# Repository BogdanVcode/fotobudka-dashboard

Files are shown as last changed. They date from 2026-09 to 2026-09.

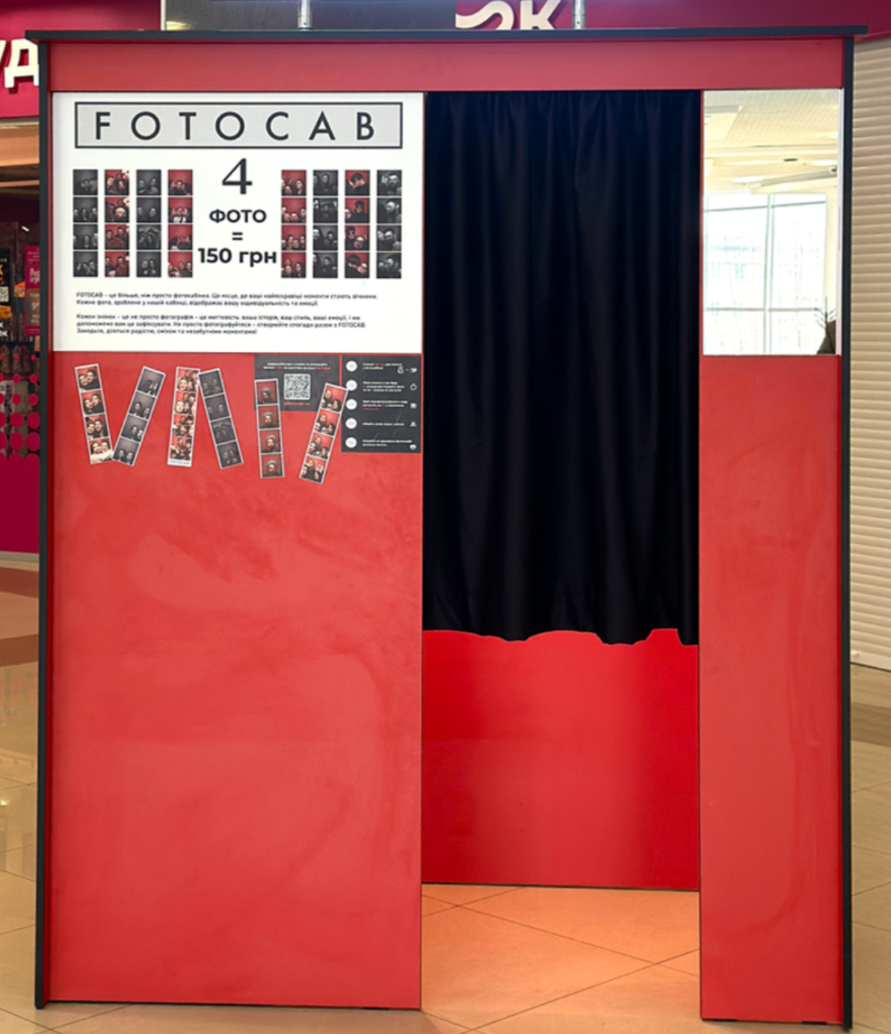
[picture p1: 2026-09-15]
assets/references/03-exterior.png

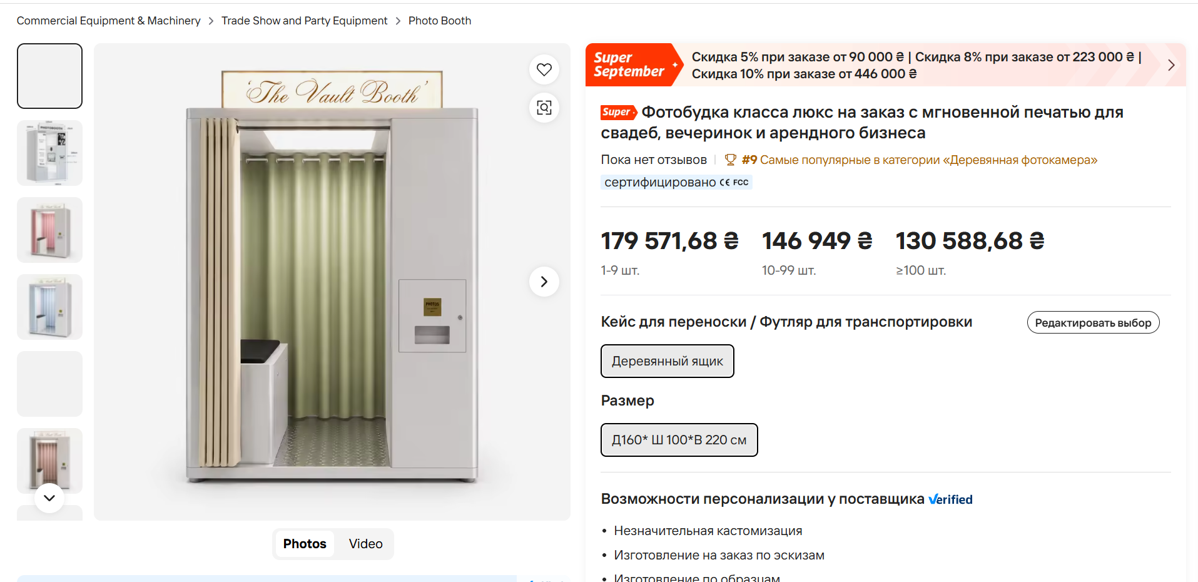
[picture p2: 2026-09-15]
assets/references/02-size.png

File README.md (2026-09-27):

# прототип 1 від чатгпт

Фотокіоск самообслуговування · Славутич.

[Відкрити дашборд](https://bogdanvcode.github.io/fotobudka-dashboard/) · [Інструкція для Claude](CLAUDE.md)

## Запуск

Потрібен Node.js 20+. Зовнішні пакети встановлювати не потрібно.

```sh
npm run build
npm test
npm start
```

Відкрити http://localhost:4173. GitHub Pages публікує корінь main.

Єдиний кошторис: `docs/budget/current.json`. Реєстр покупок: `docs/purchases/2026-09-25.json`. Персональні зміни браузера експортуються у вкладці «Кошторис».

`engineering-source/` та попередні ревізії — історія. Не використовувати старі окремі списки покупок. Поточні файли й обмеження описані в CLAUDE.md. Оригінал Blender і креслення збережені.

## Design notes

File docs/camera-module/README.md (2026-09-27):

# Вертикальний модуль камери · P2

ПК USB → Arduino Nano (USB 5 В), D2 STEP / D3 DIR → ULN2003 → DM556. D4 нижній HOME і D5 верхня межа: два HURON NPN NO через дві PC817/EL817. XL7015: 36 → 12 В для датчиків. Прошивки та фізичних випробувань немає.

CNCPROM: товари, доставка й комісії оплачені; комплект отримано 25.09.2026. Повна витрата 10 116,68 грн.

[Схема](PIN-WIRING.md) · [Актуальні покупки](PIN-PURCHASES.md) · [Інструменти](ASSEMBLY-SHOPPING.md) · [Архів P1](archive/P1-PIN-PURCHASES.md).

3D — умовне компонування двох індуктивних датчиків і мішені; координати їх кріплення не є виробничим кресленням. Прошивки й фізичного тестування немає.

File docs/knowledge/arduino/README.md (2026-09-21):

# Бібліотека знань Arduino: AlexGyver

Додано 20.09.2026. Автор першоджерел — AlexGyver. [Каталог уроків](https://alexgyver.ru/lessons/). Це локальний тематичний покажчик і власні короткі нотатки для фотобудки, а не копія сайту, його платного контенту чи програмна бібліотека, встановлена в Arduino IDE.

Переглянуто структуру каталогу та відкриті матеріали, потрібні для підключення Nano, живлення, GPIO, механічного HOME, Serial і неблокувальних таймерів. Увесь сайт і відеокурс не пройдено. Прямі посилання нижче дозволяють продовжити дослідження без повторного пошуку.

## Навігація

| Тема / першоджерело | Що зберігаємо як знання | Застосування в нашому модулі [C] |
|---|---|---|
| [Початок роботи](https://alexgyver.ru/lessons/ardu-start/) | Підготовка середовища та завантаження скетчу; вступний матеріал | Плата ATmega328P, правильний COM-порт; варіант bootloader перевіряємо на отриманій Nano |
| [Arduino Nano](https://alexgyver.ru/lessons/arduino-nano/) | Позначення D-пінів, живлення, інтерфейси класичної Nano | Не плутати D2 з фізичною ніжкою №2 ATmega; основний pinout звіряємо з Arduino |
| [Підключення модулів](https://alexgyver.ru/lessons/hardware/) | Макетування, контактні гребінки, сигнальні інтерфейси | Піни 2,54 мм — для сигналів усередині нерухомого відсіку |
| [Живлення](https://alexgyver.ru/lessons/arduino-power/) | Полярність, допустима напруга, живлення від USB, окреме живлення навантажень | USB живить Nano і сигнальну частину; S-250-36 живить лише силову частину DM556 |
| [Цифровий вихід](https://alexgyver.ru/lessons/gpio-out/) | GPIO перемикає логічний рівень; потужне навантаження потребує драйвера | D2/D3 → буфер ULN2003 → PUL/DIR; до GPIO не підключати обмотки |
| [Цифровий вхід](https://alexgyver.ru/lessons/gpio-in/) | Вхід не повинен залишатися без визначеного рівня; INPUT_PULLUP | D4 читає NC-контакт HOME; підтягування внутрішнє для першого стенда |
| [Кнопка](https://alexgyver.ru/lessons/button/) | Контакти, підтягування, обробка зміни стану й брязкоту | Наш кінцевик використовує NC, тому логіка натискання відрізняється від прикладу з NO-кнопкою |
| [UART / Serial](https://alexgyver.ru/lessons/uart/) | Апаратний і програмний UART, однакова швидкість на обох кінцях | ПК → USB-UART Nano; D0/D1 залишаємо для Serial, STEP генерується на MCU |
| [Програмний таймер](https://alexgyver.ru/lessons/soft-timer/) | Перевірка різниці часу дозволяє обходитися без блокувальних затримок | Окремі таймери HOME, зв’язку та стабілізації камери; це не готовий генератор STEP |
| [Використання бібліотек](https://alexgyver.ru/lessons/library-using/) | Довідкова сторінка про підключення бібліотек | Версію обраної бібліотеки руху та її розводку пінів зафіксувати під час розробки прошивки |

## Як користуватися знаннями

1. Для загальних понять починати з відповідного уроку.
2. Для чисел, контактів і сумісності переходити до документації **конкретної моделі та ревізії**. Навчальний приклад не підтверджує сумісність нашого комплекту.
3. Проєктні рішення зберігати в MASTER-SPEC і документах модуля, не приписувати їх AlexGyver.
4. Після заміни плати повторно звіряти маркування, роз’єм і рівні сигналів. Відкрита стаття може змінитися.

## Уточнення для нашої схеми

- [C] Спільна земля потрібна між Nano та ULN2003. У запропонованому оптоізольованому інтерфейсі **окрему перемичку Nano GND → DM556 силовий GND не додаємо**. Загальне навчальне правило про GND не означає необхідність обходити оптоізоляцію.
- [C] HIGH на D2 відкриває колектор ULN2003 і створює струм у вході PUL; це не звичайний push-pull вихід 5 В. Треба перевірити напругу/струм оптовходу з реальним USB-живленням і падінням на ULN.
- [C] Розрив NC-кола дає такий самий рівень, як натиснутий HOME. Лише читання HIGH не є доказом знайденого нуля. Потрібна контрольована послідовність відпускання й повторного натискання з тайм-аутами.
- [C] Внутрішнє INPUT_PULLUP — стартовий варіант для короткого кабелю стенда. Якщо на довгому кабелі виникають завади, потрібна окрема ревізія входу з підтягуванням/фільтрацією; не маскувати їх лише великою програмною затримкою.

## Першоджерела для перевірки контактів

- [Arduino Nano, офіційна розпіновка](https://docs.arduino.cc/resources/pinouts/A000005-full-pinout.pdf) [A].
- [TI ULN2003A, datasheet](https://www.ti.com/lit/ds/symlink/uln2003a.pdf), таблиця Pin Functions [A].
- [Схема плати ULN2003 LC Studio від продавця](https://arduino.ua/docs/SCH_StepperDriverULT2003.pdf) [B]; фактична плата може мати іншу ревізію.
- [DM556, інструкція саме з картки CNCPROM](https://storage.ua.prom.st/2369996_drajver_dm556._posibnik_koristuvacha.pdf), с. 4–6, 9 [B]. Це не доказ, що недорогий DM556 є оригінальним Leadshine.

[Нова схема та монтаж](../../camera-module/PIN-WIRING.md) · [Закупівля](../../camera-module/PIN-PURCHASES.md)

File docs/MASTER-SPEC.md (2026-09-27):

<!-- PROTOTYPE-1 -->
# прототип 1 від чатгпт

27.09.2026: актуальний кошторис — docs/budget/current.json; збірка — scripts/build-budget.mjs. Реєстр оплат — docs/purchases/2026-09-25.json. Усі інструменти є; історія витрат збережена. Старі окремі списки архівні. P2 — невипробуваний кандидат з відкритим питанням STEP/DIR. Передача проєкту — CLAUDE.md. Нижче — історичні розділи, що не перевизначають цей блок.
<!-- /PROTOTYPE-1 -->

<!-- P2-CANONICAL-20260921 -->
## Єдина актуальна схема ліфта P2 · комплект CNCPROM отримано

Джерело комплектації та статусів — `camera-module/order.json`, wiringRevision=P2. [Покупки](camera-module/PIN-PURCHASES.md), [схема](camera-module/PIN-WIRING.md). Один NC HOME, його джгут і список P1 перенесено в `camera-module/archive/`; вони не беруть участі в поточному кошторисі. Два HURON NPN NO: D4 HOME, D5 верхня межа через дві PC817/EL817; XL7015 36→12 В. D2/D3 через ULN2003 до DM556; Nano від USB.

CNCPROM №428971860 оплачено й отримано: товари 9 587 грн, доставка 270 грн, комісії 259,68 грн, повна витрата 10 116,68 грн. Загальний factual spent станом на 25.09.2026 — 106 932,34 грн; логістика й комісії — 1 248,67 грн. Master-реєстр покупок — `purchases/2026-09-25.json`; доставка зберігається на рівні замовлення і не дублюється між товарами. Апаратні випробування і прошивка не виконані.

<!-- ASSEMBLY-SHOPPING-20260921 -->
## Інструменти та монтаж · 21.09.2026 · уточнення

[Список і вибір покупки](camera-module/ASSEMBLY-SHOPPING.md), джерело `camera-module/assembly-shopping.json`. Вісім інструментів виключено за рішенням Богдана; решта 3 976 грн до позначок «Позичу». Дашборд зберігає вибір локально та формує замовлення за магазинами. Це план, не куплені товари. DFR0912 відхилено за ціною: залишено дві PC817/EL817 з P2 (144 грн, не дублювати). Bulgin замінено на ETI ESC-SFR.4: пара 192,80 грн плюс кришка, рейка й упори; складові монтажу разом 234 грн без запобіжників. ABS-бокс 300×400×170 з монтажною панеллю за 1 200 грн відкладено до перевірки компонування. Мережева частина, F0, кожух, вентиляція й монтаж залишаються незавершеними. Не оголошувати комплект готовим до ввімкнення.

<!-- PIN-WIRING-P2 -->
## Підключення пінами · P2 · 21.09.2026

[Схема і монтаж](camera-module/PIN-WIRING.md) · [Закупівля у двох основних магазинах](camera-module/PIN-PURCHASES.md) · [Бібліотека Arduino / AlexGyver](knowledge/arduino/README.md). Чинна схема P2: D2 STEP, D3 DIR через ULN2003, D4 нижній HOME, D5 верхня межа. Два NPN NO через дві опторозв’язки; XL7015 знижує 36 до 12 В. Статус CANDIDATE; розводка оптоплат, X2, запобіжники й стенд не перевірені. Закупівля P1 архівна; актуальний order.json та список закупівлі відповідають P2.

<!-- CAMERA-MODULE-700 -->
## Нове ТЗ модуля камери · 20.09.2026

[Інженерний огляд і 3D](camera-module/README.md): TBD45-700 замість попереднього 500 мм для нового вузла. Окреме компонування, не виробничий випуск. Авторську геометрію кабінки не змінено; інтеграція 700 мм і механічне утримання ще не погоджені.

<!-- CURRENT-REVISION-10 -->
# Актуальна ревізія 10 · 17.09.2026

[Модель, кошторис і прибутковість](design/REVISION-10.md). Попередні записи нижче — історія.
<!-- END-CURRENT-10 -->

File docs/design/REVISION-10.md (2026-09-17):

# Ревізія 10 · модель Богдана від 17.09.2026

Джерело: БУДКА.blend. SHA256: 2b8f48152970a00ad30e395a091eca47b85e14f904886c514a4f78d67ea8b577. Усі 73 авторські конструктивні об’єкти збережені: вершини, повороти, Dimensions, нові назви та колекції. Колекція «Каркас» містить 44 профілі 20×20, сумарно 37,561 м. Об’єкт «людина» — масштабний референс, у дашборді не показаний.

## Розміщення

Два принтери DNP DS-RX1HS і Brother HL-L5210DN стоять на авторській деталі «ДСП для принтерів всередині». Їхні нижні площини точно збігаються з верхом полиці. Godox MS200V розміщений ліворуч від камери, якщо дивитися з пуфіка на монітор, спрямований угору. EcoFlow та комп’ютер — в самому низу. Сканер Brother DS-740D — за верхнім вирізом передньої ДСП: авторський об’єкт «Сканер Brother DS-740D White», Dimensions 301×63×45,3 мм, без переміщення. Нижче — авторська кишеня. Напрям подачі та виходу документа і його потрапляння в кишеню потребують перевірки на реальному сканері. Авторський платіжний термінал, камера спостереження, кишені та рифлений лист збережені.

Додано муфту, монтажні опори й маршрути проводів: принтери, сканер, монітор, камера, термінал, камера спостереження, концентратор USB і розподіл живлення. Маршрути схематичні: реальні порти, інтерфейс термінала, кабельний ланцюг і електрична схема залишаються роботою автора електроніки.

## Креслення

Альбом drawings/revision-10/index.html; PDF output/pdf/Фотобудка-10-креслення.pdf. Шість аркушів А1: усі 15 об’єктів ДСП на одному аркуші; усі профілі на окремому; компонування; вирізи; світлові панелі; порядок складання. Сітка меша не використовується як креслення. Для плоских деталей показано контур поверхні, габарити й розміри вирізів.

Передній об’єкт з кишенями має глибину 200,58 мм і є збірним вузлом. Це не плита такої товщини. Дверцята мають 16 мм, консоль — габарит 15,86 мм, верхня похила опалова панель — 5,33 мм. Ці величини не змінені без рішення автора. На реальних плоских матеріалах потрібна деталізація майстром.

## Завдання майстру

Зібрати міцний каркас 20×20 і обшивку ДСП; вмонтувати пуфік, екран, сканер і опалові полікарбонатні панелі; зробити вирізи та приховані кріплення. Зовнішні стінки з’єднати між собою і з каркасом без видимих наскрізних гвинтів. Усередині модуля допускаються технологічні вирізи. Богдан окремо закуповує й робить обладнання, електроніку та ПЗ.

## Кошторис

72 оцінених позицій, сума 392260.24 грн, резерв 10% — 39226.02 грн, загалом 431486.26 грн. Ціни пропозицій, середні орієнтири та резерви на роботи позначені окремо у budget.json. Невідомих цін без оцінки немає; це не договірна ціна.

Каркас: V-Slot 20×20 без покриття Profile Center, 187 грн/м; резерв 7 хлистів по 6 м. 100 комплектів кутника 2028 по 68 грн (кутник + 2 болти + 2 T-гайки). Це запас за кількістю торців, не остаточна схема з’єднань; косі стики і міцність перевіряє майстер. Екран: Elo 2470L 24 дюйми з авторського Blender; 28850 грн — середнє двох пропозицій, не підтвердження наявності.

## Прибутковість

Калькулятор #profit враховує кількість і ціну послуг, витратні матеріали, повторний друк, податки 2026 року, комісію еквайрингу, оренду, електрику та інші витрати. Усі припущення редагуються. Оренда за замовчуванням — максимум 2,5 м² × 250 грн та 3000 грн/місяць. Це сценарій, не отримана пропозиція ТЦ. Податки 2 групи за максимальною ставкою; 3 група без ПДВ — 5% + 1% від повної виручки, плюс ЄСВ. Депозит і грошовий запас збільшують початкові вкладення. Немає додатного залишку — немає строку окупності. Джерела ДПС та оренди наведені на вкладці.

## Перевірка й межі

Перевірено незмінність усіх авторських мешів і Dimensions, опирання принтерів на полицю, розташування спалаху/сканера й нижнього обладнання. Повний розрахунок жорсткості, присадка, вентиляційні зазори й тракти видачі від принтерів до кишень ще не випущені. Габарити камери, ліфта, термінала у файлі автора умовні: не приймати їх як заводські CAD-розміри. productionReleased=false.

## Уточнення моделі о 13:44

Нова авторська модель містить 73 конструктивні меші. Нові назви збережені. Доданий автором прилад названо «Сканер Brother DS-740D White»; додатковий дубль сканера видалено. Два принтери DNP і Brother A4 залишаються доданими на авторській полиці. Прохід у «ДСП перед» — 600 мм між X=−436 та X=164 мм. Рифлений лист: 600×1000×16 мм у Blender; 16 мм — модельний габарит, кошторисний метал 1,5 мм потребує опорної основи. Кишеньковий вузол тепер має глибину 200,58 мм.

## Вхід і розміри вирізів

Прив’язки вирізів X/Y і їхня ширина/висота нанесені на види аркуша 04; окремий аркуш 07 вилучено з альбому. Штора: готова біла 140×200 см, підшити до 181 см, у складках перекриває 70 см. Карниз 100 см з 12 бігунками/гачками, двома стопорами, трьома кронштейнами та кріпленням до підсиленої перемички. Монтаж показано як пропозицію; перевірити кріплення на місці. Резерв: штора 2200 грн + комплект карниза 700 грн; ці позиції вже були у сумі, дубль не додано.

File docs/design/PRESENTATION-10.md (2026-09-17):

# Потрібен майстер зі складання фотокіоска · Славутич

Фотокіоск самообслуговування: людина сідає, обирає послугу на екрані, фотографується й отримує фотографії. Сканер дозволяє сканувати документи та друкувати копії.

Зараз потрібне виготовлення каркаса з алюмінієвого профілю 20×20 та обшивки ДСП: порізка, вирізи, прихований монтаж стінок, вбудований пуфік, кріплення екрана, сканера, кишень і опалових панелей. Усередині модуля допустимі технологічні вирізи.

Богдан — автор проєкту — окремо займається закупівлею обладнання, електронікою і ПЗ. Майстру потрібно перевірити конструкцію, запропонувати кріплення та оцінити складання й монтаж.

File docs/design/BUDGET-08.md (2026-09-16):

# Кошторис авторської моделі

Ціни обладнання з попередньої ревізії збережені в dashboard/budget.js із датами й посиланнями. Ціни не перевірялися повторно в межах імпорту Blender. Матеріали та роботи корпусу необхідно перерахувати після погодження товщини дверцят, плоских панелей, крайки та присадки. Повної нової суми немає; старий підсумок не застосовується до ревізії 08.

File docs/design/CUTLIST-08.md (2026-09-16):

# Авторські панелі · 08

Розміри взяті з Dimensions. Товщини й присадку погодити до замовлення.

| ID | Об’єкт | Dimensions, мм |
|---|---|---|
| B044 | ЗАД | 1072.00 × 2200.00 × 16.00 |
| B045 | верх | 1800.00 × 1200.00 × 16.00 |
| B046 | перед | 1072.00 × 2200.00 × 16.00 |
| B047 | ліво | 1640.00 × 2200.00 × 16.00 |
| B048 | підлога | 1672.00 × 1072.00 × 16.00 |
| B049 | ЗАД.001 | 594.01 × 1219.06 × 8.87 |
| B050 | ДСП перед | 1640.00 × 2200.00 × 16.00 |
| B057 | дсп1 | 1040.00 × 500.00 × 16.00 |
| B058 | дсп1.001 | 1000.00 × 400.00 × 16.00 |
| B059 | дсп1.002 | 1000.00 × 400.00 × 16.00 |
| B060 | дсп1.003 | 400.00 × 400.00 × 16.00 |
| B061 | дсп1.004 | 400.00 × 400.00 × 16.00 |
| B062 | дсп2 для монітора | 1040.00 × 498.21 × 15.86 |

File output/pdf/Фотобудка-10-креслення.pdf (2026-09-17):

# 01 · Усі деталі ДСП на одному аркуші

Суцільні контури актуальних деталей. Показані габарити, товщина та основні розміри вирізів; сітка меша прихована.

ФОТОБУДКА СЛАВУТИЧ · 10 · 17.09.2026 · мм · А1 · не масштабувати з екрана | Автор: Богдан · комплект для узгодження з майстром

B051 · ДСП ЗАД

Dimensions: 1072 × 2200 × 16 мм

1072

2200

181 | 710 | 181
| | 187

1210

803

Товщина / габарит торця: 16 мм

B052 · ДСП верх

Dimensions: 1800 × 1200 × 16 мм

1800

1200

Товщина / габарит торця: 16 мм

B053 · ДСП перед.001

Dimensions: 1072 × 2200 × 16 мм

1072

2200

Товщина / габарит торця: 16 мм

B054 · ДСП ліво

Dimensions: 1640 × 2200 × 16 мм

1640

2200

Товщина / габарит торця: 16 мм

B055 · підлога Dimensions: 1672 × 1072 × 16 мм | B056 · ДСП перед Dimensions: 1640 × 2200 × 16 мм | B059 · ЗАД сервісний люк Dimensions: 700 × 1200 × 16 мм 700 | B065 · дсп перед з віконцями для друкованих матеріалів Dimensions: 1040 × 500 × 200.58 мм
| | 280.01 15.8

1672

1072

418 | 418 | 418 | 209 | 209

Товщина / габарит торця: 16 мм

1640

2200

600

1904.19

Товщина / габарит торця: 16 мм

1200

Товщина / габарит торця: 16 мм

1040

500

Вузол з кишенями; 200.58 мм — глибина.

B066 · ДСП пуфік лицьова

Dimensions: 1000 × 400 × 16 мм

1000

400

Товщина / габарит торця: 16 мм

B067 · ДСП пуфік задня стінка

Dimensions: 1000 × 400 × 16 мм

1000

400

Товщина / габарит торця: 16 мм

B068 · ДСП пуфік ліво

Dimensions: 400 × 400 × 16 мм

400

400

Товщина / габарит торця: 16 мм

B069 · ДСП пуфік право

Dimensions: 400 × 400 × 16 мм

400

400

Товщина / габарит торця: 16 мм

B070 · дсп2 для монітора Dimensions: 1040 × 498.21 × 15.86 мм | B072 · ДСП для принтерів всередині Dimensions: 1000 × 400 × 16 мм | B073 · ДСП для ліфта камери Dimensions: 150 × 300 × 16 мм
| | 92.28 74.52

1040

498.21

242.68 | 553.7 | 243.62

165.7

8.88

156.83

Товщина / габарит торця: 15.86 мм

1000

400

Товщина / габарит торця: 16 мм

150

300

Товщина / габарит торця: 16 мм

# 02 · Усі деталі каркаса: алюмінієвий профіль 20×20

Колекція «Каркас» у Blender. Кожен Cube — окремий профіль. Довжина за Dimensions, не за світовим габаритом.

B007 · Cube.005 | L = 1000 мм

20 × 20 мм

B008 · Cube.006 | L = 1000 мм

20 × 20 мм

B009 · Cube.007 | L = 1000 мм

20 × 20 мм

B010 · Cube.008 | L = 2200 мм

20 × 20 мм

B011 · Cube.009 | L = 2200 мм

20 × 20 мм

B012 · Cube.011 | L = 280 мм

20 × 20 мм

B013 · Cube.012 | L = 280 мм

20 × 20 мм

B014 · Cube.013 | L = 1600 мм

20 × 20 мм

B015 · Cube.021 | L = 500 мм

20 × 20 мм

B016 · Cube.023 | L = 1000 мм

20 × 20 мм

B017 · Cube.024 | L = 1000 мм

20 × 20 мм

B018 · Cube.025 | L = 1600 мм

20 × 20 мм

B019 · Cube.015 | L = 1900 мм

20 × 20 мм

B020 · Cube.018 | L = 339.58 мм

20 × 20 мм

B021 · Cube.022 | L = 220.42 мм

20 × 20 мм

B022 · Cube.026 | L = 339.58 мм

20 × 20 мм

B023 · Cube.028 | L = 339.58 мм

20 × 20 мм

B024 · Cube.029 | L = 484.87 мм

20 × 20 мм

B025 · Cube.030 | L = 1000 мм

20 × 20 мм

B026 · Cube.031 | L = 1000 мм

20 × 20 мм

B027 · Cube.020 | L = 580 мм

20 × 20 мм

B028 · Cube.032 | L = 1600 мм

20 × 20 мм

B029 · Cube.034 | L = 500 мм

20 × 20 мм

B030 · Cube.035 | L = 1900 мм

20 × 20 мм

B031 · Cube.036 | L = 339.58 мм

20 × 20 мм

B032 · Cube.037 | L = 220.42 мм

20 × 20 мм

B033 · Cube.038 | L = 339.58 мм

20 × 20 мм

B034 · Cube.039 | L = 339.58 мм

20 × 20 мм

B035 · Cube.040 | L = 484.87 мм

20 × 20 мм

B036 · Cube.041 | L = 580 мм

20 × 20 мм

B037 · Cube.042 | L = 1600 мм

20 × 20 мм

B038 · Cube.014 | L = 1000 мм

20 × 20 мм

B039 · Cube.045 | L = 1000 мм

20 × 20 мм

B040 · Cube.046 | L = 1000 мм

20 × 20 мм

B041 · Cube.001 | L = 1000 мм

20 × 20 мм

B042 · Cube.002 | L = 1000 мм

20 × 20 мм

B043 · Cube.016 | L = 1000 мм

20 × 20 мм

B044 · Cube.017 | L = 1000 мм

20 × 20 мм

B045 · Cube.044 | L = 572.26 мм

20 × 20 мм

B046 · Cube.049 | L = 572.26 мм

20 × 20 мм

B047 · Cube.003 | L = 484.87 мм

20 × 20 мм

B048 · Cube.004 | L = 484.87 мм

20 × 20 мм

B049 · Cube.019 | L = 339.58 мм

20 × 20 мм

B050 · Cube.027 | L = 339.58 мм

20 × 20 мм

44 деталей · загальна довжина: 37.56 м. Торці похилих елементів різати за кутом їхніх стиків; кріплення узгоджує майстер.

# 03 · Загальне компонування та висоти

Напрямок «ліворуч / праворуч» визначено з місця людини, яка дивиться на монітор.

## Вид збоку: лавка → модуль

1672

## Вид на модуль: сканер у верхньому вирізі

1074.58

Полиця принтерів: верх 524 мм від авторської площини Z=0. Принтери стоять на ній; EcoFlow і ПК — на нижній основі Z=8.

Кишеня A4 ліворуч, фото по центру — авторська геометрія. Тракти видачі від принтерів до кишень ще потрібно виготовити й перевірити.

Прохід фасаду: 600 мм між X = −436 та +164 мм. Рифлений лист: 600 × 1000 мм (Dimensions автора).

# 04 · Вирізи, кишеньки й сервісний люк

Збільшені головні види. Передній вузол має кишені; їхня глибина не є товщиною ДСП. Вентиляційні прорізи збережені з моделі.

B059 · ЗАД сервісний люк

Dimensions: 700 × 1200 × 16 мм

700

1200

ВИРІЗИ: X / Y від нижнього лівого кута; ширина × висота

1

190.91

28.57

1: X 487.88

1: Y 1142.86

1. Ліворуч 487.88; знизу 1142.86; виріз 190.91 × 28.57 мм

2

190.91

28.57

2: X 487.88

2: Y 1085.71

2. Ліворуч 487.88; знизу 1085.71; виріз 190.91 × 28.57 мм

3

190.91

28.57

3: X 487.88

3: Y 1028.57

3. Ліворуч 487.88; знизу 1028.57; виріз 190.91 × 28.57 мм

4

21.21

28.57

4: X 657.58

4: Y 628.57

4. Ліворуч 657.58; знизу 628.57; виріз 21.21 × 28.57 мм

5

190.91

28.57

5: X 487.88

5: Y 142.86

5. Ліворуч 487.88; знизу 142.86; виріз 190.91 × 28.57 мм

6

190.91

28.57

6: X 487.88

6: Y 85.71

6. Ліворуч 487.88; знизу 85.71; виріз 190.91 × 28.57 мм

7

190.91

28.57

7: X 487.88

7: Y 28.57

7. Ліворуч 487.88; знизу 28.57; виріз 190.91 × 28.57 мм

B065 · дсп перед з віконцями для друкованих матеріалів

Dimensions: 1040 × 500 × 200.58 мм

1040

500

ВИРІЗИ: X / Y від нижнього лівого кута; ширина × висота

1

244.71

35.71

1: X 61.18

1: Y 428.57

1. Ліворуч 61.18; знизу 428.57; виріз 244.71 × 35.71 мм

2

244.71

107.14

2: X 61.18

2: Y 107.14

2. Ліворуч 61.18; знизу 107.14; виріз 244.71 × 107.14 мм

3

183.53

71.43

3: X 428.24

3: Y 107.14

3. Ліворуч 428.24; знизу 107.14; виріз 183.53 × 71.43 мм

4

244.71

35.71

4: X 734.12

4: Y 107.14

4. Ліворуч 734.12; знизу 107.14; виріз 244.71 × 35.71 мм

B070 · дсп2 для монітора

Dimensions: 1040 × 498.21 × 15.86 мм

1040

498.21

ВИРІЗИ: X / Y від нижнього лівого кута; ширина × висота

1

553.7

331.4

1: X 242.68

1: Y 74.52

1. Ліворуч 242.68; знизу 74.52; виріз 553.7 × 331.4 мм

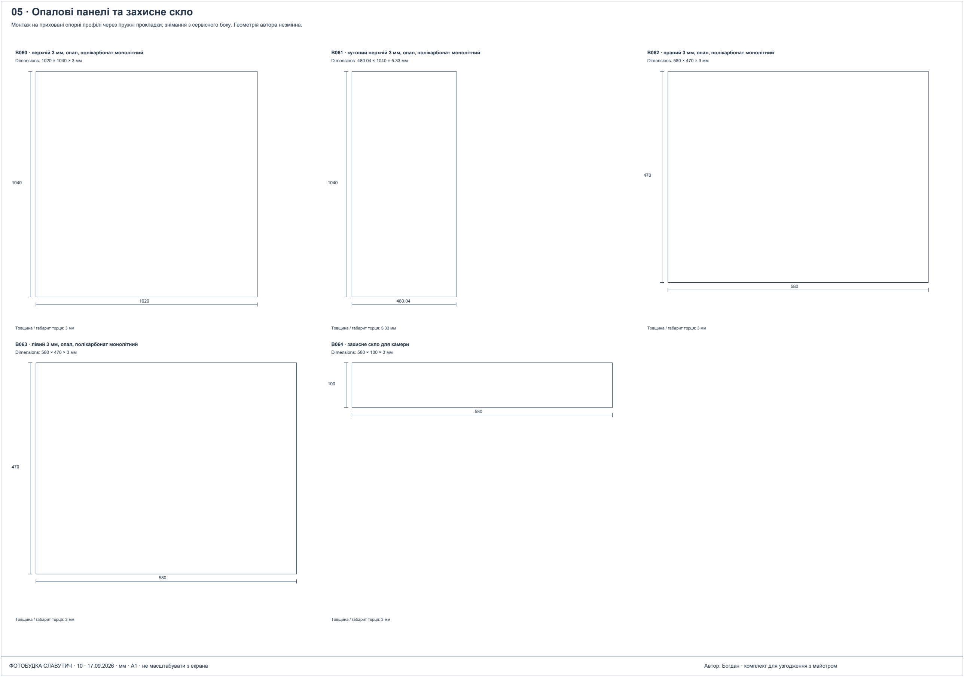
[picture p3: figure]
05 · Опалові панелі та захисне скло; Dimensions: 1020 × 1040 × 3 мм; Товщина / габарит торця: 3 мм; Dimensions: 480.04 × 1040 × 5.33 мм; Товщина / габарит торця: 5.33 мм; Dimensions: 580 × 470 × 3 мм; B064 · захисне скло для камери; Dimensions: 580 × 100 × 3 мм

Монтаж на приховані опорні профілі через пружні прокладки; знімання з сервісного боку. Геометрія автора незмінна.

B060 · верхній 3 мм, опал, полікарбонат монолітний

B061 · кутовий верхній 3 мм, опал, полікарбонат монолітний

B062 · правий 3 мм, опал, полікарбонат монолітний

B063 · лівий 3 мм, опал, полікарбонат монолітний

# 06 · Завдання майстру: складання та прихований монтаж

Видимі зовнішні площини без наскрізних головок гвинтів. Спосіб прихованого кріплення узгодити перед свердлінням.

# 1. Перевірка заготовок

Звірити відомості ДСП і профілю з Blender. Передню деталь з кишенями деталізувати як збірний вузол.

# 2. Каркас 20×20

Виставити основу, стійки та перемички. Перевірити діагоналі й жорсткість. З’єднання розміщувати зсередини.

# 3. Пуфік і полиці

Закріпити пуфік у каркасі, опору сидіння й авторську полицю принтерів; перевірити навантаження.

# 4. Обшивка ДСП

З’єднати стінки прихованими стяжками та закріпити до каркаса внутрішніми кронштейнами. Погодити крайку й зазори.

# 5. Екран, сканер і опалові панелі

Виконати вирізи, знімні кріплення екрана, панелей та сканера. Усередині модуля допустимі технологічні вирізи.

# 6. Сервіс і кишеньки

Забезпечити доступ до принтерів, ПК і EcoFlow. Узгодити відкривання люка й вихід паперу в обидві кишені.

# 7. Кабелі й приймання

Передбачити муфти та місця для фіксації кабелів. Перевірити гострі краї, міцність і можливість обслуговування.

# Відповідальність автора

Богдан окремо закуповує обладнання, виконує електроніку та програмне забезпечення. Потрібна допомога зі складанням корпусу.

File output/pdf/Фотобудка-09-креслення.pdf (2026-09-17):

# 01 · Усі деталі ДСП на одному аркуші

Суцільні контури актуальних деталей. Показані габарити, товщина та основні розміри вирізів; сітка меша прихована.

ФОТОБУДКА СЛАВУТИЧ · 09 · 17.09.2026 · мм · А1 · не масштабувати з екрана | Автор: Богдан · комплект для узгодження з майстром
B050 · ЗАД Dimensions: 1072 × 2200 × 16 мм | B051 · верх Dimensions: 1800 × 1200 × 16 мм | B052 · перед Dimensions: 1072 × 2200 × 16 мм | B053 · ліво Dimensions: 1640 × 2200 × 16 мм
| | 862.59 111.88

1072

2200

237.42 | 597.16 | 237.42

1225.53

Товщина / габарит торця: 16 мм

1800

1200

Товщина / габарит торця: 16 мм

1072

2200

Товщина / габарит торця: 16 мм

1640

2200

Товщина / габарит торця: 16 мм

B054 · підлога Dimensions: 1672 × 1072 × 16 мм | B055 · ЗАД. сервісний люк Dimensions: 594.01 × 1219.06 × 8.87 мм | B056 · ДСП перед Dimensions: 1640 × 2200 × 16 мм | B064 · дсп перед з віконцями для друкованих матеріалів Dimensions: 1040 × 500 × 162.28 мм
| | 280.01 15.8

1672

1072

418 | 418 | 418 | 209 | 209

Товщина / габарит торця: 16 мм

594.01

1219.06

297.01 137.31137.31 22.38

Товщина / габарит торця: 8.87 мм

1640

2200

419.83 584.17 11.99 623.89

1904.19

Товщина / габарит торця: 16 мм

1040

500

Об’ємний вузол з кишенями; 162 мм — глибина.

B065 · ДСП пуфік лицьова

Dimensions: 1000 × 400 × 16 мм

1000

400

Товщина / габарит торця: 16 мм

B066 · ДСП пуфік задня стінка

Dimensions: 1000 × 400 × 16 мм

1000

400

Товщина / габарит торця: 16 мм

B067 · ДСП пуфік ліво

Dimensions: 400 × 400 × 16 мм

400

400

Товщина / габарит торця: 16 мм

B068 · ДСП пуфік право

Dimensions: 400 × 400 × 16 мм

400

400

Товщина / габарит торця: 16 мм

B069 · дсп2 для монітора Dimensions: 1040 × 498.21 × 15.86 мм | B071 · ДСП для принтерів всередині Dimensions: 1000 × 400 × 16 мм | B072 · ДСП для ліфта камери Dimensions: 150 × 300 × 16 мм
| | 92.28 74.52

1040

498.21

242.68 | 553.7 | 243.62

165.7

8.88

156.83

Товщина / габарит торця: 15.86 мм

1000

400

Товщина / габарит торця: 16 мм

150

300

Товщина / габарит торця: 16 мм

# 02 · Усі деталі каркаса: алюмінієвий профіль 20×20

Колекція «Каркас» у Blender. Кожен Cube — окремий профіль. Довжина за Dimensions, не за світовим габаритом.

B006 · Cube.005 | L = 1000 мм

20 × 20 мм

B007 · Cube.006 | L = 1000 мм

20 × 20 мм

B008 · Cube.007 | L = 1000 мм

20 × 20 мм

B009 · Cube.008 | L = 2200 мм

20 × 20 мм

B010 · Cube.009 | L = 2200 мм

20 × 20 мм

B011 · Cube.011 | L = 280 мм

20 × 20 мм

B012 · Cube.012 | L = 280 мм

20 × 20 мм

B013 · Cube.013 | L = 1600 мм

20 × 20 мм

B014 · Cube.021 | L = 500 мм

20 × 20 мм

B015 · Cube.023 | L = 1000 мм

20 × 20 мм

B016 · Cube.024 | L = 1000 мм

20 × 20 мм

B017 · Cube.025 | L = 1600 мм

20 × 20 мм

B018 · Cube.015 | L = 1900 мм

20 × 20 мм

B019 · Cube.018 | L = 339.58 мм

20 × 20 мм

B020 · Cube.022 | L = 220.42 мм

20 × 20 мм

B021 · Cube.026 | L = 339.58 мм

20 × 20 мм

B022 · Cube.028 | L = 339.58 мм

20 × 20 мм

B023 · Cube.029 | L = 484.87 мм

20 × 20 мм

B024 · Cube.030 | L = 1000 мм

20 × 20 мм

B025 · Cube.031 | L = 1000 мм

20 × 20 мм

B026 · Cube.020 | L = 580 мм

20 × 20 мм

B027 · Cube.032 | L = 1600 мм

20 × 20 мм

B028 · Cube.034 | L = 500 мм

20 × 20 мм

B029 · Cube.035 | L = 1900 мм

20 × 20 мм

B030 · Cube.036 | L = 339.58 мм

20 × 20 мм

B031 · Cube.037 | L = 220.42 мм

20 × 20 мм

B032 · Cube.038 | L = 339.58 мм

20 × 20 мм

B033 · Cube.039 | L = 339.58 мм

20 × 20 мм

B034 · Cube.040 | L = 484.87 мм

20 × 20 мм

B035 · Cube.041 | L = 580 мм

20 × 20 мм

B036 · Cube.042 | L = 1600 мм

20 × 20 мм

B037 · Cube.014 | L = 1000 мм

20 × 20 мм

B038 · Cube.045 | L = 1000 мм

20 × 20 мм

B039 · Cube.046 | L = 1000 мм

20 × 20 мм

B040 · Cube.001 | L = 1000 мм

20 × 20 мм

B041 · Cube.002 | L = 1000 мм

20 × 20 мм

B042 · Cube.016 | L = 1000 мм

20 × 20 мм

B043 · Cube.017 | L = 1000 мм

20 × 20 мм

B044 · Cube.044 | L = 572.26 мм

20 × 20 мм

B045 · Cube.049 | L = 572.26 мм

20 × 20 мм

B046 · Cube.003 | L = 484.87 мм

20 × 20 мм

B047 · Cube.004 | L = 484.87 мм

20 × 20 мм

B048 · Cube.019 | L = 339.58 мм

20 × 20 мм

B049 · Cube.027 | L = 339.58 мм

20 × 20 мм

44 деталей · загальна довжина: 37.56 м. Торці похилих елементів різати за кутом їхніх стиків; кріплення узгоджує майстер.

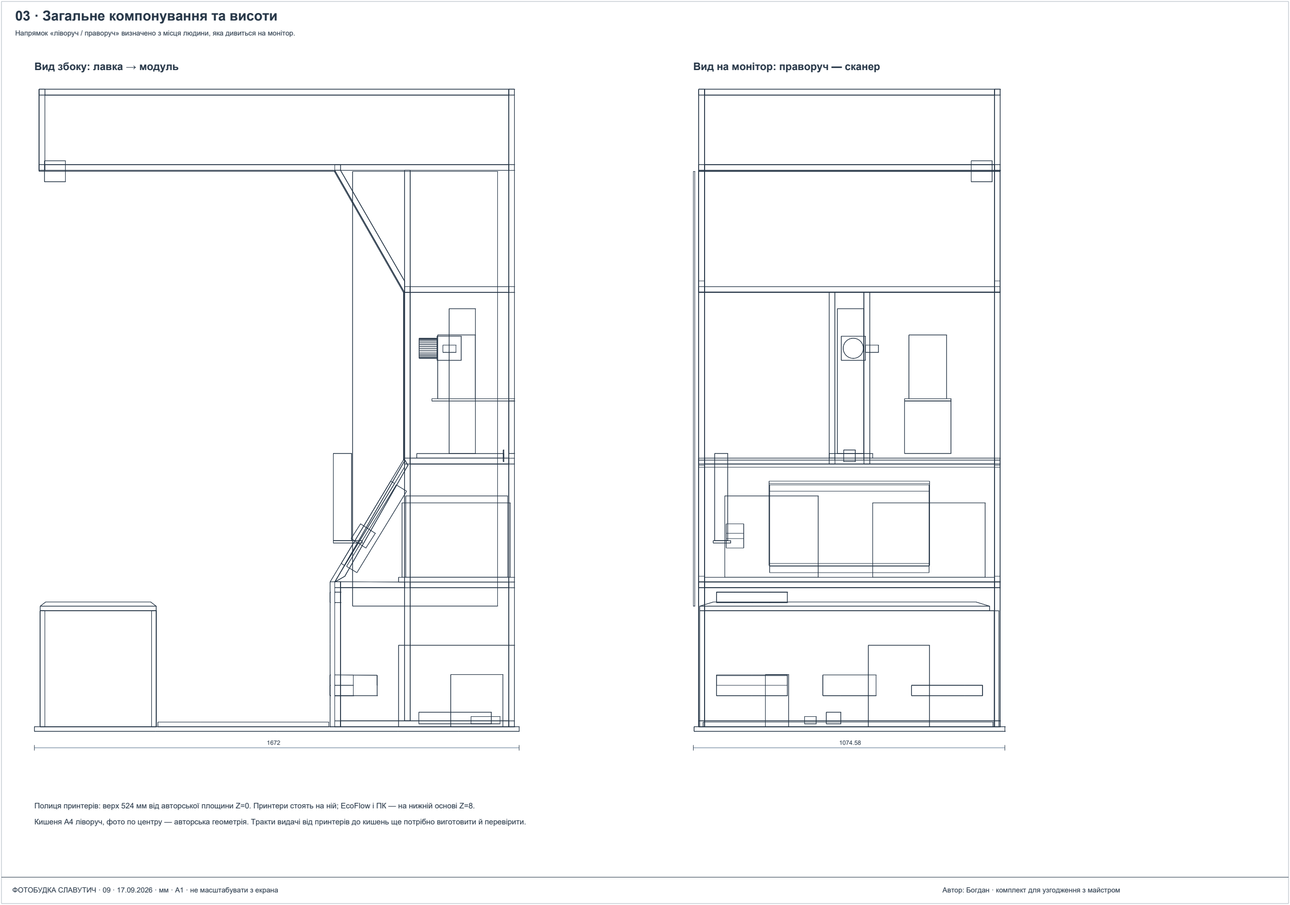
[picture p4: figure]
03 · Загальне компонування та висоти; Вид збоку: лавка → модуль; Вид на монітор: праворуч — сканер

Напрямок «ліворуч / праворуч» визначено з місця людини, яка дивиться на монітор.

Полиця принтерів: верх 524 мм від авторської площини Z=0. Принтери стоять на ній; EcoFlow і ПК — на нижній основі Z=8.

Кишеня A4 ліворуч, фото по центру — авторська геометрія. Тракти видачі від принтерів до кишень ще потрібно виготовити й перевірити.

# 04 · Вирізи, кишеньки й сервісний люк

Збільшені головні види. Передній вузол має кишені; їхня глибина не є товщиною ДСП. Вентиляційні прорізи збережені з моделі.

B055 · ЗАД. сервісний люк

Dimensions: 594.01 × 1219.06 × 8.87 мм

594.01

1219.06

297.01 | 137.31 | 137.31 | 22.38

Товщина / габарит торця: 8.87 мм

ВИРІЗИ: X / Y від нижнього лівого кута; ширина × висота

1. X 434.32 / Y 108.84; 137.31 × 21.77 мм
2. X 434.32 / Y 1175.52; 137.31 × 21.77 мм
3. X 434.32 / Y 1044.91; 137.31 × 21.77 мм
4. X 434.32 / Y 1088.44; 137.31 × 21.77 мм
5. X 434.32 / Y 1131.98; 137.31 × 21.77 мм
6. X 434.32 / Y 65.31; 137.31 × 21.77 мм
7. X 434.32 / Y 21.77; 137.31 × 21.77 мм

B064 · дсп перед з віконцями для друкованих матеріалів

Dimensions: 1040 × 500 × 162.28 мм

1040

500

Об’ємний вузол з кишенями; 162 мм — глибина.

ВИРІЗИ: X / Y від нижнього лівого кута; ширина × висота

1. X 61.18 / Y 107.14; 244.71 × 71.43 мм
2. X 428.24 / Y 107.14; 183.53 × 71.43 мм
3. X 61.18 / Y 428.57; 244.71 × 35.71 мм
4. X 734.12 / Y 107.14; 244.71 × 35.71 мм

B069 · дсп2 для монітора

Dimensions: 1040 × 498.21 × 15.86 мм

1040

498.21

242.68 | 553.7 | 243.62

74.52

165.7

8.88

156.83

92.28

Товщина / габарит торця: 15.86 мм

ВИРІЗИ: X / Y від нижнього лівого кута; ширина × висота

1. X 242.68 / Y 74.52; 553.7 × 331.4 мм

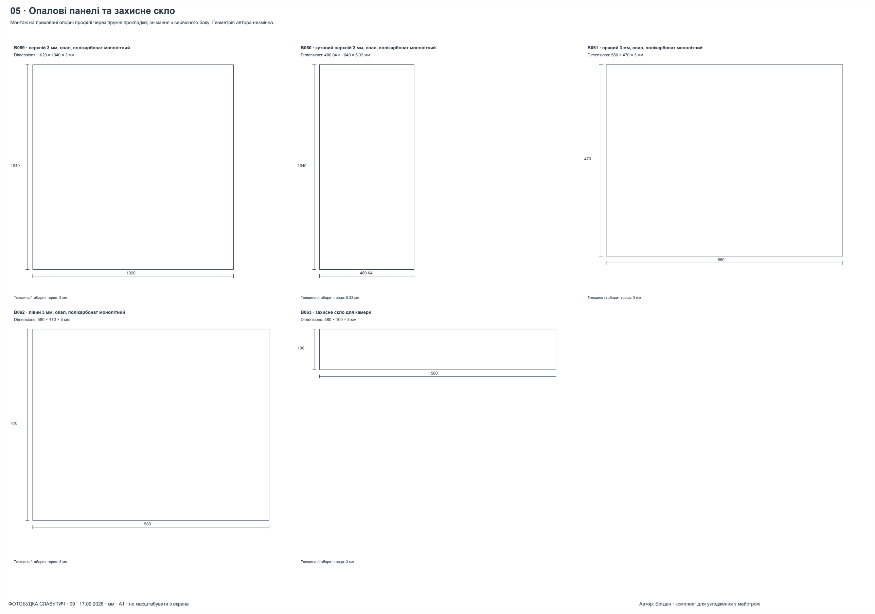
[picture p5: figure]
05 · Опалові панелі та захисне скло; Dimensions: 1020 × 1040 × 3 мм; Товщина / габарит торця: 3 мм; Dimensions: 480.04 × 1040 × 5.33 мм; Товщина / габарит торця: 5.33 мм; Dimensions: 580 × 470 × 3 мм; B063 · захисне скло для камери; Dimensions: 580 × 100 × 3 мм

Монтаж на приховані опорні профілі через пружні прокладки; знімання з сервісного боку. Геометрія автора незмінна.

B059 · верхній 3 мм, опал, полікарбонат монолітний

B060 · кутовий верхній 3 мм, опал, полікарбонат монолітний

B061 · правий 3 мм, опал, полікарбонат монолітний

B062 · лівий 3 мм, опал, полікарбонат монолітний

# 06 · Завдання майстру: складання та прихований монтаж

Видимі зовнішні площини без наскрізних головок гвинтів. Спосіб прихованого кріплення узгодити перед свердлінням.

# 1. Перевірка заготовок

Звірити відомості ДСП і профілю з Blender. Передню деталь з кишенями деталізувати як збірний вузол.

# 2. Каркас 20×20

Виставити основу, стійки та перемички. Перевірити діагоналі й жорсткість. З’єднання розміщувати зсередини.

# 3. Пуфік і полиці

Закріпити пуфік у каркасі, опору сидіння й авторську полицю принтерів; перевірити навантаження.

# 4. Обшивка ДСП

З’єднати стінки прихованими стяжками та закріпити до каркаса внутрішніми кронштейнами. Погодити крайку й зазори.

# 5. Екран, сканер і опалові панелі

Виконати вирізи, знімні кріплення екрана, панелей та сканера. Усередині модуля допустимі технологічні вирізи.

# 6. Сервіс і кишеньки

Забезпечити доступ до принтерів, ПК і EcoFlow. Узгодити відкривання люка й вихід паперу в обидві кишені.

# 7. Кабелі й приймання

Передбачити муфти та місця для фіксації кабелів. Перевірити гострі краї, міцність і можливість обслуговування.

# Відповідальність автора

Богдан окремо закуповує обладнання, виконує електроніку та програмне забезпечення. Потрібна допомога зі складанням корпусу.

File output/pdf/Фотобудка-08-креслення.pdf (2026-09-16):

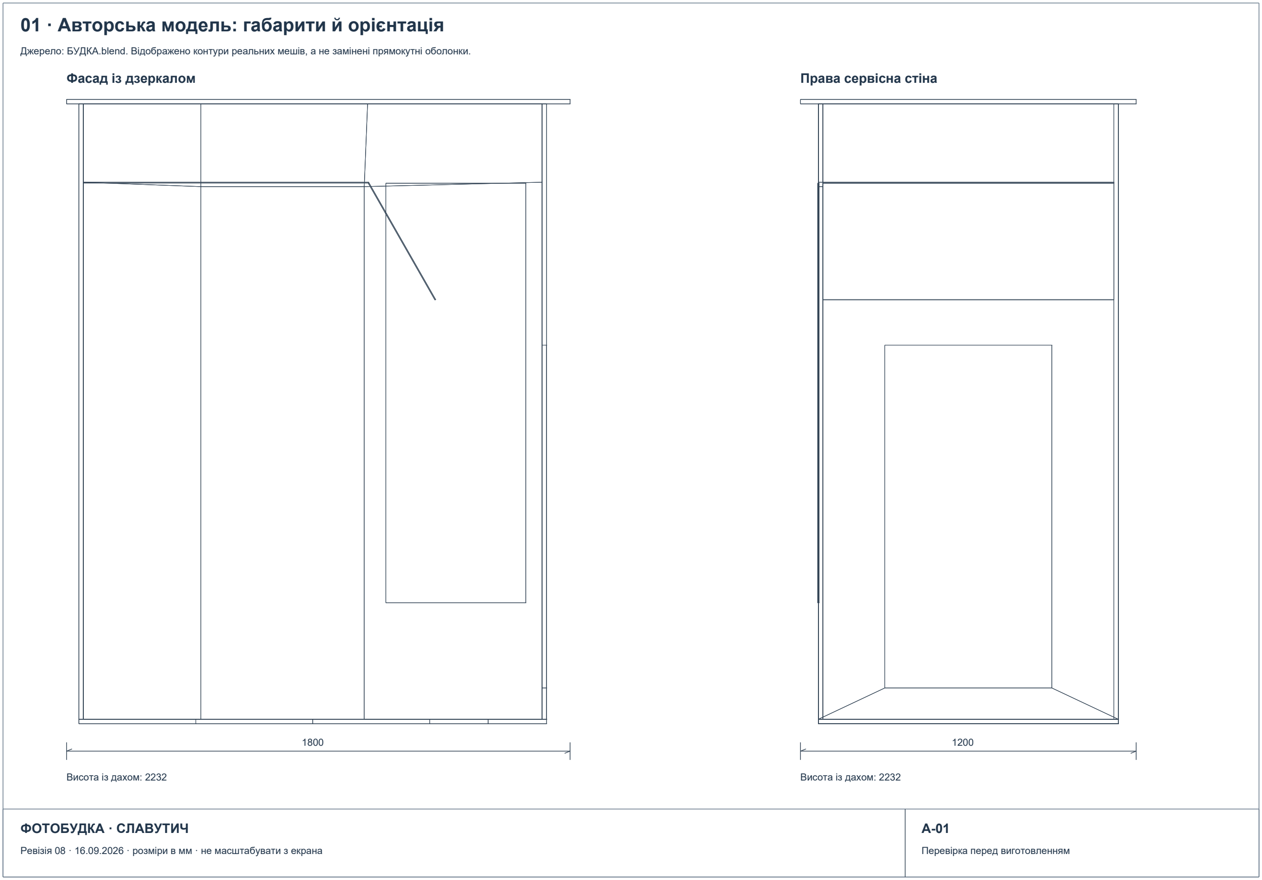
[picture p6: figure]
ФОТОБУДКА · СЛАВУТИЧ; Перевірка перед виготовленням; Фасад із дзеркалом; Висота із дахом: 2232; Права сервісна стіна

# 01 · Авторська модель: габарити й орієнтація

Джерело: БУДКА.blend. Відображено контури реальних мешів, а не замінені прямокутні оболонки.

Ревізія 08 · 16.09.2026 · розміри в мм · не масштабувати з екрана

# 02 · Послідовність складання й контроль

Спочатку перевірка деталей, потім каркас і внутрішні вузли, після цього обшивка.

A-02

## 1. Звірити авторські панелі

Звірити Dimensions із відомістю. Дверцята 8,87 мм та похилі плити перевірити до замовлення матеріалу.

## 2. Зібрати нижню раму й стійки

Виставити прямокутність, однакові діагоналі та вертикальність. Присадка силових вузлів потребує узгодження.

## 3. Приміряти полиці з реальним обладнанням

Перевірити завантаження паперу, відкриття кришок, виймання принтерів і простір для кабельних роз’ємів.

## 4. Встановити ліфт і вертикальну камеру

Перевірити весь хід без контакту з панелями. Переднє скло та адаптери не повинні торкатися каркаса.

## 5. Обшивка й сервісні дверцята

Не дублювати боковини модуля. Петлі й замок розмітити за паспортом фактично придбаної фурнітури.

## 6. Опалові панелі й захисне вікно

Притиск через пружні прокладки. Не свердлити оптичне скло. Передбачити знімання для обслуговування.

## 7. Лавка, м’яке сидіння, шторка

Перевірити опирання сидіння, доступ до речей і ширину проходу. Випробувати посадку та дотягування до екрана.

## 8. Приймання до запуску

Перевірити силові з’єднання, електрозахист, вентиляцію, повний хід ліфта, світло та всі тракти друку.

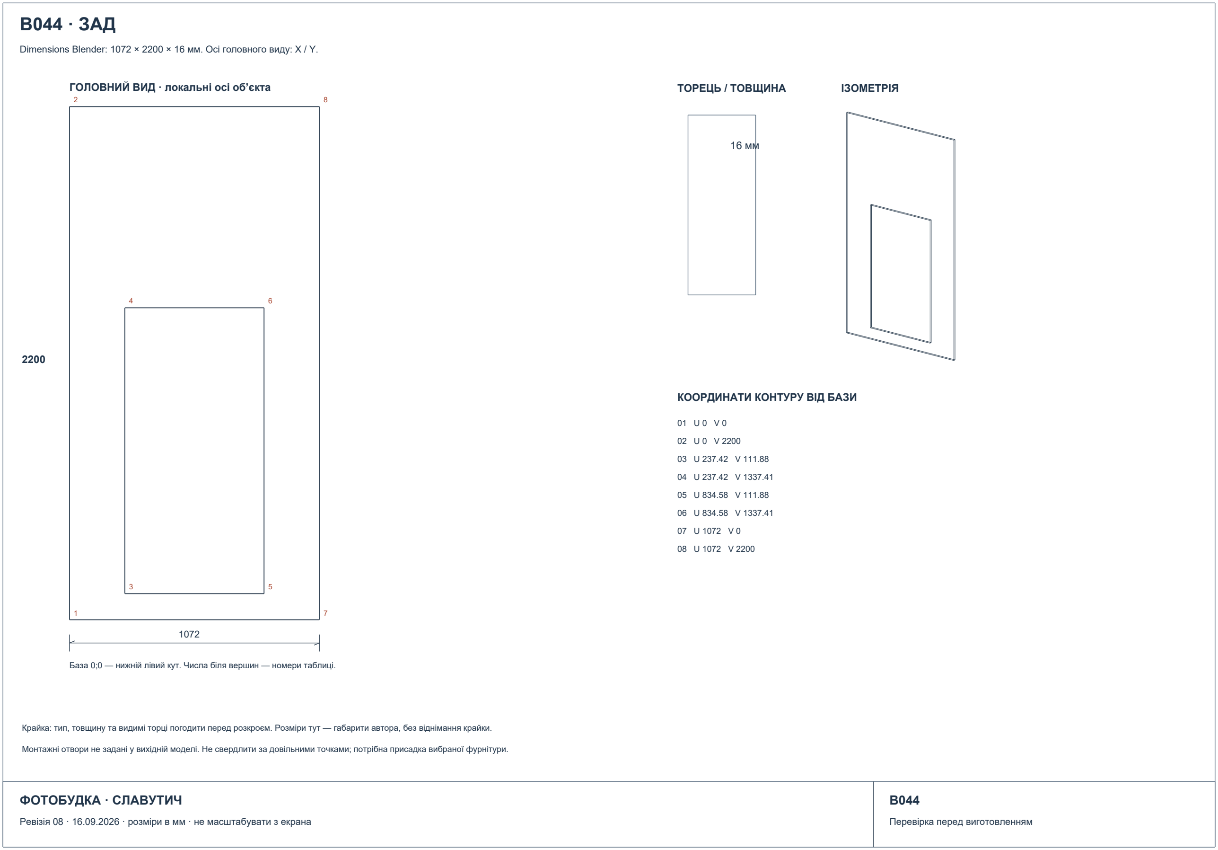
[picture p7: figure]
B044 · ЗАД; ГОЛОВНИЙ ВИД · локальні осі об’єкта; ТОРЕЦЬ / ТОВЩИНА; ІЗОМЕТРІЯ; КООРДИНАТИ КОНТУРУ ВІД БАЗИ

Dimensions Blender: 1072 × 2200 × 16 мм. Осі головного виду: X / Y.

База 0;0 — нижній лівий кут. Числа біля вершин — номери таблиці.

Крайка: тип, товщину та видимі торці погодити перед розкроєм. Розміри тут — габарити автора, без віднімання крайки.

Монтажні отвори не задані у вихідній моделі. Не свердлити за довільними точками; потрібна присадка вибраної фурнітури.

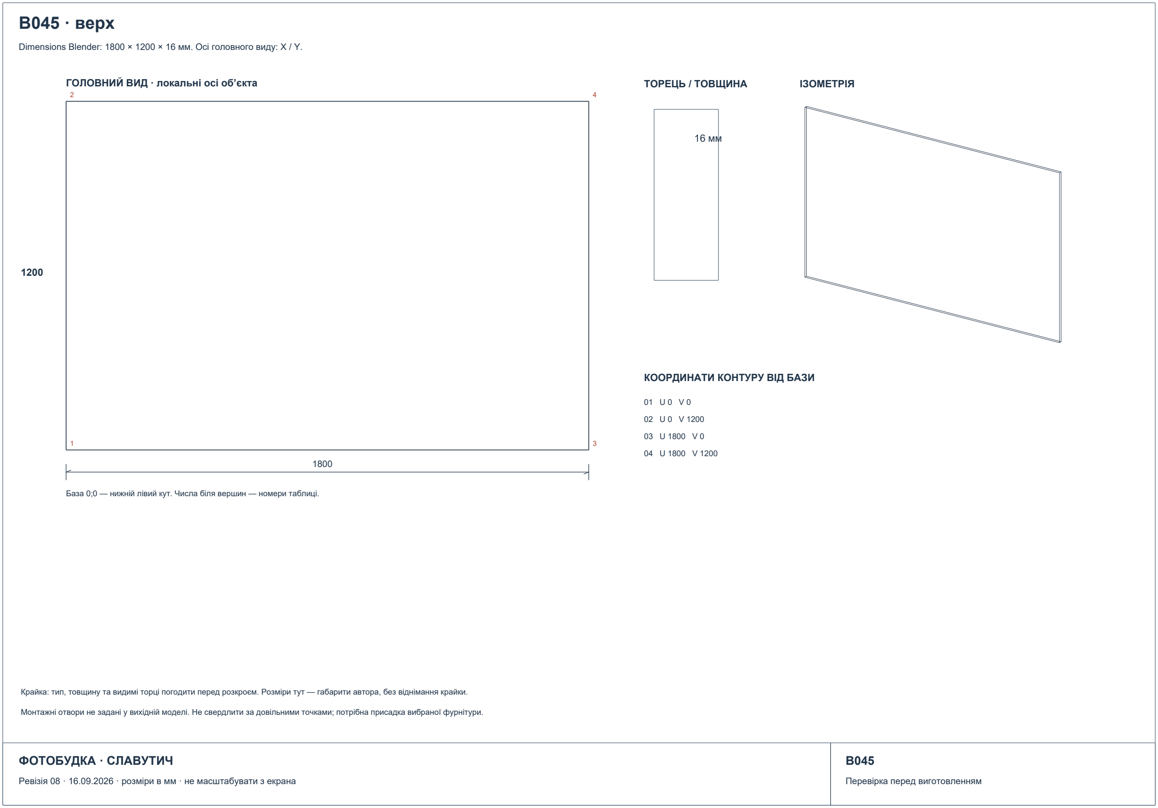
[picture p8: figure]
B045 · верх; ГОЛОВНИЙ ВИД · локальні осі об’єкта; ТОРЕЦЬ / ТОВЩИНА; ІЗОМЕТРІЯ; КООРДИНАТИ КОНТУРУ ВІД БАЗИ

Dimensions Blender: 1800 × 1200 × 16 мм. Осі головного виду: X / Y.

База 0;0 — нижній лівий кут. Числа біля вершин — номери таблиці.

Крайка: тип, товщину та видимі торці погодити перед розкроєм. Розміри тут — габарити автора, без віднімання крайки.

Монтажні отвори не задані у вихідній моделі. Не свердлити за довільними точками; потрібна присадка вибраної фурнітури.

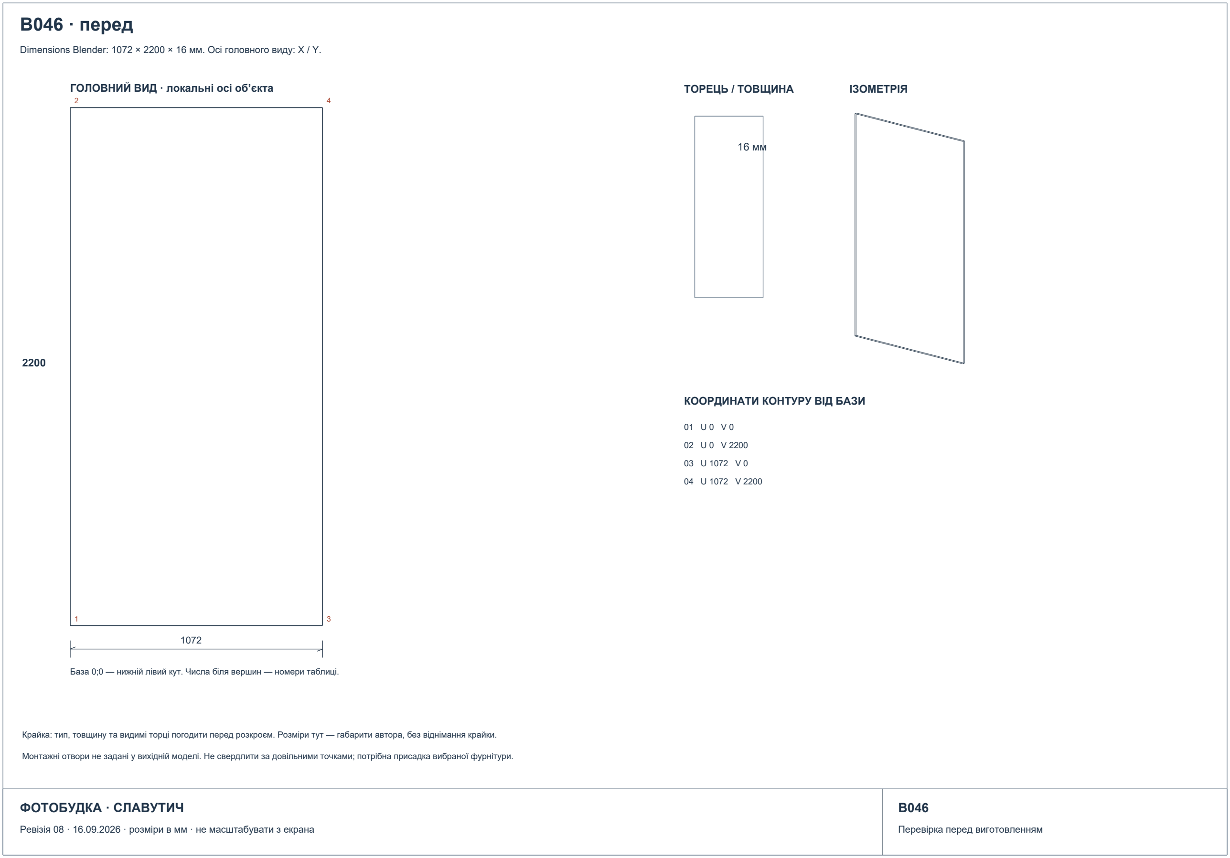
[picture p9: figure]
B046 · перед; ГОЛОВНИЙ ВИД · локальні осі об’єкта; ТОРЕЦЬ / ТОВЩИНА; ІЗОМЕТРІЯ; КООРДИНАТИ КОНТУРУ ВІД БАЗИ

Dimensions Blender: 1072 × 2200 × 16 мм. Осі головного виду: X / Y.

База 0;0 — нижній лівий кут. Числа біля вершин — номери таблиці.

Крайка: тип, товщину та видимі торці погодити перед розкроєм. Розміри тут — габарити автора, без віднімання крайки.

Монтажні отвори не задані у вихідній моделі. Не свердлити за довільними точками; потрібна присадка вибраної фурнітури.

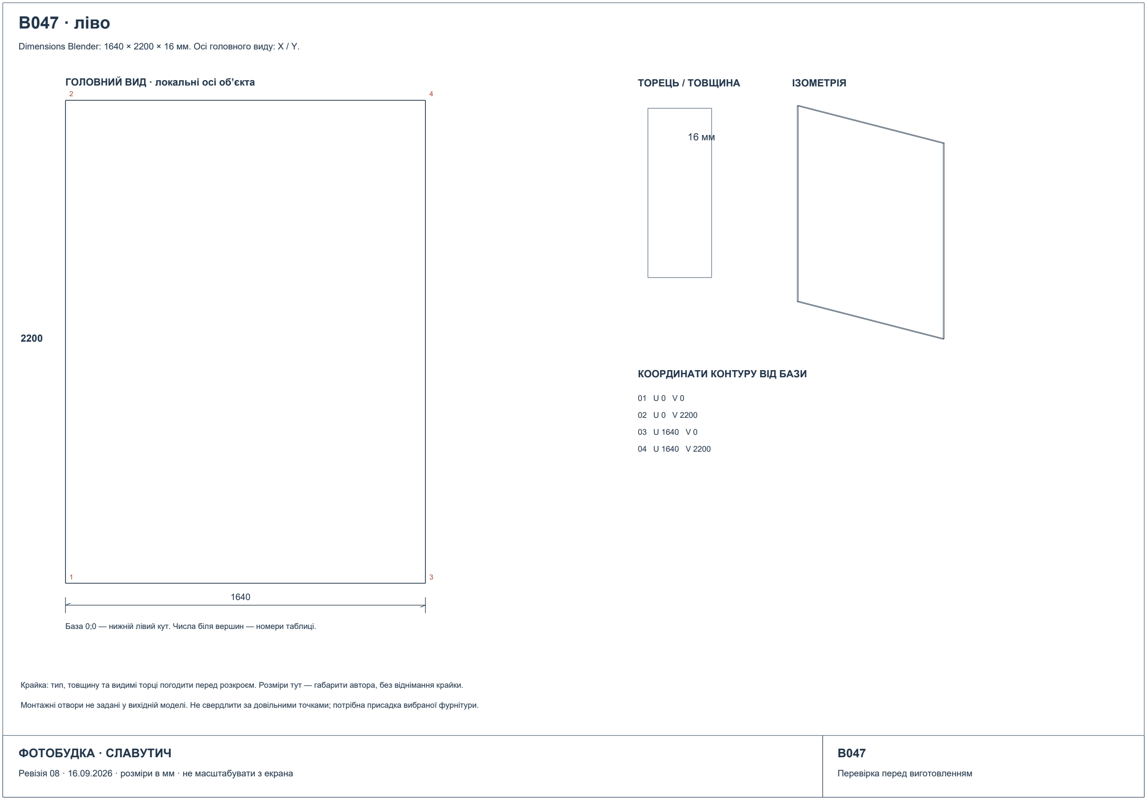
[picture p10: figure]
B047 · ліво; ГОЛОВНИЙ ВИД · локальні осі об’єкта; ТОРЕЦЬ / ТОВЩИНА; ІЗОМЕТРІЯ; КООРДИНАТИ КОНТУРУ ВІД БАЗИ

Dimensions Blender: 1640 × 2200 × 16 мм. Осі головного виду: X / Y.

База 0;0 — нижній лівий кут. Числа біля вершин — номери таблиці.

Крайка: тип, товщину та видимі торці погодити перед розкроєм. Розміри тут — габарити автора, без віднімання крайки.

Монтажні отвори не задані у вихідній моделі. Не свердлити за довільними точками; потрібна присадка вибраної фурнітури.

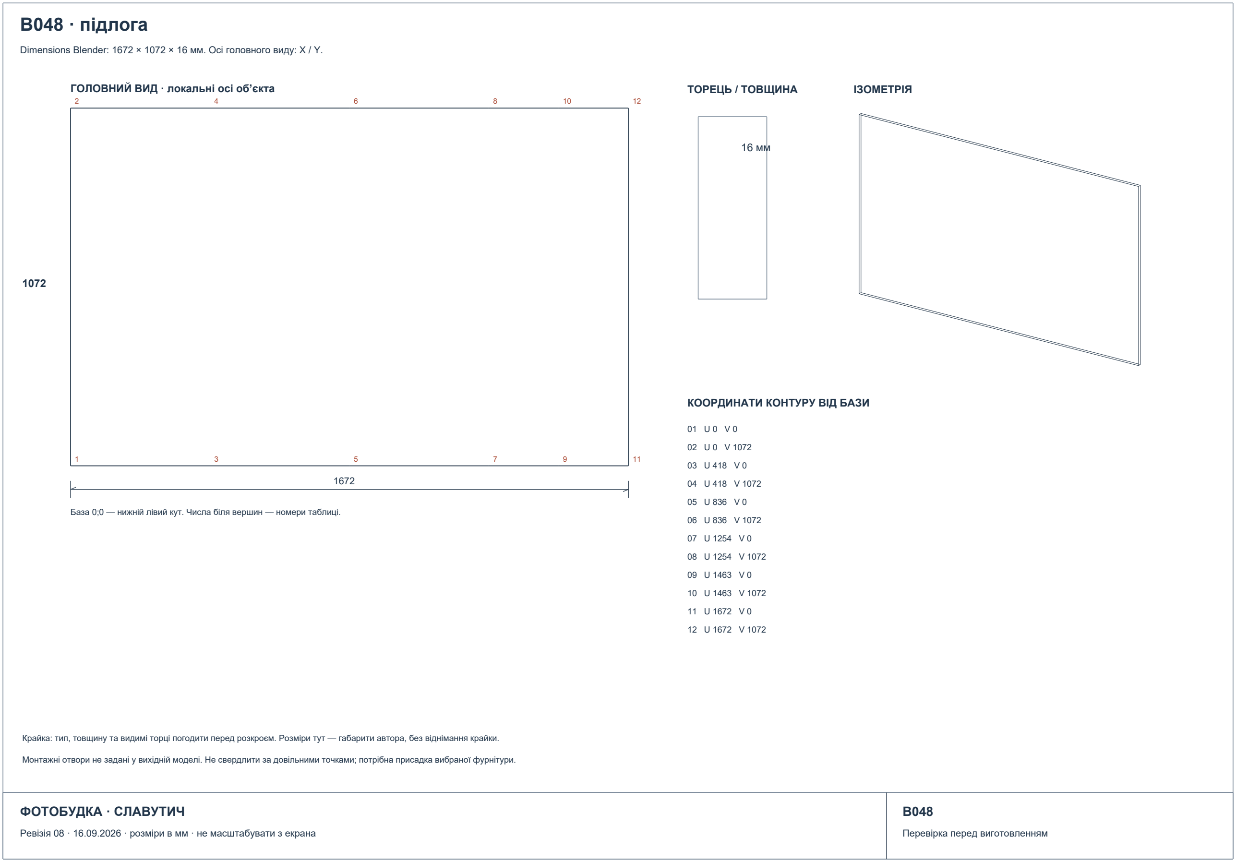
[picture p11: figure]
B048 · підлога; ГОЛОВНИЙ ВИД · локальні осі об’єкта; ТОРЕЦЬ / ТОВЩИНА; ІЗОМЕТРІЯ; КООРДИНАТИ КОНТУРУ ВІД БАЗИ

Dimensions Blender: 1672 × 1072 × 16 мм. Осі головного виду: X / Y.

База 0;0 — нижній лівий кут. Числа біля вершин — номери таблиці.

Крайка: тип, товщину та видимі торці погодити перед розкроєм. Розміри тут — габарити автора, без віднімання крайки.

Монтажні отвори не задані у вихідній моделі. Не свердлити за довільними точками; потрібна присадка вибраної фурнітури.

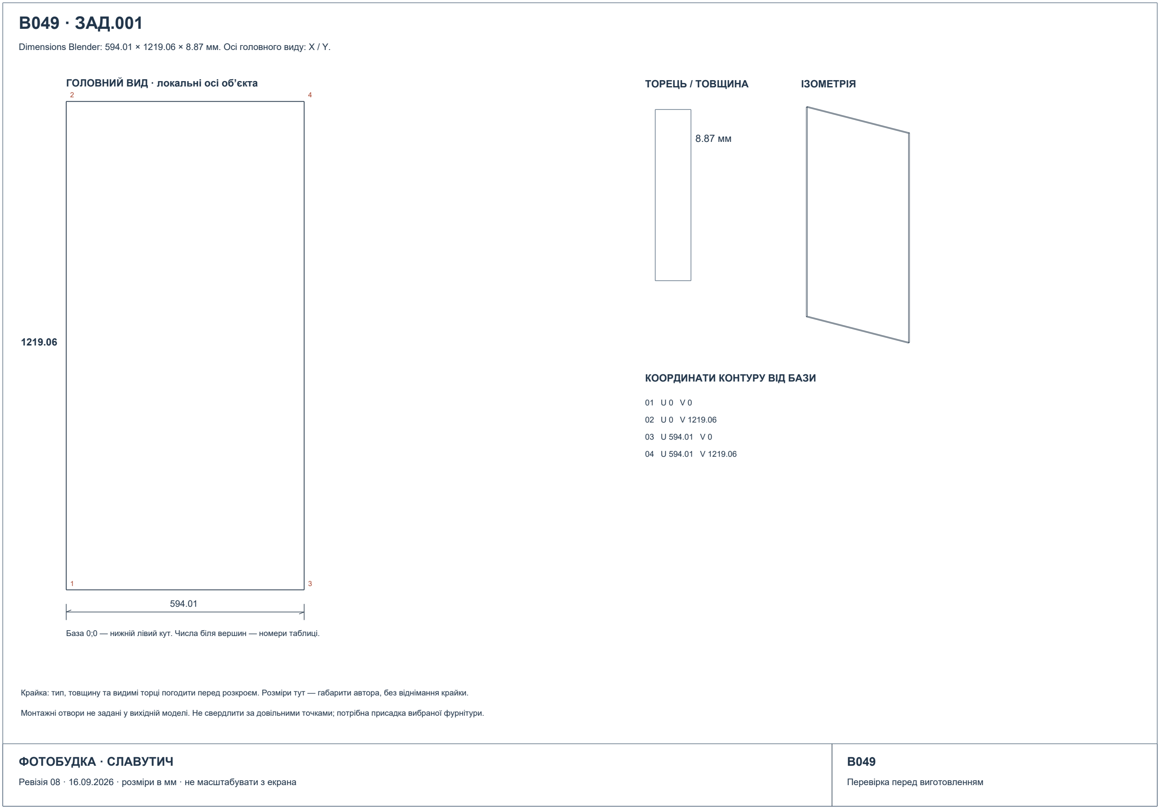
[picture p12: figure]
B049 · ЗАД.001; ГОЛОВНИЙ ВИД · локальні осі об’єкта; ТОРЕЦЬ / ТОВЩИНА; ІЗОМЕТРІЯ; КООРДИНАТИ КОНТУРУ ВІД БАЗИ

Dimensions Blender: 594.01 × 1219.06 × 8.87 мм. Осі головного виду: X / Y.

База 0;0 — нижній лівий кут. Числа біля вершин — номери таблиці.

Крайка: тип, товщину та видимі торці погодити перед розкроєм. Розміри тут — габарити автора, без віднімання крайки.

Монтажні отвори не задані у вихідній моделі. Не свердлити за довільними точками; потрібна присадка вибраної фурнітури.

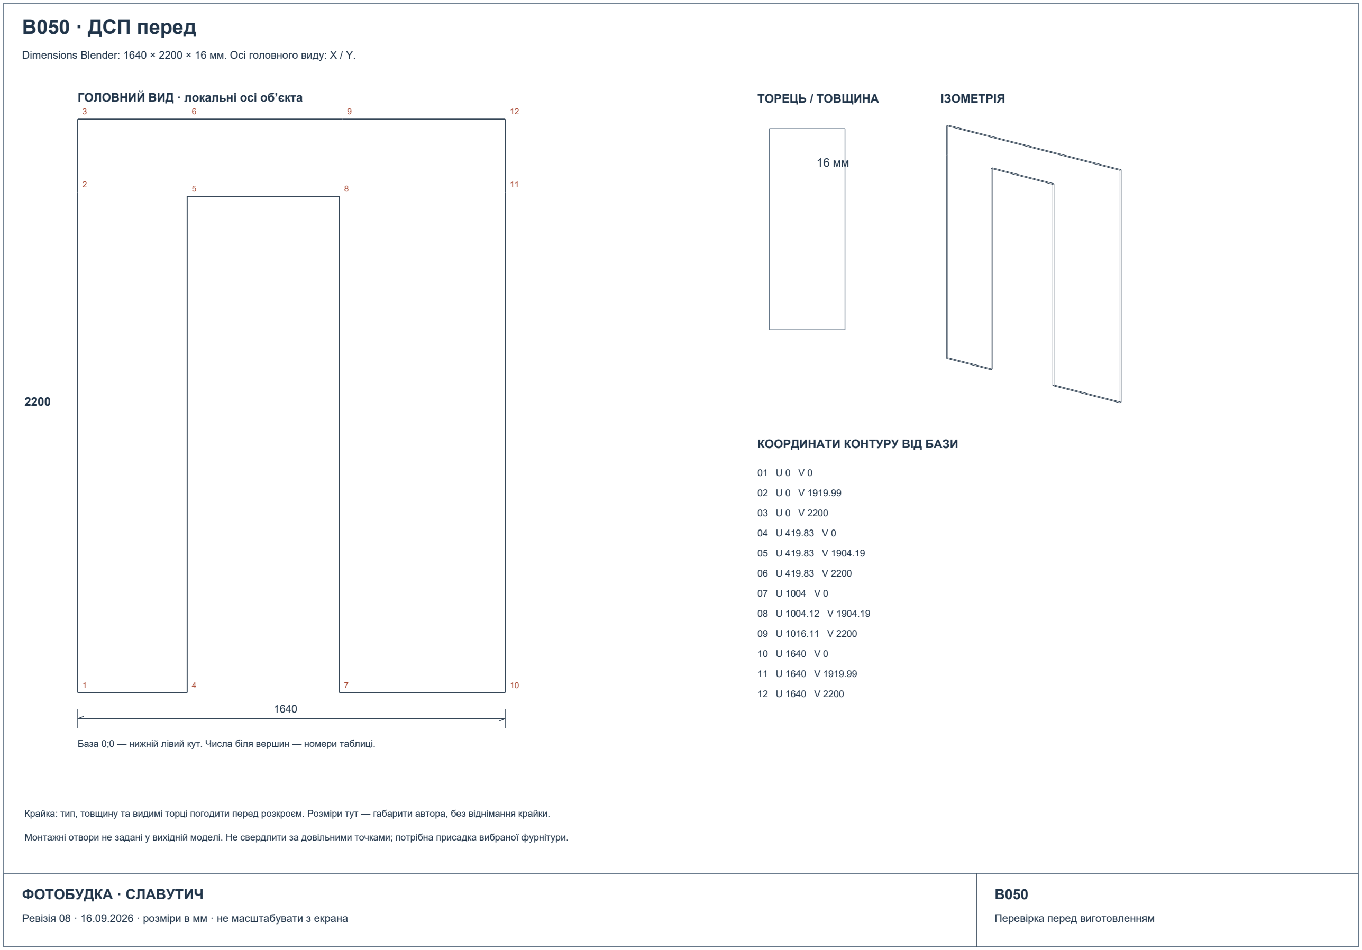
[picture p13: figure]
B050 · ДСП перед; ГОЛОВНИЙ ВИД · локальні осі об’єкта; ТОРЕЦЬ / ТОВЩИНА; ІЗОМЕТРІЯ; КООРДИНАТИ КОНТУРУ ВІД БАЗИ

Dimensions Blender: 1640 × 2200 × 16 мм. Осі головного виду: X / Y.

База 0;0 — нижній лівий кут. Числа біля вершин — номери таблиці.

Крайка: тип, товщину та видимі торці погодити перед розкроєм. Розміри тут — габарити автора, без віднімання крайки.

Монтажні отвори не задані у вихідній моделі. Не свердлити за довільними точками; потрібна присадка вибраної фурнітури.

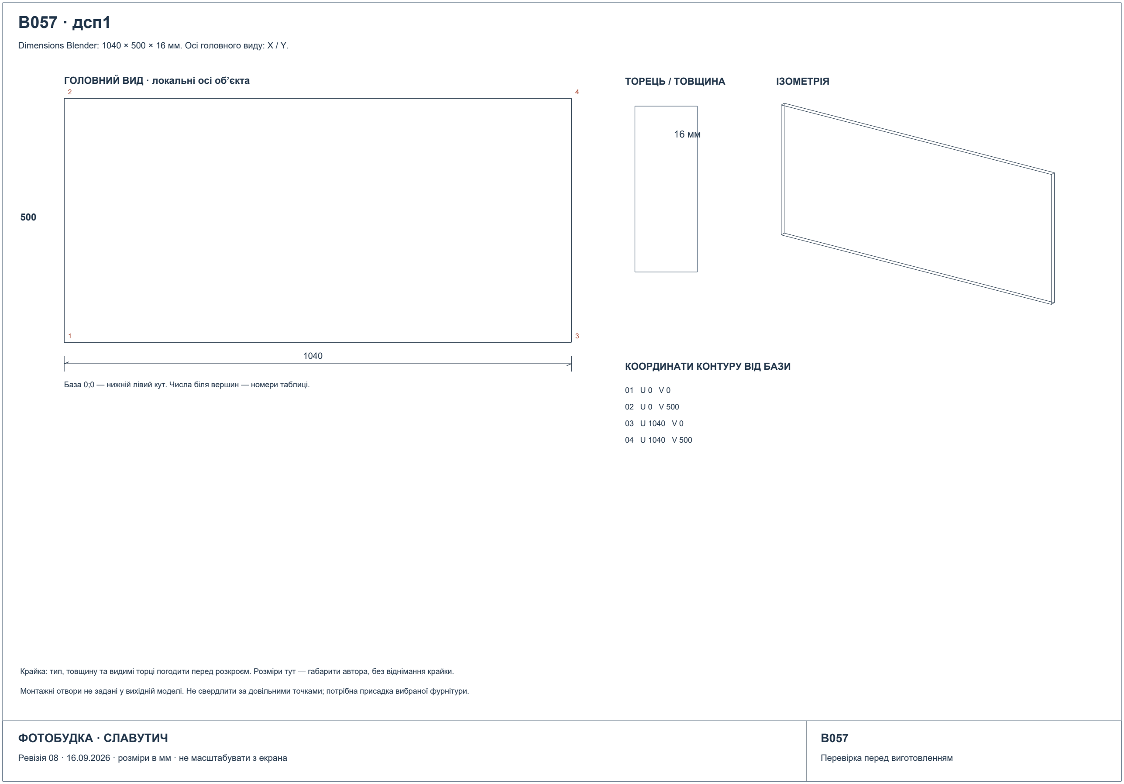
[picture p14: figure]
B057 · дсп1; ГОЛОВНИЙ ВИД · локальні осі об’єкта; ТОРЕЦЬ / ТОВЩИНА; ІЗОМЕТРІЯ; КООРДИНАТИ КОНТУРУ ВІД БАЗИ

Dimensions Blender: 1040 × 500 × 16 мм. Осі головного виду: X / Y.

База 0;0 — нижній лівий кут. Числа біля вершин — номери таблиці.

Крайка: тип, товщину та видимі торці погодити перед розкроєм. Розміри тут — габарити автора, без віднімання крайки.

Монтажні отвори не задані у вихідній моделі. Не свердлити за довільними точками; потрібна присадка вибраної фурнітури.

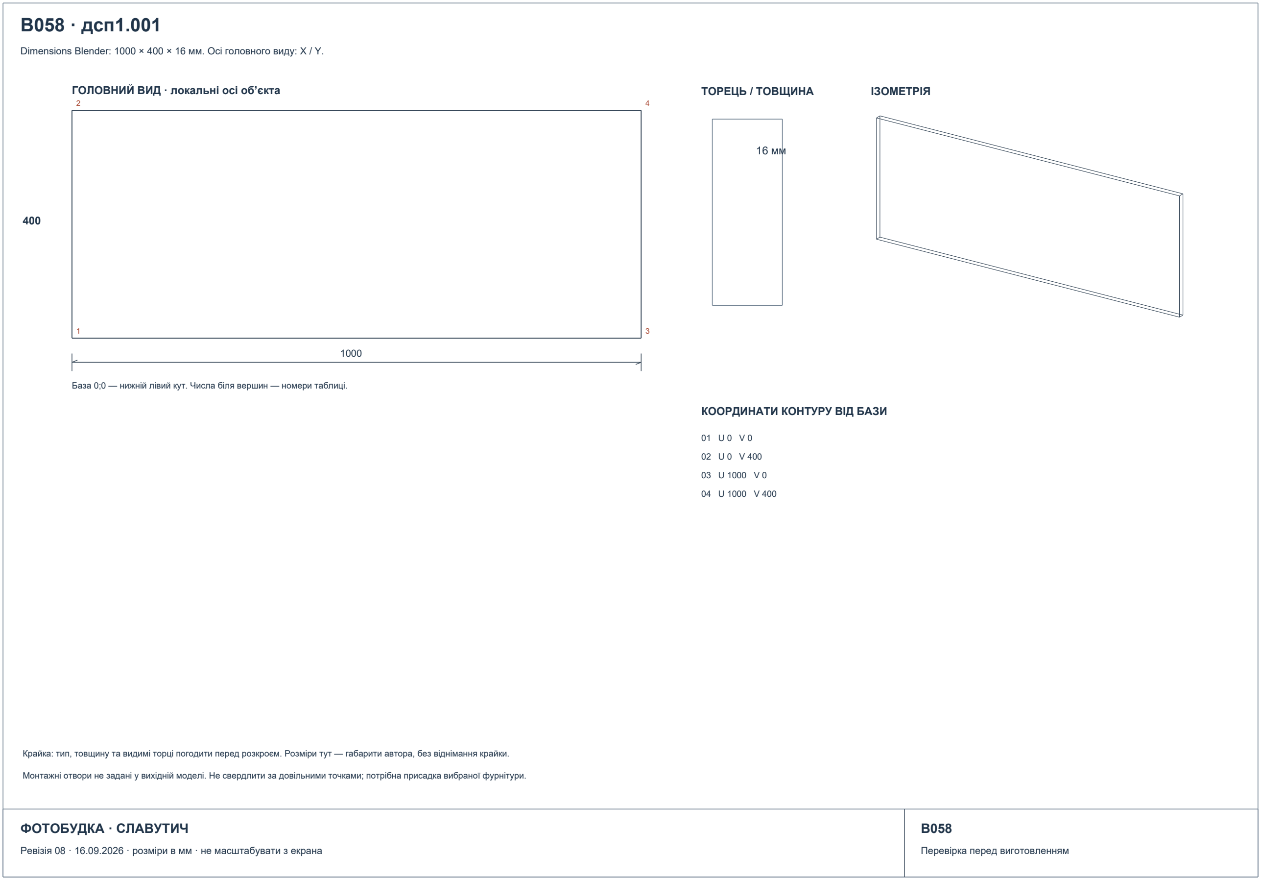
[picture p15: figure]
B058 · дсп1.001; ГОЛОВНИЙ ВИД · локальні осі об’єкта; ТОРЕЦЬ / ТОВЩИНА; ІЗОМЕТРІЯ; КООРДИНАТИ КОНТУРУ ВІД БАЗИ

Dimensions Blender: 1000 × 400 × 16 мм. Осі головного виду: X / Y.

База 0;0 — нижній лівий кут. Числа біля вершин — номери таблиці.

Крайка: тип, товщину та видимі торці погодити перед розкроєм. Розміри тут — габарити автора, без віднімання крайки.

Монтажні отвори не задані у вихідній моделі. Не свердлити за довільними точками; потрібна присадка вибраної фурнітури.

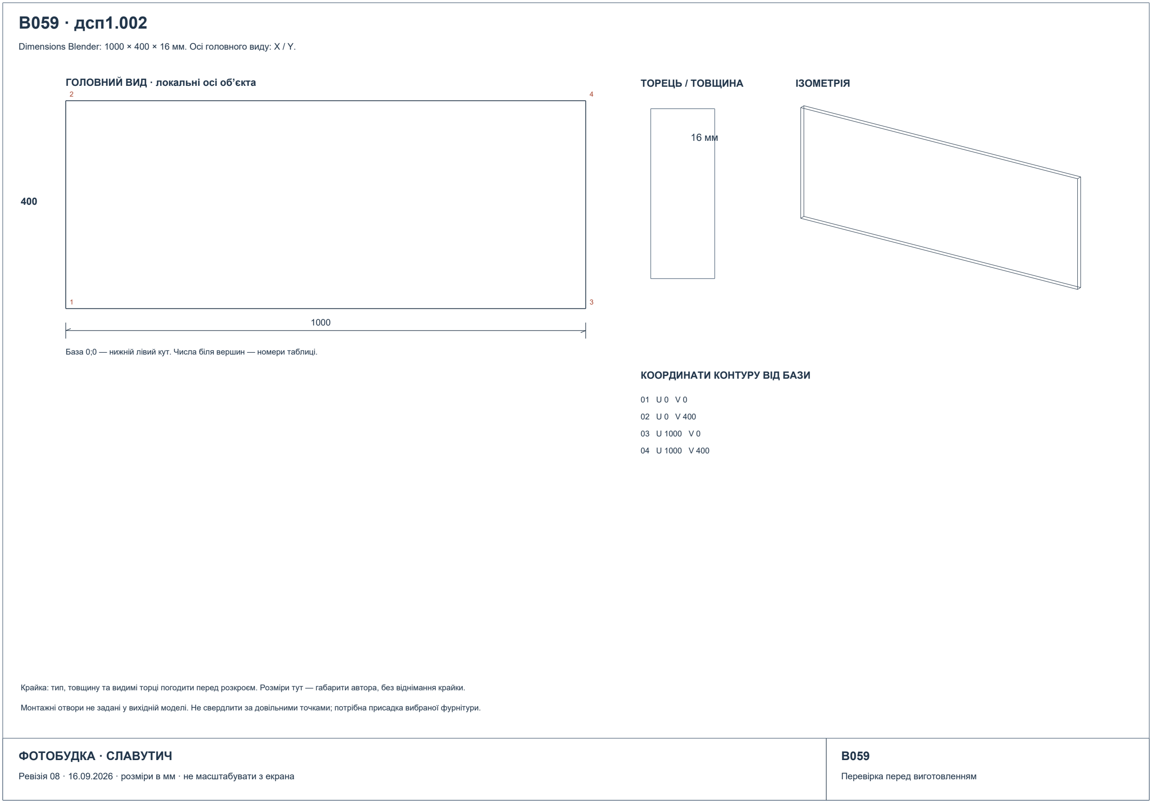
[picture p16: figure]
B059 · дсп1.002; ГОЛОВНИЙ ВИД · локальні осі об’єкта; ТОРЕЦЬ / ТОВЩИНА; ІЗОМЕТРІЯ; КООРДИНАТИ КОНТУРУ ВІД БАЗИ

Dimensions Blender: 1000 × 400 × 16 мм. Осі головного виду: X / Y.

База 0;0 — нижній лівий кут. Числа біля вершин — номери таблиці.

Крайка: тип, товщину та видимі торці погодити перед розкроєм. Розміри тут — габарити автора, без віднімання крайки.

Монтажні отвори не задані у вихідній моделі. Не свердлити за довільними точками; потрібна присадка вибраної фурнітури.

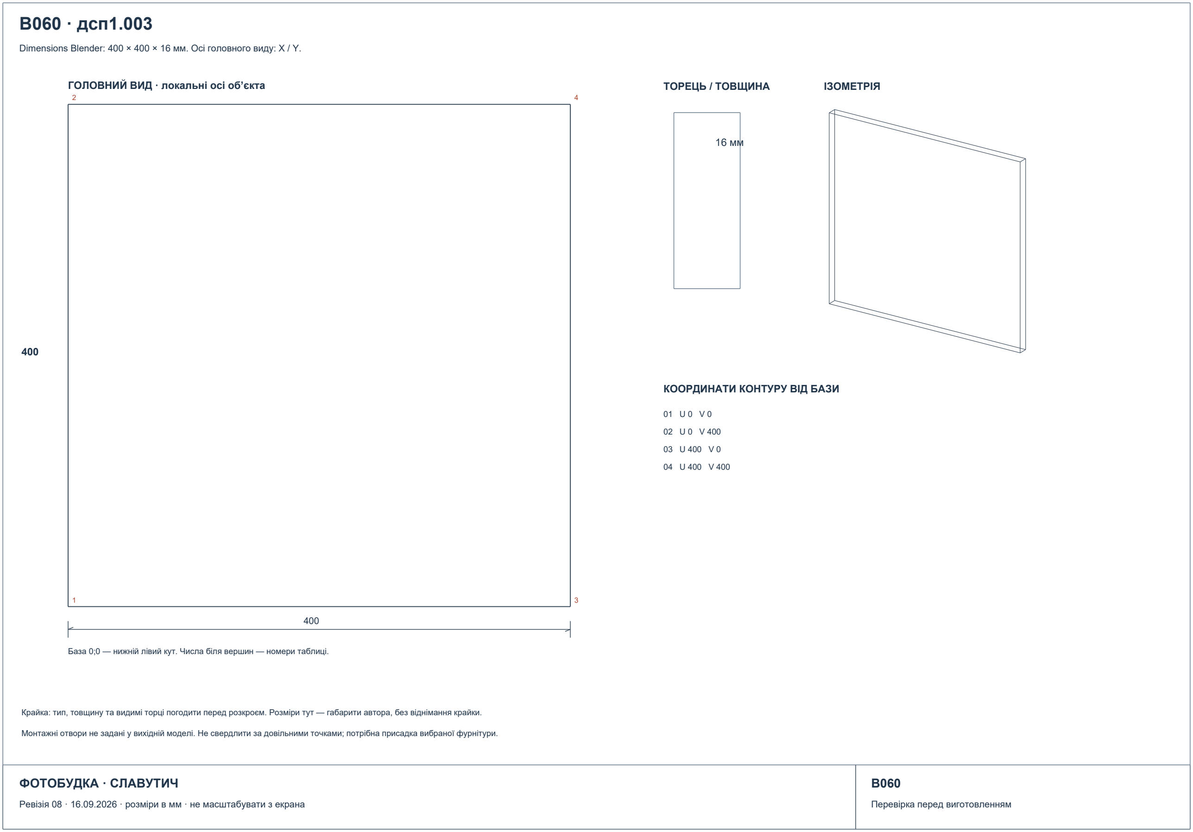
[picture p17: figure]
B060 · дсп1.003; ГОЛОВНИЙ ВИД · локальні осі об’єкта; ТОРЕЦЬ / ТОВЩИНА; ІЗОМЕТРІЯ; КООРДИНАТИ КОНТУРУ ВІД БАЗИ

Dimensions Blender: 400 × 400 × 16 мм. Осі головного виду: X / Y.

База 0;0 — нижній лівий кут. Числа біля вершин — номери таблиці.

Крайка: тип, товщину та видимі торці погодити перед розкроєм. Розміри тут — габарити автора, без віднімання крайки.

Монтажні отвори не задані у вихідній моделі. Не свердлити за довільними точками; потрібна присадка вибраної фурнітури.

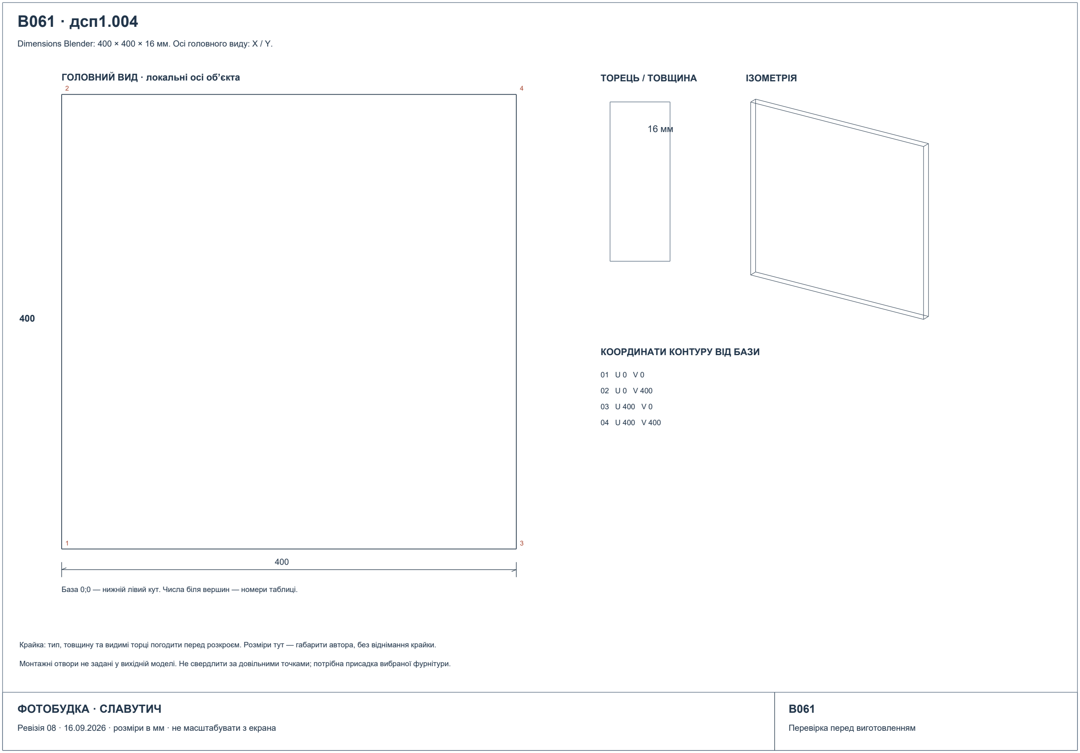
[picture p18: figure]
B061 · дсп1.004; ГОЛОВНИЙ ВИД · локальні осі об’єкта; ТОРЕЦЬ / ТОВЩИНА; ІЗОМЕТРІЯ; КООРДИНАТИ КОНТУРУ ВІД БАЗИ

Dimensions Blender: 400 × 400 × 16 мм. Осі головного виду: X / Y.

База 0;0 — нижній лівий кут. Числа біля вершин — номери таблиці.

Крайка: тип, товщину та видимі торці погодити перед розкроєм. Розміри тут — габарити автора, без віднімання крайки.

Монтажні отвори не задані у вихідній моделі. Не свердлити за довільними точками; потрібна присадка вибраної фурнітури.

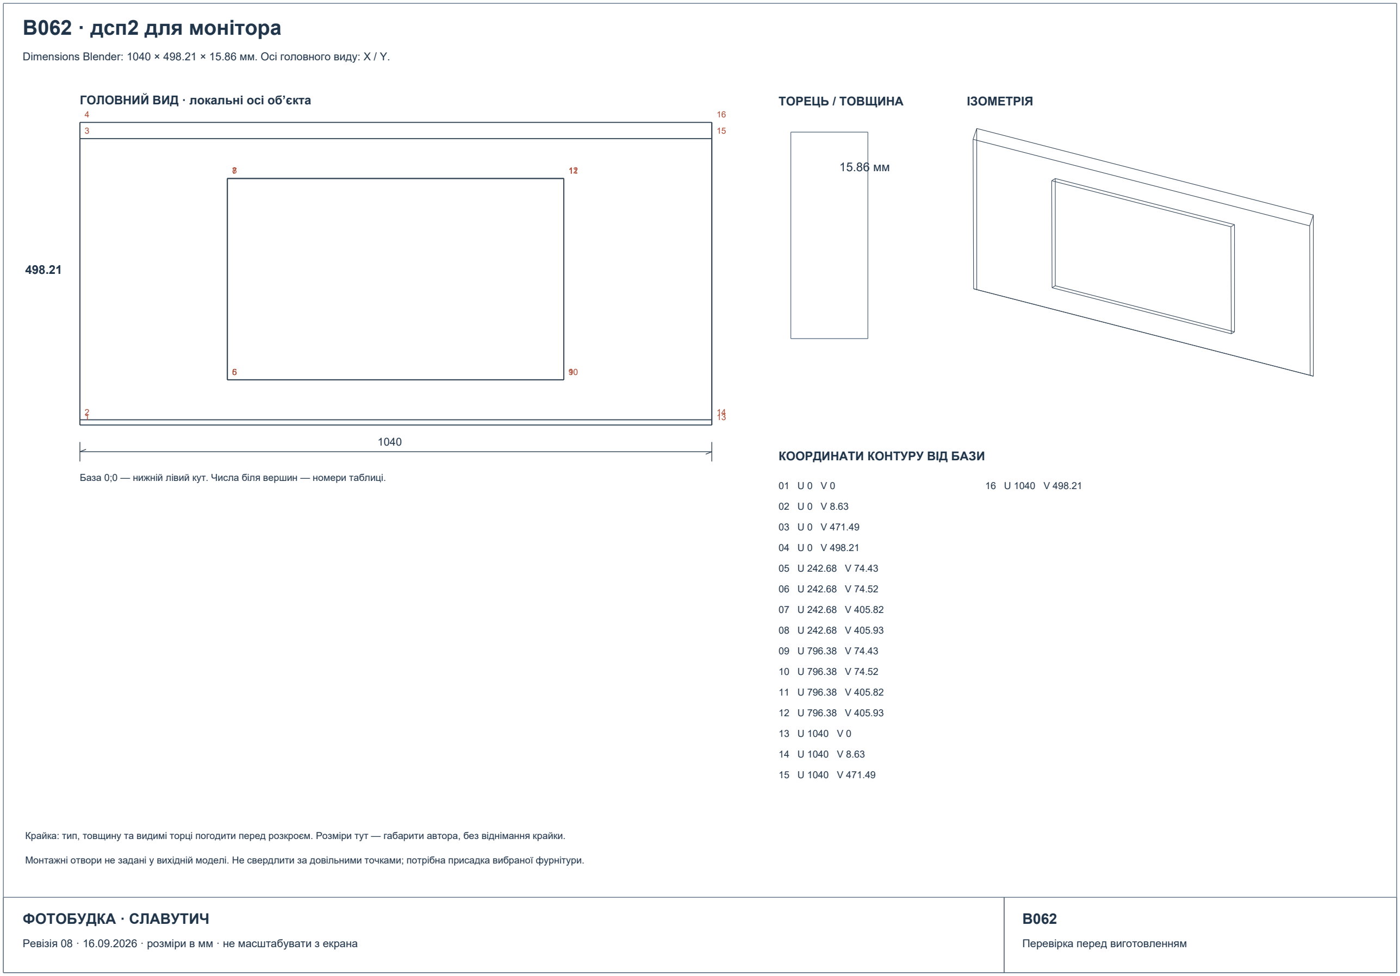
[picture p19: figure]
B062 · дсп2 для монітора; ГОЛОВНИЙ ВИД · локальні осі об’єкта; ТОРЕЦЬ / ТОВЩИНА; ІЗОМЕТРІЯ; КООРДИНАТИ КОНТУРУ ВІД БАЗИ

Dimensions Blender: 1040 × 498.21 × 15.86 мм. Осі головного виду: X / Y.

База 0;0 — нижній лівий кут. Числа біля вершин — номери таблиці.

Крайка: тип, товщину та видимі торці погодити перед розкроєм. Розміри тут — габарити автора, без віднімання крайки.

Монтажні отвори не задані у вихідній моделі. Не свердлити за довільними точками; потрібна присадка вибраної фурнітури.

# 03 · Відомість профілів авторського каркаса

Наведені саме Dimensions, незалежно від повороту профілю. Тип перерізу і спосіб з’єднання потребують підтвердження.

A-03

B002 · Cube.005 | 1000 × 20 × 20 мм
B003 · Cube.006 | 1000 × 20 × 20 мм
B004 · Cube.007 | 1000 × 20 × 20 мм
B005 · Cube.008 | 2200 × 20 × 20 мм
B006 · Cube.009 | 2200 × 20 × 20 мм
B007 · Cube.011 | 280 × 20 × 20 мм
B008 · Cube.012 | 280 × 20 × 20 мм
B009 · Cube.013 | 1600 × 20 × 20 мм
B010 · Cube.021 | 500 × 20 × 20 мм
B011 · Cube.023 | 1000 × 20 × 20 мм
B012 · Cube.024 | 1000 × 20 × 20 мм
B013 · Cube.025 | 1600 × 20 × 20 мм
B014 · Cube.015 | 1900 × 20 × 20 мм
B015 · Cube.018 | 339.58 × 20 × 20 мм
B016 · Cube.022 | 220.42 × 20 × 20.47 мм
B017 · Cube.026 | 339.58 × 20 × 20 мм
B018 · Cube.028 | 339.58 × 20 × 20 мм
B019 · Cube.029 | 484.87 × 20 × 19.87 мм
B020 · Cube.030 | 1000 × 20 × 20 мм
B021 · Cube.031 | 1000 × 20 × 20 мм
B022 · Cube.020 | 580 × 20 × 20 мм
B023 · Cube.032 | 1600 × 20 × 20 мм
B024 · Cube.034 | 500 × 20 × 20 мм
B025 · Cube.035 | 1900 × 20 × 20 мм
B026 · Cube.036 | 339.58 × 20 × 20 мм
B027 · Cube.037 | 220.42 × 20 × 20.47 мм
B028 · Cube.038 | 339.58 × 20 × 20 мм
B029 · Cube.039 | 339.58 × 20 × 20 мм
B030 · Cube.040 | 484.87 × 20 × 19.87 мм
B031 · Cube.041 | 580 × 20 × 20 мм
B032 · Cube.042 | 1600 × 20 × 20 мм
B033 · Cube.014 | 1000 × 20 × 20 мм
B034 · Cube.045 | 1000 × 20 × 20 мм
B035 · Cube.046 | 1000 × 20 × 20 мм
B036 · Cube.001 | 1000 × 20 × 20 мм
B037 · Cube.002 | 1000 × 20 × 20 мм
B038 · Cube.016 | 1000 × 20 × 20 мм
B039 · Cube.017 | 1000 × 20 × 20 мм
B040 · Cube.044 | 572.26 × 20 × 20 мм
B041 · Cube.049 | 572.26 × 20 × 20 мм
B042 · Cube.003 | 484.87 × 20 × 20 мм
B043 · Cube.004 | 484.87 × 20 × 20 мм

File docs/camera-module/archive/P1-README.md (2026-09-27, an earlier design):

> АРХІВ P1 — ЗАСТАРІЛО. Не використовувати для закупівлі або монтажу. Актуальні дані: ../PIN-PURCHASES.md та ../PIN-WIRING.md.

<!-- PIN-WIRING-P1 -->
## Актуальна розводка модуля · 20.09.2026

[Схема і кожен провід](PIN-WIRING.md) · [Закупівля](PIN-PURCHASES.md). D2/D3 → ULN2003 → DM556, D4 → NC HOME. Ця ревізія замінює попередні невизначені підключення модуля. CANDIDATE, не випробувано.

# Поточна конструкція та запит на закупівлю · 20.09.2026

Богдан надіслав запит CNCPROM. Очікуємо відповідь, оплати й підтвердженого замовлення ще немає.

ПК USB → Arduino Nano (живлення USB) → буфер сигналів → DM556 → двигун. Один механічний HOME; протилежна межа програмна. Прошивки немає.

## Конструкція

- TBD45-700 вертикально; Canon R50 у портретній орієнтації на каретці. Кріплення Canon ще потребує підбору.
- Двигун 57BYG250C-8 через LJZ8-DS45-57 та муфту 8×12 D25L30. Посадки, довжини гвинтів і комплектність підтверджує продавець.
- Один механічний кінцевик нерухомо біля нижньої межі. Каретка натискає його до механічного упору. Отвори й натискач після вибору вимикача; 3D показує принцип, не присадку.
- Після запуску координата невідома: обмежений пошук HOME, від’їзд, повільний повторний підхід. Інша межа програмна; пропуск кроків без енкодера автоматично не виявляється. Прошивка не реалізована.
- Кабелеукладач 25×38 мм, 1 м, кінцеві кріплення. Три кабелі: USB камери, низьковольтне живлення камери, sync 3,5 мм. Блок живлення камери нерухомий; 230 В у ланцюг не заводимо. Радіуси й ресурс саме цих кабелів ще перевірити.
- S-250-36 живить DM556. Nano живиться від USB ПК. Підготовку мережевого підключення запитано в продавця.
- Аварійну кнопку та окреме утримання не замовляємо за рішенням користувача. Поведінка каретки без струму невідома — запитано продавця. Програмна зупинка не утримує знеструмлену вісь.
- Кріплення осі до каркаса відкладене. Авторську геометрію кабінки не перебудовано.

## Кошторис

Сім основних позицій CNCPROM за раніше знайденими цінами: **9183 грн**. Це не рахунок продавця.
Кінцевик, комплект кріплення та підготовка БЖ — **ціна очікується**, не 0 грн.
Arduino й електроніка закуповуються окремо. Резерви на монтаж і кріплення Canon не означають підібраного готового набору.

[Поточні позиції та статуси](order.json). [3D і кошторис](../../dashboard/camera-module/index.html).

## Очікуємо від CNCPROM

- Сумісність семи основних деталей
- Комплект і розміри кріплення
- Модель і монтаж механічного кінцевика
- Підготовка блока живлення та доплата
- Чи опускається каретка без живлення
- Остаточний рахунок і наявність

Історичний огляд: [попередній варіант](README-before-order.md). Поточне рішення вище має пріоритет.

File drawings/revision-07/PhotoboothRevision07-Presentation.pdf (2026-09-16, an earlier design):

# Фотобудка · ревізія 07

### Повний складальний комплект кабінки, перебудований з точної геометрії БУДКА.blend

Дата | 16 вересня 2026
Габарит кабінки | 1800 × 1200 × 2232 мм (Ш×Г×В)
Деталей у моделі | 100
Каркас | 42 члени V-Slot 20×20, один тип кутового вузла K1 (Profile Center, комплект 2028)
Кошик каркаса й фурнітури | 14 247 грн
Відомий підсумок кошторису | 328 855 грн (1 позицій без ціни)
Обране обладнання | Canon EOS R50 · TBD45-500 + NEMA23 · DNP DS-RX1HS · Brother HL-L5210DN · Brother DS-740D · Godox MS200V + AD-E1 · EcoFlow DELTA 2 · Nayax VPOS Touch

Цей документ призначений для команди збирання. Онлайн-версія з 3D-моделлю: посилання в кінці документа.

# Кабінка цілком · складальний комплект ревізії 07

Джерело геометрії: БУДКА.blend → drawings/revision-07/blend-scene.json → scripts/design-07.mjs.

Орієнтація: перед — вхід гостя X=0; зад — сервісний бік X=1672; справа — Y=0 (дзеркало/консоль); зліва — Y=1072.

Статус: ролі 42 з 42 деталей каркаса виведені з геометрії блендер-файлу (roleInferred), а не задані явно — перевірте позначені рядки таблиці перед серійною порізкою. Точні кути монтажу камери/спалаху/сканера позначені як попередні (provisional).

01 · усі 6 сторін 02 · поздовжній розріз і висоти 03 · план зверху 04 · вузли K1/K6 05 · порізка прямих 06 · порізка похилих

## 01 · Усі 6 сторін кабінки

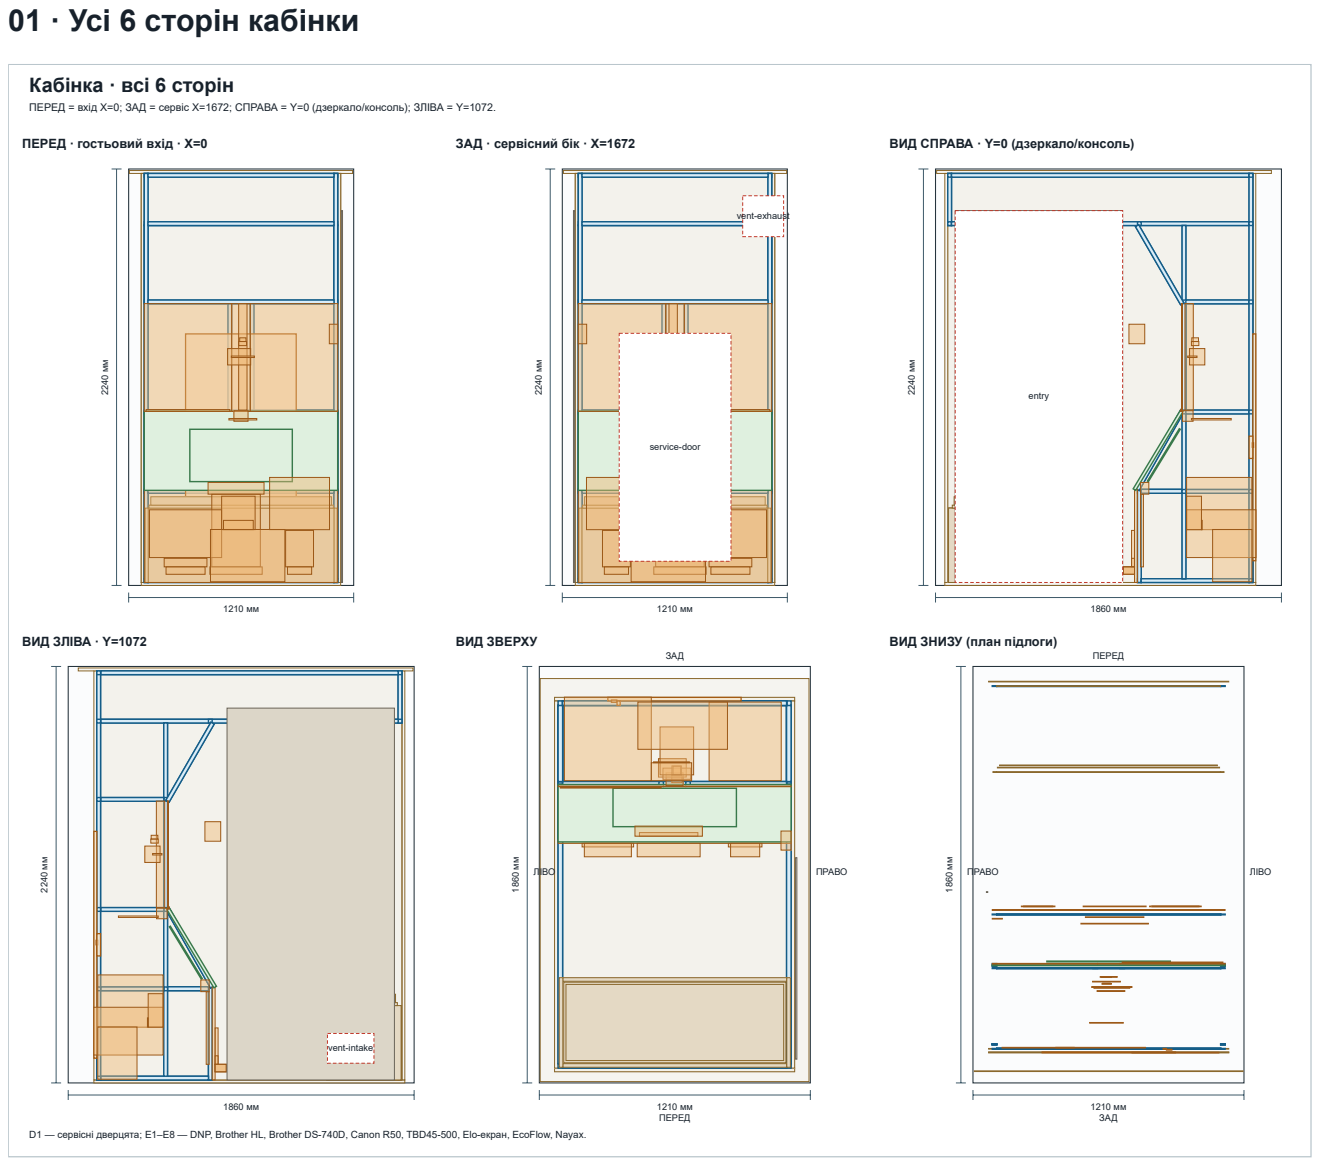
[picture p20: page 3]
service-door; vent-exhaust; entry; ВИД ЗЛІВА · Y=1072; vent-intake; ВИД ЗВЕРХУ; ЗАД; ПЕРЕД; ЛІВО; ПРАВО

Кабінка · всі 6 сторін

ПЕРЕД = вхід X=0; ЗАД = сервіс X=1672; СПРАВА = Y=0 (дзеркало/консоль); ЗЛІВА = Y=1072.

ПЕРЕД · гостьовий вхід · X=0

ЗАД · сервісний бік · X=1672

ВИД СПРАВА · Y=0 (дзеркало/консоль)

ВИД ЗНИЗУ (план підлоги)

D1 — сервісні дверцята; E1–E8 — DNP, Brother HL, Brother DS-740D, Canon R50, TBD45-500, Elo-екран, EcoFlow, Nayax.

## 02 · Поздовжній розріз і висотні рівні

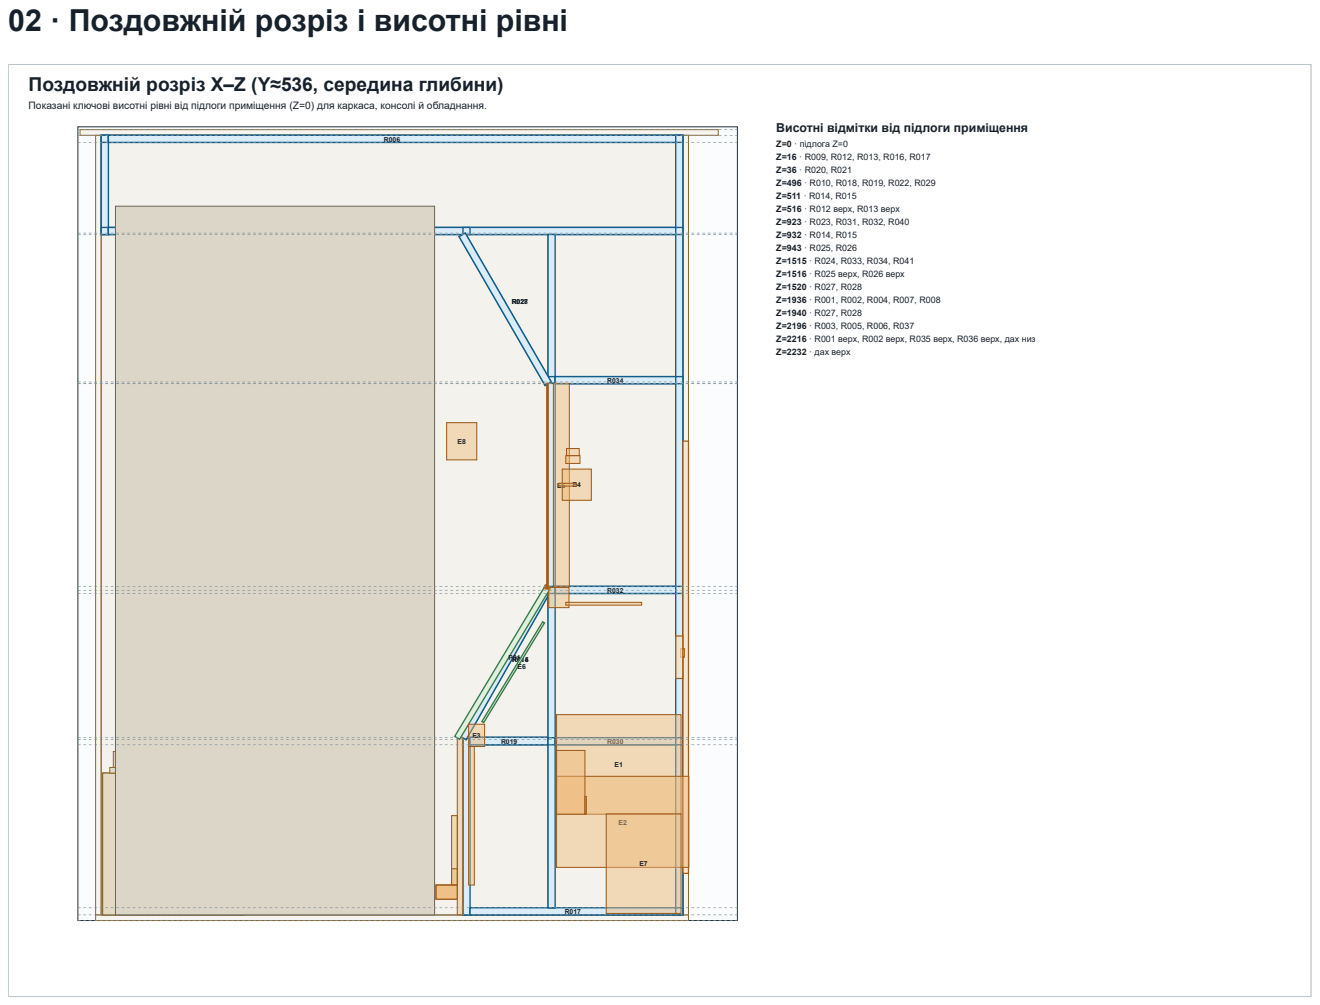
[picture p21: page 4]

Поздовжній розріз X–Z (Y≈536, середина глибини)

Показані ключові висотні рівні від підлоги приміщення (Z=0) для каркаса, консолі й обладнання.

## 03 · План зверху з монтажними координатами

Вид зверху · монтажний план

ПЕРЕД унизу (X=0), ЗАД угорі (X=1672), ПРАВО праворуч (Y=0), ЛІВО ліворуч (Y=1072).

W-ПІДЛОГА W-ДАХ

P01

E6

E5

E4

E3

E1 E2

E7

E8

Монтажні координати стін

X, перед→зад: -44, 0, 16, 1656, 1672, 1756 мм

Y, право→ліво: -64, 0, 16, 1056, 1072, 1136 мм

ЗАД · сервіс

ПЕРЕД · вхід

ЛІВО | ПРАВО

## 04 · Вузли з'єднання

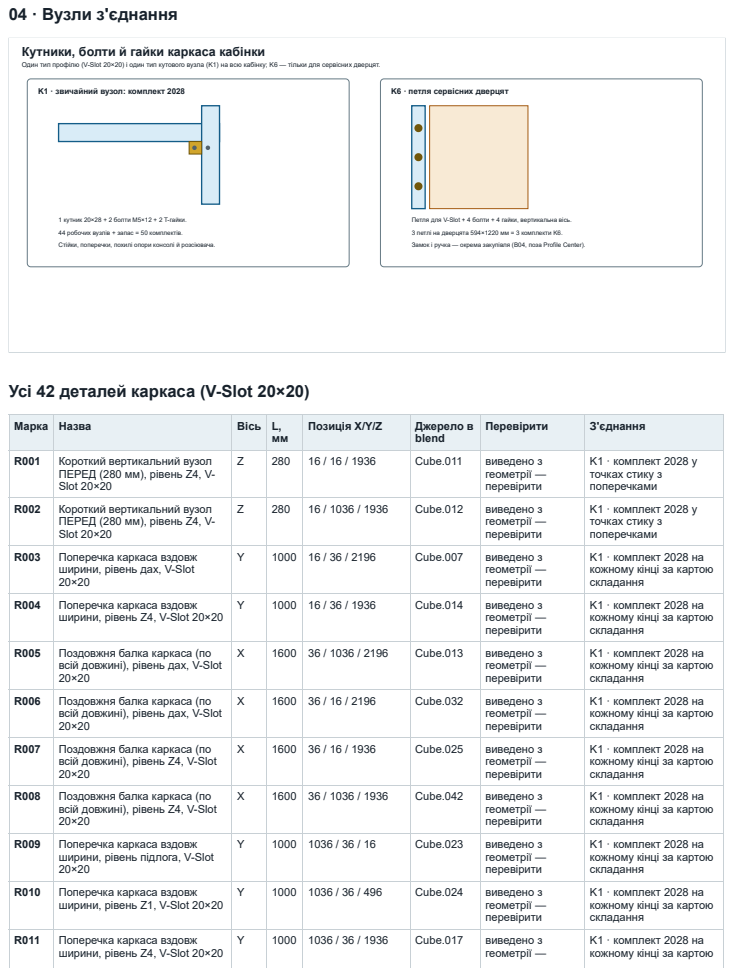
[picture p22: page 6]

Кутники, болти й гайки каркаса кабінки

Один тип профілю (V-Slot 20×20) і один тип кутового вузла (K1) на всю кабінку; K6 — тільки для сервісних дверцят.

1 кутник 20×28 + 2 болти M5×12 + 2 T-гайки.
44 робочих вузлів + запас = 50 комплектів.
Стійки, поперечки, похилі опори консолі й розсіювача.

Петля для V-Slot + 4 болти + 4 гайки, вертикальна вісь.
3 петлі на дверцята 594×1220 мм = 3 комплекти K6.
Замок і ручка — окрема закупівля (B04, поза Profile Center).

Усі 42 деталей каркаса (V-Slot 20×20)

Марка | Назва | Вісь | L, мм | Позиція X/Y/Z | Джерело в blend | Перевірити | З'єднання

R001 | Короткий вертикальний вузол ПЕРЕД (280 мм), рівень Z4, V-Slot 20×20 | Z | 280 | 16 / 16 / 1936 | Cube.011 | виведено з геометрії — перевірити | K1 · комплект 2028 у точках стику з поперечками

R002 | Короткий вертикальний вузол ПЕРЕД (280 мм), рівень Z4, V-Slot 20×20 | Z | 280 | 16 / 1036 / 1936 | Cube.012 | виведено з геометрії — перевірити | K1 · комплект 2028 у точках стику з поперечками

R003 | Поперечка каркаса вздовж ширини, рівень дах, V-Slot 20×20 | Y | 1000 | 16 / 36 / 2196 | Cube.007 | виведено з геометрії — перевірити | K1 · комплект 2028 на кожному кінці за картою складання

R004 | Поперечка каркаса вздовж ширини, рівень Z4, V-Slot 20×20 | Y | 1000 | 16 / 36 / 1936 | Cube.014 | виведено з геометрії — перевірити | K1 · комплект 2028 на кожному кінці за картою складання

R005 | Поздовжня балка каркаса (по всій довжині), рівень дах, V-Slot 20×20 | X | 1600 | 36 / 1036 / 2196 | Cube.013 | виведено з геометрії — перевірити | K1 · комплект 2028 на кожному кінці за картою складання

R006 | Поздовжня балка каркаса (по всій довжині), рівень дах, V-Slot 20×20 | X | 1600 | 36 / 16 / 2196 | Cube.032 | виведено з геометрії — перевірити | K1 · комплект 2028 на кожному кінці за картою складання

R007 | Поздовжня балка каркаса (по всій довжині), рівень Z4, V-Slot 20×20 | X | 1600 | 36 / 16 / 1936 | Cube.025 | виведено з геометрії — перевірити | K1 · комплект 2028 на кожному кінці за картою складання

R008 | Поздовжня балка каркаса (по всій довжині), рівень Z4, V-Slot 20×20 | X | 1600 | 36 / 1036 / 1936 | Cube.042 | виведено з геометрії — перевірити | K1 · комплект 2028 на кожному кінці за картою складання

R009 | Поперечка каркаса вздовж ширини, рівень підлога, V-Slot 20×20 | Y | 1000 | 1036 / 36 / 16 | Cube.023 | виведено з геометрії — перевірити | K1 · комплект 2028 на кожному кінці за картою складання

R010 | Поперечка каркаса вздовж ширини, рівень Z1, V-Slot 20×20 | Y | 1000 | 1036 / 36 / 496 | Cube.024 | виведено з геометрії — перевірити | K1 · комплект 2028 на кожному кінці за картою складання

K1 · комплект 2028 на
кожному кінці за картою

перевірити | складання
R012 | Стійка під технічною перегородкою ЦОКОЛЬ КОНСОЛІ, рівень підлога, V-Slot 20×20 | Z | 500 | 1036 / 16 / 16 | Cube.021 | виведено з геометрії — перевірити | K1 · комплект 2028 у точках стику з поперечками
R013 | Стійка під технічною перегородкою ЦОКОЛЬ КОНСОЛІ, рівень підлога, V-Slot 20×20 | Z | 500 | 1036 / 1036 / 16 | Cube.034 | виведено з геометрії — перевірити | K1 · комплект 2028 у точках стику з поперечками
R014 | Похила опора консолі, V-Slot 20×20 (Y=1036) | S | 485 | Y=1036; XZ 1045/510.5 → 1285/932 | Cube.004 | виведено з геометрії — перевірити | K1 · комплект 2028 на кожному кінці (мітра)
R015 | Похила опора консолі, V-Slot 20×20 (Y=16) | S | 485 | Y=16; XZ 1045/510.5 → 1285/932 | Cube.003 | виведено з геометрії — перевірити | K1 · комплект 2028 на кожному кінці (мітра)
R016 | Коротка перемичка каркаса фотозони, рівень підлога, V-Slot 20×20 | X | 580 | 1056 / 16 / 16 | Cube.020 | виведено з геометрії — перевірити | K1 · комплект 2028 на кожному кінці за картою складання
R017 | Коротка перемичка каркаса фотозони, рівень підлога, V-Slot 20×20 | X | 580 | 1056 / 1036 / 16 | Cube.041 | виведено з геометрії — перевірити | K1 · комплект 2028 на кожному кінці за картою складання
R018 | Коротка перемичка каркаса фотозони, рівень Z1, V-Slot 20×20 | X | 221 | 1056 / 16 / 496 | Cube.022 | виведено з геометрії — перевірити | K1 · комплект 2028 на кожному кінці за картою складання
R019 | Коротка перемичка каркаса фотозони, рівень Z1, V-Slot 20×20 | X | 221 | 1056 / 1036 / 496 | Cube.037 | виведено з геометрії — перевірити | K1 · комплект 2028 на кожному кінці за картою складання
R020 | Кутова/колонна стійка ЛІФТ/ ФОТОЗОНА, повна висота, рівень підлога, V-Slot 20×20 | Z | 1900 | 1276 / 16 / 36 | Cube.015 | виведено з геометрії — перевірити | K1 · комплект 2028 у точках стику з поперечками
R021 | Кутова/колонна стійка ЛІФТ/ ФОТОЗОНА, повна висота, рівень підлога, V-Slot 20×20 | Z | 1900 | 1276 / 1036 / 36 | Cube.035 | виведено з геометрії — перевірити | K1 · комплект 2028 у точках стику з поперечками
R022 | Поперечка каркаса вздовж ширини, рівень Z1, V-Slot 20×20 | Y | 1000 | 1276 / 36 / 496 | Cube.001 | виведено з геометрії — перевірити | K1 · комплект 2028 на кожному кінці за картою складання
R023 | Поперечка каркаса вздовж ширини, рівень Z2, V-Slot 20×20 | Y | 1000 | 1276 / 36 / 923 | Cube.030 | виведено з геометрії — перевірити | K1 · комплект 2028 на кожному кінці за картою складання
R024 | Поперечка каркаса вздовж ширини, рівень Z3, V-Slot 20×20 | Y | 1000 | 1276 / 36 / 1515 | Cube.031 | виведено з геометрії — перевірити | K1 · комплект 2028 на кожному кінці за картою складання
R025 | Стійка під технічною перегородкою ЛІФТ/ ФОТОЗОНА, рівень Z2, V-Slot 20×20 | Z | 573 | 1276 / 466 / 943 | Cube.044 | виведено з геометрії — перевірити | K1 · комплект 2028 у точках стику з поперечками
R026 | Стійка під технічною перегородкою ЛІФТ/ ФОТОЗОНА, рівень Z2, V-Slot 20×20 | Z | 573 | 1276 / 586 / 943 | Cube.049 | виведено з геометрії — перевірити | K1 · комплект 2028 у точках стику з поперечками
R027 | Похила опора верхнього розсіювача, V-Slot 20×20 (Y=1036) | S | 485 | Y=1036; XZ 1285/1520 → 1042.5/1940 | Cube.040 | виведено з геометрії — перевірити | K1 · комплект 2028 на кожному кінці (мітра)
R028 | Похила опора верхнього розсіювача, V-Slot 20×20 (Y=16) | S | 485 | Y=16; XZ 1285/1520 → 1042.5/1940 | Cube.029 | виведено з геометрії — перевірити | K1 · комплект 2028 на кожному кінці (мітра)
R029 | Коротка перемичка каркаса фотозони, рівень Z1, V-Slot 20×20 | X | 340 | 1296 / 16 / 496 | Cube.026 | виведено з геометрії — перевірити | K1 · комплект 2028 на кожному кінці за картою складання
R030 | Коротка перемичка каркаса фотозони, рівень Z1, V-Slot 20×20 | X | 340 | 1296 / 1036 / 496 | Cube.038 | виведено з геометрії — перевірити | K1 · комплект 2028 на кожному кінці за картою складання

R031 | Коротка перемичка каркаса фотозони, рівень Z2, V-Slot 20×20 | X | 340 | 1296 / 16 / 923 | Cube.018 | виведено з геометрії — перевірити | K1 · комплект 2028 на кожному кінці за картою складання
R032 | Коротка перемичка каркаса фотозони, рівень Z2, V-Slot 20×20 | X | 340 | 1296 / 1036 / 923 | Cube.036 | виведено з геометрії — перевірити | K1 · комплект 2028 на кожному кінці за картою складання
R033 | Коротка перемичка каркаса фотозони, рівень Z3, V-Slot 20×20 | X | 340 | 1296 / 16 / 1515 | Cube.028 | виведено з геометрії — перевірити | K1 · комплект 2028 на кожному кінці за картою складання
R034 | Коротка перемичка каркаса фотозони, рівень Z3, V-Slot 20×20 | X | 340 | 1296 / 1036 / 1515 | Cube.039 | виведено з геометрії — перевірити | K1 · комплект 2028 на кожному кінці за картою складання
R035 | Кутова/колонна стійка ЗАД, повна висота, рівень підлога, V-Slot 20×20 | Z | 2200 | 1636 / 16 / 16 | Cube.008 | виведено з геометрії — перевірити | K1 · комплект 2028 у точках стику з поперечками
R036 | Кутова/колонна стійка ЗАД, повна висота, рівень підлога, V-Slot 20×20 | Z | 2200 | 1636 / 1036 / 16 | Cube.009 | виведено з геометрії — перевірити | K1 · комплект 2028 у точках стику з поперечками
R037 | Поперечка каркаса вздовж ширини, рівень дах, V-Slot 20×20 | Y | 1000 | 1636 / 36 / 2196 | Cube.006 | виведено з геометрії — перевірити | K1 · комплект 2028 на кожному кінці за картою складання
R038 | Поперечка каркаса вздовж ширини, рівень підлога, V-Slot 20×20 | Y | 1000 | 1636 / 36 / 16 | Cube.005 | виведено з геометрії — перевірити | K1 · комплект 2028 на кожному кінці за картою складання
R039 | Поперечка каркаса вздовж ширини, рівень Z1, V-Slot 20×20 | Y | 1000 | 1636 / 36 / 496 | Cube.002 | виведено з геометрії — перевірити | K1 · комплект 2028 на кожному кінці за картою складання
R040 | Поперечка каркаса вздовж ширини, рівень Z2, V-Slot 20×20 | Y | 1000 | 1636 / 36 / 923 | Cube.045 | виведено з геометрії — перевірити | K1 · комплект 2028 на кожному кінці за картою складання
R041 | Поперечка каркаса вздовж ширини, рівень Z3, V-Slot 20×20 | Y | 1000 | 1636 / 36 / 1515 | Cube.016 | виведено з геометрії — перевірити | K1 · комплект 2028 на кожному кінці за картою складання
R042 | Поперечка каркаса вздовж ширини, рівень Z4, V-Slot 20×20 | Y | 1000 | 1636 / 36 / 1936 | Cube.046 | виведено з геометрії — перевірити | K1 · комплект 2028 на кожному кінці за картою складання

## Стіни, дах і підлога

Марка | Назва | Габарит | Позиція X/Y/Z | Отвори
W-ПІДЛОГА | Підлога, біла ДСП 16 мм | 1672 × 1072 × 16 | 0 / 0 / 0 | —
W-ДАХ | Дах, біла ДСП 16 мм (звис за геометрією блендера) | 1800 × 1200 × 16 | -44 / -64 / 2216 | —
W-ЗАД | ЗАД: сервісна стіна, біла ДСП 16 мм | 16 × 1072 × 2200 | 1656 / 0 / 16 | service-door, vent-exhaust
W-ПЕРЕД | ПЕРЕД: гостьова стіна входу, біла ДСП 16 мм | 16 × 1072 × 2200 | 0 / 0 / 16 | —
W-СПРАВА | ДСП ПЕРЕД: стіна дзеркала й консолі, біла ДСП 16 мм | 1640 × 16 × 2200 | 16 / 0 / 16 | entry
W-ЗЛІВА | ЛІВО: бічна стіна, біла ДСП 16 мм | 1640 × 16 × 2200 | 16 / 1056 / 16 | vent-intake

## Замовлення на Profile Center

Один профіль (V-Slot 20×20) і один тип кутового вузла (K1-2028) на весь каркас кабінки, плюс окремий комплект петель (K6) для сервісних дверцят.

Код | Товар і пряме посилання | Куди використовується | Кількість | Ціна | Сума
A01 | V-Slot 20×20 без покриття (https://profile-center.com.ua/alyuminiyevyj-verstatnyj-profil-v-slot-20-20-bez-pokryttya) | 38 прямих + 4 похилих деталі каркаса кабінки; чиста довжина 36.888 м | 7 хлист 6 м | 1122.00 | 7854.00
K1 | Комплект 2028: кутник 20×28 + 2 шарнірні болти M5×12 + 2 T-гайки (https://profile-center.com.ua/komplekt-2028-kut-z-yednuvalnyj-cynk-alyuminij-2-sht-sharnirnyj-bolt-2-sht-t-gajka) | 44 кутових вузлів каркаса (оцінка з геометрії, включно з похилими опорами) + запас | 50 компл. | 68.00 | 3400.00

K3 | T-болт з гайкою M5×12-20 (https://profile-center.com.ua/t-bolt-z-gajkoyu-m5-12-20) | кріплення ДСП-обшивки, лавки й похилої консолі до каркаса зсередини | 44 шт. | 26.00 | 1144.00
K5 | T-гайка M5-20 (https://profile-center.com.ua/t-gajka-m5-20-dlya-verstatnogo-profilyu) | резерв для дооснащення та заміни втрачених гайок | 30 шт. | 26.00 | 780.00
K6 | Комплект петлі для V-Slot: петля + 4 болти + 4 гайки (https://profile-center.com.ua/komplekt-petlya-dlya-verstatnogo-profilyu-cynk-alyuminij-4-sht-bolta-4-sht-gajky) | три петлі повнорозмірних сервісних дверцят кабінки | 3 компл. | 283.00 | 849.00
S01 | Обов’язкове пакування профілю (https://profile-center.com.ua/alyuminiyevyj-verstatnyj-profil-v-slot-20-20-bez-pokryttya) | вимога продавця для відправлення перевізником | 1 послуга | 220.00 | 220.00
Разом за цінами 15.09.2026 | | | | | 14247.00 грн

Ціна консервативна для повних 6-метрових хлистів. Чиста довжина профілю: 36.888 м. Карти порізки враховують пропил 3 мм і резерв торця.

## Що треба купити окремо — поза Profile Center

Код | Позиція | Кількість | Призначення
B01 | Білий ДСП 16 мм, ламінований | 5 листів 2750×1830 мм (чиста площа 18.25 м², +12% на розкрій) | усі зовнішні й внутрішні панелі кабінки, лавка, консоль
B02 | Крайкова стрічка ПВХ 2 мм у тон ДСП | 74 п.м (оцінка периметра панелей) | відкриті торці всіх ДСП-панелей
B03 | Конфірмат 7×50 + свердло + шестигранник | 150 шт. + 1 компл. інструменту | збірка ДСП-коробів (стіни між собою, лавка, техперегородка)
B04 | Замок сервісних дверцят + ручка | 1 компл. | сервісні дверцята кабінки (594×1220 мм)
B05 | Осьовий вентилятор 120×120×25 мм, 12 В, з ШІМ і пиловим фільтром (напр. Arctic P12 PWM PST) | 1 шт. + фільтр на припливну решітку | CTL-002: витяжка ЗАД + пасивний приплив ЛІВО
B06 | Решітки вентиляційні 220×220 мм і 250×160 мм, з рамкою | 2 компл. | зовнішнє облицювання вентиляційних отворів
B07 | LED-стрічка 24 В (нейтральний білий) + блок живлення 24В/5А + контролер | ≈6 м стрічки + 1 блок | периметр стелі під розсіювачами + підсвітка консолі
B08 | Штора-блекаут готова, під розмір 964×2084 мм + карниз-трек 1 м + люверси | 1 компл. | вхідний отвір ПЕРЕД
B09 | Поролон 40 мм + оббивочна тканина/екошкіра | за розміром 384×966 мм сидіння | м’яке сидіння лавки
B10 | Кабельні муфти PG13.5 (сірі, IP68) | 3 шт. | проходи кабелів крізь ДСП-стінки до техвідсіку
B11 | Дзеркало полотно 500×1500 мм у механічній касеті | 1 шт. | гостьова стіна консолі

## Порядок складання

1. Зібрати підлогу й нижню рамку каркаса (рівень Z=16…36) по всьому периметру 1672×1072 мм; перевірити діагоналі рулеткою по кутах.
2. Встановити 4 кутові/колонні стійки повної висоти (ПЕРЕД, ЦОКОЛЬ КОНСОЛІ, ЛІФТ/ФОТОЗОНА, ЗАД) на комплектах K1; тимчасово розкріпити.
3. Змонтувати проміжні рівні поперечок (Z1…Z4) з обох боків (Y=36 і Y=1036) на K1; перевірити рівність по рівню.
4. Обшити підлогу і 4 стіни білим ДСП 16 мм: ПЕРЕД (з вирізом входу 964×2084), ЗАД (з вирізом сервісних дверцят 601×1226 і вентиляції), СПРАВА (дзеркало/консоль), ЛІВО (з вирізом припливної решітки).
5. Встановити технічну перегородку (цоколь консолі) і зібрати короб лавки; посадити основу сидіння на місце, приклеїти/прикрутити м’яке сидіння.
6. Встановити 2 похилі опори консолі, обшити похилу консоль ДСП з вирізами під екран і слот сканера; вклеїти/прикрутити сенсорний екран Elo Dotykowy.
7. Встановити 2 похилі опори верхнього розсіювача, змонтувати опалові полікарбонатні розсіювачі й кутовий верхній розсіювач; прокласти LED-стрічку периметром під розсіювачами.
8. Встановити рейки ліфта камери (з готових позицій blend), лінійний модуль TBD45-500 + NEMA23, камеру Canon R50 і спалах Godox MS200V з PC-sync.
9. Встановити сканер Brother DS-740D за консоллю з вертикальним трактом, жолоб-лоток і кишеню видачі на рівні ніг; перевірити прохід картки/А4 наскрізь.
10. Розмістити в службовому відсіку DNP DS-RX1HS, Brother HL-L5210DN, mini-PC і EcoFlow DELTA 2; протягнути кабелі через муфти PG13,5.
11. Встановити дах з розсіювачами, змонтувати вентиляцію (витяжка ЗАД + приплив ЛІВО), навісити сервісні дверцята на 3 петлі K6, встановити замок і ручку.
12. Встановити карниз і штору-блекаут на вході, дзеркало на стіні СПРАВА, термінал Nayax VPOS Touch біля входу.
13. Провести випробування: хід ліфта, прохід картки/паперу через сканер, відкриття/закриття сервісних дверцят, робота вентилятора, LED-стрічки й термінала.

## Карти порізки

Карта порізки V-Slot 20×20 · прямі деталі

Хлист 6000 мм; резерв торця 20 мм; пропил 3 мм. Маркувати кожен відрізок Rxxx.

Х1 | R035·2200 | R036·2200 | R003·1000 | R012·500

залишок 71 мм

Х2 | R020·1900 | R021·1900 | R005·1600 | R013·500

залишок 71 мм

Х3 | R006·1600 | R007·1600 | R008·1600 | R004·1000

залишок 171 мм

Х4 | R009·1000 | R010·1000 | R011·1000 | R022·1000 | R023·1000 | R016·580 | R029·340

залишок 42 мм

Х5 | R024·1000 | R037·1000 | R038·1000 | R039·1000 | R040·1000 | R017·580 | R030·340

залишок 42 мм

Х6 | R041·1000 | R042·1000 | R025·573 | R026·573 | R031·340 | R032·340 | R033·340 | R034·340 | R001·280 | R002·280 | R018·221 | R019·221

залишок 439 мм

Карта порізки V-Slot 20×20 · похилі опори (мітра під кутом)

Довжина по осі бруса; кінці ріжуться під кутом нахилу консолі/розсіювача — підрізати на місці за шаблоном.

Х1 | R014·485 | R015·485 | R027·485 | R028·485

залишок 4031 мм

## Відомість деталей (номінальні розміри)

Листові деталі

ID | Деталь | Розгортка, мм
R7-001 | Підлога, біла ДСП 16 мм | 1672 × 1072 × 16
R7-002 | Дах, біла ДСП 16 мм (звис за геометрією блендера) | 1800 × 1200 × 16
R7-003 | ЗАД: сервісна стіна, біла ДСП 16 мм | 16 × 1072 × 2200
R7-004 | ПЕРЕД: гостьова стіна входу, біла ДСП 16 мм | 16 × 1072 × 2200
R7-005 | ДСП ПЕРЕД: стіна дзеркала й консолі, біла ДСП 16 мм | 1640 × 16 × 2200
R7-006 | ЛІВО: бічна стіна, біла ДСП 16 мм | 1640 × 16 × 2200
R7-007 | Сервісні дверцята кабінки: біла ДСП 16 мм на завісах, із замком | 16 × 595 × 1220
R7-017 | Технічна перегородка (цоколь консолі), біла ДСП 16 мм | 16 × 1040 × 500
R7-018 | Лавка: бічна стінка A, біла ДСП 16 мм | 16 × 1000 × 400
R7-019 | Лавка: бічна стінка B, біла ДСП 16 мм | 16 × 1000 × 400
R7-020 | Лавка: торцева стінка, біла ДСП 16 мм | 400 × 16 × 400
R7-021 | Лавка: торцева стінка, біла ДСП 16 мм | 400 × 16 × 400
R7-024 | Похила консоль з екраном і слотом сканера, біла ДСП 16 мм
R7-052 | Верхній розсіювач, опаловий полікарбонат 3 мм | 1020 × 1040 × 3
R7-053 | Лівий розсіювач, опаловий полікарбонат 3 мм | 3 × 470 × 580
R7-054 | Лівий нижній розсіювач, опаловий полікарбонат 3 мм | 3 × 100 × 580
R7-055 | Правий розсіювач, опаловий полікарбонат 3 мм | 3 × 470 × 580
R7-056 | Кутовий верхній розсіювач, опаловий полікарбонат 3 мм
R7-057 | LED-стрічка 24 В під стельовим розсіювачем | 980 × 10 × 3
R7-058 | LED-стрічка 24 В під стельовим розсіювачем | 980 × 10 × 3
R7-059 | LED-стрічка 24 В під стельовим розсіювачем | 980 × 10 × 3
R7-060 | LED-стрічка 24 В під стельовим розсіювачем | 980 × 10 × 3
R7-061 | LED-стрічка над консоллю (підсвітка екрана) | 3 × 450 × 10
R7-101 | Похила опора консолі, V-Slot 20×20 (Y=16)
R7-102 | Похила опора консолі, V-Slot 20×20 (Y=1036)
R7-103 | Похила опора верхнього розсіювача, V-Slot 20×20 (Y=16)
R7-104 | Похила опора верхнього розсіювача, V-Slot 20×20 (Y=1036)

Профіль V-Slot 20×20

ID (марка) | Деталь | Довжина
R7-063 (R038) | Поперечка каркаса вздовж ширини, рівень підлога, V-Slot 20×20 | 1000 мм
R7-064 (R037) | Поперечка каркаса вздовж ширини, рівень дах, V-Slot 20×20 | 1000 мм
R7-065 (R003) | Поперечка каркаса вздовж ширини, рівень дах, V-Slot 20×20 | 1000 мм
R7-066 (R035) | Кутова/колонна стійка ЗАД, повна висота, рівень підлога, V-Slot 20×20 | 2200 мм
R7-067 (R036) | Кутова/колонна стійка ЗАД, повна висота, рівень підлога, V-Slot 20×20 | 2200 мм
R7-068 (R001) | Короткий вертикальний вузол ПЕРЕД (280 мм), рівень Z4, V-Slot 20×20 | 280 мм
R7-069 (R002) | Короткий вертикальний вузол ПЕРЕД (280 мм), рівень Z4, V-Slot 20×20 | 280 мм
R7-070 (R005) | Поздовжня балка каркаса (по всій довжині), рівень дах, V-Slot 20×20 | 1600 мм

R7-071 (R012) | Стійка під технічною перегородкою ЦОКОЛЬ КОНСОЛІ, рівень підлога, V-Slot 20×20 | 500 мм
R7-072 (R009) | Поперечка каркаса вздовж ширини, рівень підлога, V-Slot 20×20 | 1000 мм
R7-073 (R010) | Поперечка каркаса вздовж ширини, рівень Z1, V-Slot 20×20 | 1000 мм
R7-074 (R007) | Поздовжня балка каркаса (по всій довжині), рівень Z4, V-Slot 20×20 | 1600 мм
R7-075 (R020) | Кутова/колонна стійка ЛІФТ/ФОТОЗОНА, повна висота, рівень підлога, V-Slot 20×20 | 1900 мм
R7-076 (R031) | Коротка перемичка каркаса фотозони, рівень Z2, V-Slot 20×20 | 340 мм
R7-077 (R018) | Коротка перемичка каркаса фотозони, рівень Z1, V-Slot 20×20 | 221 мм
R7-078 (R029) | Коротка перемичка каркаса фотозони, рівень Z1, V-Slot 20×20 | 340 мм
R7-079 (R033) | Коротка перемичка каркаса фотозони, рівень Z3, V-Slot 20×20 | 340 мм
R7-080 (R023) | Поперечка каркаса вздовж ширини, рівень Z2, V-Slot 20×20 | 1000 мм
R7-081 (R024) | Поперечка каркаса вздовж ширини, рівень Z3, V-Slot 20×20 | 1000 мм
R7-082 (R016) | Коротка перемичка каркаса фотозони, рівень підлога, V-Slot 20×20 | 580 мм
R7-083 (R006) | Поздовжня балка каркаса (по всій довжині), рівень дах, V-Slot 20×20 | 1600 мм
R7-084 (R013) | Стійка під технічною перегородкою ЦОКОЛЬ КОНСОЛІ, рівень підлога, V-Slot 20×20 | 500 мм
R7-085 (R021) | Кутова/колонна стійка ЛІФТ/ФОТОЗОНА, повна висота, рівень підлога, V-Slot 20×20 | 1900 мм
R7-086 (R032) | Коротка перемичка каркаса фотозони, рівень Z2, V-Slot 20×20 | 340 мм
R7-087 (R019) | Коротка перемичка каркаса фотозони, рівень Z1, V-Slot 20×20 | 221 мм
R7-088 (R030) | Коротка перемичка каркаса фотозони, рівень Z1, V-Slot 20×20 | 340 мм
R7-089 (R034) | Коротка перемичка каркаса фотозони, рівень Z3, V-Slot 20×20 | 340 мм
R7-090 (R017) | Коротка перемичка каркаса фотозони, рівень підлога, V-Slot 20×20 | 580 мм
R7-091 (R008) | Поздовжня балка каркаса (по всій довжині), рівень Z4, V-Slot 20×20 | 1600 мм
R7-092 (R004) | Поперечка каркаса вздовж ширини, рівень Z4, V-Slot 20×20 | 1000 мм
R7-093 (R040) | Поперечка каркаса вздовж ширини, рівень Z2, V-Slot 20×20 | 1000 мм
R7-094 (R042) | Поперечка каркаса вздовж ширини, рівень Z4, V-Slot 20×20 | 1000 мм
R7-095 (R022) | Поперечка каркаса вздовж ширини, рівень Z1, V-Slot 20×20 | 1000 мм
R7-096 (R039) | Поперечка каркаса вздовж ширини, рівень Z1, V-Slot 20×20 | 1000 мм
R7-097 (R041) | Поперечка каркаса вздовж ширини, рівень Z3, V-Slot 20×20 | 1000 мм
R7-098 (R011) | Поперечка каркаса вздовж ширини, рівень Z4, V-Slot 20×20 | 1000 мм
R7-099 (R025) | Стійка під технічною перегородкою ЛІФТ/ФОТОЗОНА, рівень Z2, V-Slot 20×20 | 573 мм
R7-100 (R026) | Стійка під технічною перегородкою ЛІФТ/ФОТОЗОНА, рівень Z2, V-Slot 20×20 | 573 мм

## Кошторис ревізії 07

Відомий підсумок: 328 855 грн. Відкритих позицій без остаточної ціни: 1.

№ | Категорія | Деталь | Кількість | Ціна од., грн

Джерело

01 | Фото й оптика | Вибраний комплект Canon R50 + 18–45
1 компл. | 31360 | https://fotomost.com.ua/ua/canon-eos-r50-kit-18-45mm/
02 | Фото й
оптика

Вибраний RF-S
14–30 PZ
1 шт. | 7899 | https://ti.ua/ua/obektiv-dlya-fotoapparata-canon-rf-s-14-30mm-f-4-6-3-is-stm-pz.html
03 | Освітлення | Вибраний
Godox MS200V
1 шт. | 3360 | https://fotomost.com.ua/ua/godox-ms200-v/
04 | Ліфт і
автоматика

Вибраний ліфт
TBD45-500
1 шт. | 4490 | https://cncprom.ua/ua/p1089207068-linejnyj-modul-tbd45.html
23 | Корпус і
матеріали

Напис
«ФОТОБУДКА»
чорною
плівкою Oracal

1 компл.
мін. 1 м²
450 | https://directprint.in.ua/plotternaya-porezka
24 | Освітлення | Стельова LED- стрічка

2
котушка
5 м
812 | https://rozetka.com.ua/ua/431011730/p431011730/
25 | Освітлення | БЖ LED 24 В | 1 шт. | 1640 | https://vseplus.com/product/blok-pitania-lrs-200-24-193881
26 | Освітлення | Молочний акрил 3 мм: стеля та світлові панелі | 2.57 м² | 1074.82 | https://promdesign.ua/3-mm-molochnyj-opal-samogon-akril-orgsteklo-thl-3
27 | Освітлення | Кронштейн спалаху та відбивач
1 компл. | 450
28 | Освітлення | Canon AD-E1 | 1 шт. | 2912 | https://fotomost.com.ua/ua/canon-ad-e1-shoe-adapter/
29 | Освітлення | PC-sync адаптер на стандартний башмак | 1 шт. | 547 | https://www.aliexpress.com/item/1005005876468662.html
30 | Освітлення | Синхрокабель, рухома ділянка, роз’єми
1 компл. | 480
31 | Фото й
оптика

Безперервне
живлення
камери
1 компл. | 1200
32 | Ліфт і
автоматика

Кроковий
двигун NEMA23
1 шт. | 1049 | https://prom.ua/ua/Shagovye-dvigateli-nema-23.html
33 | Ліфт і
автоматика

Кронштейн
NEMA23
1 шт. | 160 | https://vseplus.com/ua/product/kronstejn-kutovij-nema23-96947
34 | Ліфт і
автоматика

Муфта вала
ліфта: 12 мм →
вал двигуна
1 шт. | 269 | https://cncprom.ua/ua/p1000069411-gibkaya-kulachkovaya-mufta.html
35 | Ліфт і
автоматика

Драйвер
крокового
двигуна
1 шт. | 1584 | https://prom.ua/ua/p697716061-tsifrovoj-drajver-dm542.html
36 | Ліфт і
автоматика
БЖ осі | 1 шт. | 672.07 | https://led.kiev.ua/LRS-150-24
37 | Ліфт і
автоматика
Кінцевики | 2 шт. | 125 | https://vseplus.com/ua/product/vimikac-kincevij-me-8108-109514
38 | Ліфт і
автоматика
Аварійна кнопка та | 1 компл. | 403.52 | https://tumbler.com.ua/knopka-grybok-avariyna-d-40mm-z-fiksatsiyeyu-povernennya povorotom-1nz-plastyk-ip65-emas

апаратний
ланцюг

39 Ліфт і
автоматика

USB, HDMI,
гнучкі кабелі,
затискачі
1 компл. | 900
40 | Ліфт і
автоматика
Кабелеукладач | 1 м | 180 | https://ua.teslaweld.com/gibkiy-kabel-kanal-kabeleukladchik-15x20
41 | Ліфт і
автоматика
Кронштейн камери, кріплення й упори | 1 компл. | 700
42 | Ліфт і
автоматика

Незалежне
утримання
камери
1 вузол | 350
43 | Ліфт і
автоматика

Кожух руху,
упори, захист
пальців
1 компл. | 600
44 | Комп’ютер
та
інтерфейс
Мінікомп’ютер | 1 шт. | 28159 | https://rombi.com.ua/ua/p2824992421-mini-genmachine-ren.html
45 | Комп’ютер
та
інтерфейс

Сенсорний
монітор
1 шт. | 14760 | https://www.detaik.com.ua/pos-sistemy/dtk-1566r2-15-6-sensornij-shirokoformatnij-p monitor.html
46 | Друк і
сканування

Фотопринтер
DNP DS-RX1HS
1 шт. | 48000 | https://www.olx.ua/d/uk/obyavlenie/printer-dnp-rx-1-hs-dnp-termosub-noviy-IDXBk8o
47 | Кріплення
й
фурнітура

Дві незалежні
пари
напрямних
полиць
принтерів

2 компл. не
визначено

https://epicentrk.ua/ua/shop/mebelnye-napravlyayushchie/fs/tip-napravlyayushchih-teleskopicheskie/

48 Друк і
сканування

Комплект
паперу/стрічки
DNP RX1HS4x6
1 компл. | 11626.42 | https://www.360pbexpert.store/products/dnp-rx1-hs-media-kit-1400-4x6-prints
49 | Оплата | Вендинговий
термінал
1 шт. | 28885 | https://prom.ua/ua/p2079220256-terminal-nayax-vpos.html
50 | Електрика,
мережа й
безпека

Обрано:
EcoFlow DELTA
2, 1024 Вт·год
1 компл. | 31999 | https://sanlarix.com.ua/product/zaryadna-stancziya-ecoflow-delta-2-1024-vt-god/
51 | Електрика,
мережа й
безпека

Електрощит,
автоматика,
клеми,
заземлення
1 компл. | 4500
52 | Електрика,
мережа й
безпека

Контролер
ESP32 DevKit
V1
1 компл. | 295 | https://arduino.ua/prod3990-wi-fi-modyl-devkit-v1-s-esp-32
53 | Електрика,
мережа й
безпека

Вентилятори
Arctic P12, 120
мм
2 шт. | 209 | https://comfy.ua/ua/korpusnyj-ventiljator-arctic-p12-acfan00118a.html
54 | Електрика,
мережа й
безпека

Маршрутизатор
TP-Link Archer
MR200
1 компл. | 3699 | https://comfy.ua/ua/marshrutizator-ethernet-tp-link-archer-mr200.html
55 | Комп’ютер
та
інтерфейс

Динамік і
підсилювач для
голосу
1 компл. | 650
56 | Роботи й
логістика

Вимірювання,
стенд,
електрична
перевірка
1 робота | 3000
57 | Роботи й
логістика

Доставка за фактичними

кошиками

1 компл. 6000

61 Корпус і
матеріали

Дитячий бустер
із фіксацією
1 шт. | 900
68 | Кріплення
й
фурнітура

Проміжні опори
підлоги та
монтажні
пластини
8 шт. | 65
69 | Роботи й
логістика

Оббивка
сидіння та
підшивання
низу готової штори
1 робота | 1200
71 | Друк і
сканування

Монохромний
лазерний
принтер Brother
HL-L5210DN
1 шт. | 15841 | https://rozetka.com.ua/ua/brother-hll5210dnre1/p429370565/
72 | Друк і
сканування

Обрано:
Brother DS-740D —
протяжний A4
duplex сканер
1 шт. | 8247 | https://hotline.ua/ua/computer-skanery/brother-ds-740d-ds740dtk1/
73 | Електрика,
мережа й
безпека

Камера
спостереження
в кабіні
1 шт. | 1620 | https://epicentrk.ua/ua/shop/ip-kamera-imou-nastilna-3-mp-cue-2-ipc-c32ep-3mp-2-8 wi-fi.html
75 | Друк і
сканування

Тонер Brother
TN3600XXL
1 шт. | 11131 | https://ktc.ua/goods/kartridzh_brother_tn3600xxl_black.html
76 | Друк і
сканування

Фотобарабан
Brother DR3600
1 шт. | 14072 | https://inks.com.ua/products/dram-kartridzh-brother-dr3600-75k-dlya-hl-l5210dn-mfc l5710dn-dr3600
77 | Друк і
сканування

Офісний папір
A4 80 г/м², 500
аркушів
1 пачка | 194.75 | https://office-mix.com.ua/ua/papir-a4-zoom-80g-m-500l-2971278/
78 | Корпус і
матеріали

Кабінка 07 · V-Slot 20×20 без
покриття

7 хлист 6
м
1122 | https://profile-center.com.ua/alyuminiyevyj-verstatnyj-profil-v-slot-20-20-bez-pokrytty
79 | Кріплення
й
фурнітура

Кабінка 07 ·
Комплект 2028:
кутник 20×28 +
2 шарнірні
болти M5×12 +
2 T-гайки
50 компл. | 68 | https://profile-center.com.ua/komplekt-2028-kut-z-yednuvalnyj-cynk-alyuminij-2-sht- sharnirnyj-bolt-2-sht-t-gajka
80 | Кріплення
й
фурнітура

Кабінка 07 · T-болт з гайкою M5×12-20

44 шт. | 26 | https://profile-center.com.ua/t-bolt-z-gajkoyu-m5-12-20
81 | Кріплення
й
фурнітура

Кабінка 07 · T-гайка M5-20

30 шт. | 26 | https://profile-center.com.ua/t-gajka-m5-20-dlya-verstatnogo-profilyu
82 | Кріплення
й
фурнітура

Кабінка 07 ·
Комплект петлі
для V-Slot:
петля + 4 болти
+ 4 гайки
3 компл. | 283 | https://profile-center.com.ua/komplekt-petlya-dlya-verstatnogo-profilyu-cynk-alyumin bolta-4-sht-gajky
83 | Роботи й
логістика

Кабінка 07 ·
Обов’язкове
пакування
профілю
1 послуга | 220 | https://profile-center.com.ua/alyuminiyevyj-verstatnyj-profil-v-slot-20-20-bez-pokrytty
84 | Корпус і
матеріали

Кабінка 07 ·
Білий ДСП 16
мм,
ламінований
1 лист | 3494 | https://old.viyar.ua/ua/catalog/kronospan_0101_pe_belyy_fasadnyy_2800kh2070kh1
85 | Корпус і
матеріали

Кабінка 07 ·
Крайкова
стрічка ПВХ 2
мм у тон ДСП
1 м.п. | 18 | https://viyar.ua/ua/catalog/kromka/
86 | Корпус і матеріали

Кабінка 07 ·
Конфірмат

1 компл.
(150 шт. +

300

7×50 + свердло
+ шестигранник

клей)

87 Корпус і
матеріали

Кабінка 07 ·
Замок
сервісних
дверцят +
ручка
1 компл. | 450 | https://kronas.com.ua/ua/furnitura-270/krepyozhnaya-furnitura-365/zamki-366
88 | Корпус і матеріали

Кабінка 07 ·
Осьовий
вентилятор
120×120×25
мм, 12 В, з ШІМ
і пиловим фільтром

(напр. Arctic
P12 PWM PST)
1 шт. | 332 | https://brain.com.ua/ukr/Kuler_do_korpusu_Arctic_P12_PWM_Black_ACFAN00119A p662540.html
89 | Корпус і матеріали

Кабінка 07 ·
Решітки
вентиляційні
220×220 мм і
250×160 мм, з
рамкою

1 компл.
(2
решітки)

380

90 Корпус і
матеріали

Кабінка 07 ·
LED-стрічка 24
В (нейтральний
білий) + блок
живлення
24В/5А +
контролер
1 компл. | 2750 | https://rozetka.com.ua/ua/431011730/p431011730/
91 | Корпус і
матеріали

Кабінка 07 ·
Штора-блекаут
готова, під
розмір
964×2084 мм +
карниз-трек 1 м
+ люверси
1 компл. | 2400
92 | Корпус і
матеріали

Кабінка 07 ·
Поролон 40 мм
+ оббивочна
тканина/
екошкіра
1 компл. | 950 | https://prom.ua/ua/p739781361-porolon-schilnist-40mm.html
93 | Корпус і
матеріали

Кабінка 07 ·
Кабельні
муфти PG13.5
(сірі, IP68)

1 компл.
(3 шт. по
~7–8 грн)
25 | https://viatec.ua/product/UEA-PG135-d6-12-IP68
94 | Корпус і
матеріали

Кабінка 07 ·
Дзеркало
полотно
500×1500 мм у
механічній
касеті
1 шт. | 1500 | https://e-dzerkalo.com.ua/ua/p1144944876-zerkalo-4mm-prirezke.html

## Онлайн-версія

Інтерактивна 3D-модель, фільтр деталей і кошторис із посиланнями на магазини: https://bogdanvcode.github.io/fotobudka-dashboard/

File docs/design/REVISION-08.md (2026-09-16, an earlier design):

# Ревізія 08 · авторська геометрія Blender

16.09.2026. Джерело: БУДКА.blend, SHA256 b56092d7a35eb6bae77cd06e02008d7ef0b7d4ab9e979cc8d33a75e8ea83b8c3.

## Що є джерелом розмірів

62 конструктивні об’єкти перенесені як трикутні меші зі світовими координатами. Dimensions кожного об’єкта збережені без округлення вгору; 0,01 мм у кресленні — точність відображення, не точність виготовлення. Оригінальний файл не перезаписувався. Позначення B — авторські деталі, A — додані вузли. Поворот об’єкта не перетворює габарит його світового прямокутника на розмір розкрою.

Корпус за авторськими панелями: 1672 × 1072 мм у плані; дах 1800 × 1200 мм. Загальна висота від низу підлоги до верху даху — приблизно 2232 мм. Старий опис 1600 × 1000 × 2200 не використовується як розкрій цих панелей.

## Доповнення

Збережені кандидати/вибрані компоненти реєстру: Canon R50 + RF-S 14–30 PZ, TBD45-500, Godox MS200V, AD-E1 і контактний адаптер, Elo 2470L, DNP DS-RX1HS, Brother HL-L5210DN, DS-740D, мініпк, EcoFlow DELTA 2, Nayax. Камера повернута вертикально. Додані полиці, опори, сидіння, монтажна пластина ліфта, опорні планки й схематичні кабельні маршрути. Корпуси обладнання є монтажними габаритами, не заводськими CAD-моделями.

Колишні лотки гравітаційного падіння A4 не перенесено як готові механізми: напрямок виходу паперу і сервісний хід треба перевірити на пристроях. Автоматична видача ще не спроєктована до виробничого рівня.

## Креслення

Альбом drawings/revision-08/index.html; PDF output/pdf/Фотобудка-08-креслення.pdf; 13 аркушів авторських панелей, загальні види, порядок складання та відомість профілів. На кожному аркуші Dimensions, головний вид, торець, ізометрія, база координат і вершини контуру. DXF містить проєкції ребер контуру, без копланарних діагоналей; це не готова керувальна програма ЧПК.

## До виробничого випуску

- ЗАД.001: Dimensions 594,01 × 1219,06 × 8,87 мм — не 16 мм. Узгодити матеріал і петлі.
- Похила консоль: 1040 × 498,21 × 15,86 мм. Похилий верхній розсіювач: 480,04 × 1040 × 5,33 мм при назві «3 мм». Не вирівнювати без погодження автора.
- Крайка, припуски, свердління фурнітури, силові з’єднання каркаса й закріплення до основи ще не випущені.
- Перевірити виймання принтерів і EcoFlow, зазори вентиляції, утримання полиць, захист від падіння камери, кабельний ланцюг.
- Оптичне вікно й світло перевіряються на фізичному макеті. Зум EOS Utility прийнятий як підтверджений користувачем; власного тесту немає.

## Стан

Оновлення придатне для перегляду й узгодження з меблярем. Не є затвердженим комплектом для порізки та серійного складання. productionReleased=false.

## Веб

https://github.com/BogdanVcode/fotobudka-dashboard · https://bogdanvcode.github.io/fotobudka-dashboard/ . Чотири розділи: модель, креслення, комплектуючі, до виготовлення. Попередні ревізії вилучені з основного меню, локальні архіви збережені.

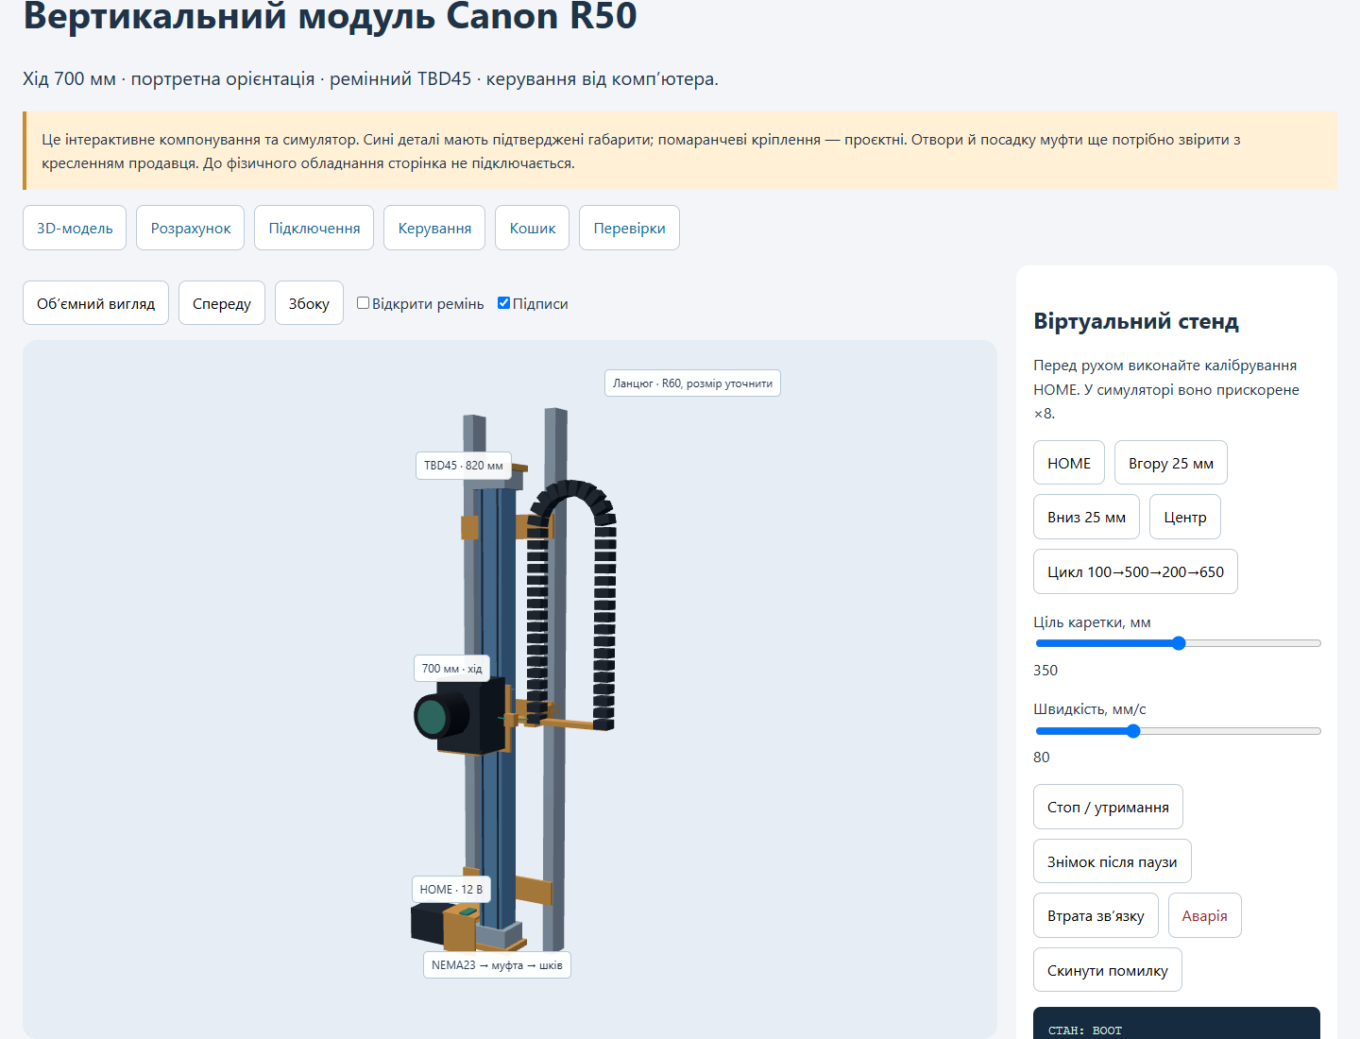
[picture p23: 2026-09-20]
docs/camera-module/preview.png

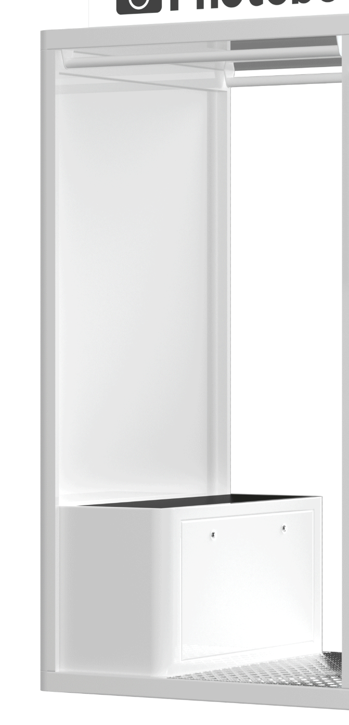
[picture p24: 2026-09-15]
assets/references/01-bench.png

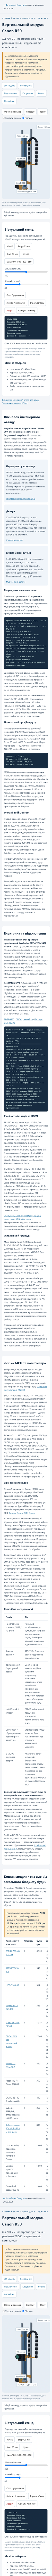
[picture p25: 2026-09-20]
docs/camera-module/mobile.png

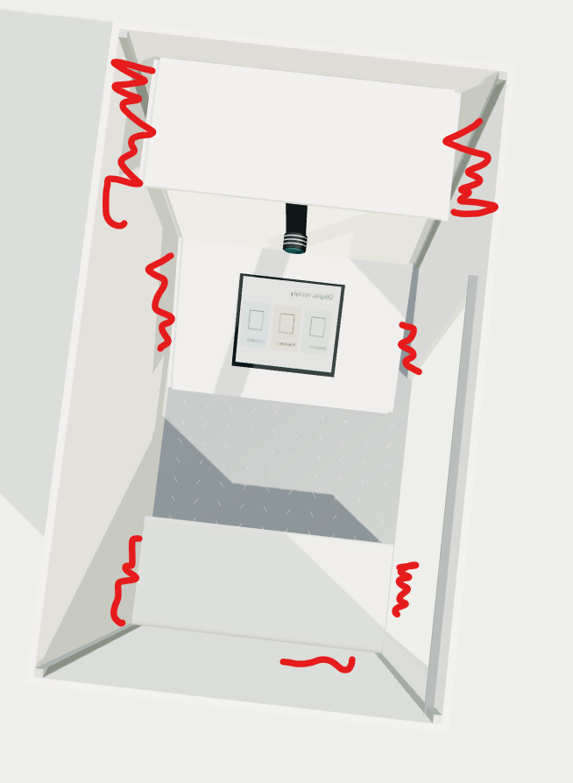
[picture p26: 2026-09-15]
assets/references/06-integrated-module.png

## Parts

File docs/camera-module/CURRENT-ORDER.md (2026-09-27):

# Закупівля вертикального модуля · P2

P2 — єдина актуальна схема. P1 збережено тільки в архіві, її товари не додаються до кошторису.

ПК USB → Arduino Nano (USB 5 В), D2 STEP / D3 DIR → ULN2003 → DM556. D4 нижній HOME і D5 верхня межа: два HURON NPN NO через дві PC817/EL817. XL7015: 36 → 12 В для датчиків. Прошивки та фізичних випробувань немає.

## CNCPROM оплачено й отримано

Товари 9 587 грн; доставка та комісії 529,68 грн; повна витрата 10 116,68 грн. Не замовляти повторно.

| Деталь | Кількість | Сума | Статус |
|---|---|---|---|
| [TBD45-700, хід 700 мм](https://cncprom.ua/ua/p1089226920-linejnyj-modul-tbd45.html) | 1 | 4 950 грн | Замовлено CNCPROM; оплата й отримання не підтверджені. |
| [57BYG250C-8](https://cncprom.ua/ua/p1312688446-dvigatel-shagovyj-57byg250c.html) | 1 | 945 грн | Замовлено CNCPROM; оплата й отримання не підтверджені. |
| [LJZ8-DS45-57](https://cncprom.ua/ua/p1470346846-kronshtejn-shagovogo-dvigatelya.html) | 1 | 315 грн | Замовлено CNCPROM; оплата й отримання не підтверджені. |
| [Сильфонна муфта 8×12 мм, D25 L30](https://cncprom.ua/ua/p914622727-gibkaya-silfonnaya-mufta.html) | 1 | 383 грн | Замовлено CNCPROM; оплата й отримання не підтверджені. |
| [DM556](https://cncprom.ua/ua/p865450706-drajver-dm556-vdc.html) | 1 | 675 грн | Замовлено CNCPROM; оплата й отримання не підтверджені. |
| [S-250-36, 36 В, 250 Вт](https://cncprom.ua/ua/p556579870-impulsnyj-blok-pitaniya.html) | 1 | 1 350 грн | Замовлено CNCPROM; оплата й отримання не підтверджені. |
| [Кабелеукладач 25×38 мм, 1 м, обидва кінцеві кріплення](https://cncprom.ua/ua/p1671300145-gibkij-kabel-kanal.html) | 1 | 585 грн | Замовлено CNCPROM; оплата й отримання не підтверджені. |
| Датчики P2, кутові кронштейни й гвинти з гайками — комплект | 1 | 384 грн | Разом 384 грн — різниця між підсумком 9 587 грн і сімома основними позиціями 9 203 грн. Ціни окремих складових не надані. |
| [Nano V3 ATmega328P з припаяними роз’ємами](https://arduino.ua/prod166-arduino-nano-v3-0-avr-atmega328p-z-rozpayanimi-konektorami) | 1 | 179 грн | Оплачено й отримано у складі Arduino.ua №655452; окрему ціну не розподілено. |
| [USB-A → Mini-USB 0,8 м](https://arduino.ua/prod892-usb-2-0-kabel-am-miniusb-0-8m-atcom-s-ferritom) | 1 | 55 грн | Оплачено й отримано у складі Arduino.ua №655452; окрему ціну не розподілено. |
| [Набір перемичок (мама-мама) 200мм 40 шт.](https://arduino.ua/prod220-nabor-peremichek-mama-mama-200mm-40-sht) | 1 | 43 грн | Оплачено, але ще не отримано: Prom №429701730. |
| [Набір термоусадок (Ø1-14мм) 164 шт](https://arduino.ua/prod3980-nabor-termoysadok-1-14mm-164-sht) | 1 | 87 грн | Оплачено й отримано: Prom №429061419. |
| [Опторозв’язка PC817/EL817, вхід 12 В — кандидат, підтвердити вихідну схему](https://rozetka.com.ua/ua/mini-kompyuteri-bez-brenda-152518050/p551339865/) | 2 | 144 грн | 2-канальний модуль PC817 оплачено й отримано; фактичну вихідну схему ще перевірити. |
| [Набір нейлонових чорних шестигранних стійок М3 180шт](https://arduino.ua/prod1452-nabor-neilonovih-chernih-shestigrannih-stoek-m3-180-sht) | 1 | 239 грн | Нейлонові стійки 10 мм для плат з отворами M3. Гвинти та гайки є в наборі; не свердлити плати для збільшення отворів. |

До комплекту додано:

- HURON LJ12A3-4-Z/BX, NPN NO — 2 шт.
- Кутовий кронштейн M12 — 2 шт.
- Гвинт M4×10 DIN 912 — 4 шт.
- Пазова гайка SNB20-S6E-M4 — 4 шт.
- Гвинт M5×18 DIN 912 — двигун — 4 шт.
- Гвинт M5×15 DIN 7991 — модуль — 4 шт.

## Залишилось придбати або перевірити

### Arduino.ua

| Деталь | Кількість | Сума | Статус |
|---|---|---|---|
| [Плата ULN2003](https://arduino.ua/prod280-draiver-shagovogo-dvigatelya-uln2003) | 1 | 34 грн | Потрібно придбати для P2; апаратна перевірка ще не виконана. |
| [Кабель 16AWG в силіконовій ізоляції 50см (червоний)](https://arduino.ua/prod3617-kabel-16awg-v-silikonovoi-izolyacii-50sm-krasnii) | 2 | 56 грн | Потрібно придбати для P2; апаратна перевірка ще не виконана. |
| [Сервокабель Dinogy 22 AWG зкручений (Futaba) 1м](https://arduino.ua/prod2651-kabel-trehjilnii-dlya-servoprivodov-1m) | 4 | 220 грн | Потрібно придбати для P2; апаратна перевірка ще не виконана. |
| [Монтажна клема PCT-415 на 5 провідників аналог WAGO 221 (0.25-4мм2)](https://arduino.ua/prod7576-montajna-klema-pct-415-na-5-providnikiv-z-vajelyami-tipy-wago-221-0-25-4mm2) | 6 | 84 грн | Потрібно придбати для P2; апаратна перевірка ще не виконана. |
| [Багаторазова клема PCT-412 на 2 провідники аналог WAGO 221 (0.25-4мм2)](https://arduino.ua/prod7577-bagatorazova-klema-pct-412-na-2-providniki-z-vajelyami-tipy-wago-221-0-25-4mm2) | 10 | 90 грн | Потрібно придбати для P2; апаратна перевірка ще не виконана. |
| [Роз&#039;єм XH 2.54 5Y з конекторами](https://arduino.ua/prod1319-razem-xh-2-54-5y) | 2 | 10 грн | Потрібно придбати для P2; апаратна перевірка ще не виконана. |
| [Кабель 16AWG в силіконовій ізоляції 50см (синій)](https://arduino.ua/prod7489-kabel-16awg-v-silikonovii-izolyacii-50sm-sinii) | 2 | 56 грн | Потрібно придбати для P2; апаратна перевірка ще не виконана. |
| [Набір наконечників на дріт E1512 50шт](https://arduino.ua/prod8448-nabir-nakonechnikiv-na-drit-e1512-50sht) | 1 | 34 грн | Потрібно придбати для P2; апаратна перевірка ще не виконана. |
| [Набір наконечників на дріт E7510 50шт](https://arduino.ua/prod8450-nabir-nakonechnikiv-na-drit-e7510-50sht) | 1 | 25 грн | Потрібно придбати для P2; апаратна перевірка ще не виконана. |
| [КАБЕЛЬ AM USB 2.0 / TYPE-C 1.8М., GOLD PLATED](https://arduino.ua/prod5575-kabel-am-usb-2-0--type-c-1-8m-gold-plated) | 1 | 121 грн | Потрібно придбати для P2; апаратна перевірка ще не виконана. |
| [Кабель 18AWG в силіконовій ізоляції 50см (чорний)](https://arduino.ua/prod925-kabel-18awg-v-silikonovoi-izolyacii-50sm-chernii) | 8 | 144 грн | Потрібно придбати для P2; апаратна перевірка ще не виконана. |
| [Набір латунних стійок М2 з гвинтами 260шт в органайзері](https://arduino.ua/prod1482-nabor-latynnih-stoek-m2-s-vintami) | 1 | 298 грн | Стійки M2 з гвинтами й гайками для малих отворів Nano. Перевірити зазор до доріжок; не заміняти ними ізоляційний бар’єр. |
| [Панельний вхід C14 з вимикачем і відсіком 5×20](https://arduino.ua/prod6028-rozm-jivlennya-220v-z-vimikachem-ta-zapobijnikom-10a) | 1 | 53 грн | Кандидат для монтажника. Комплектний запобіжник 10 А не затверджений для нашого вузла. Потрібні ізольовані внутрішні з’єднання, кожух контактів та вибір мережевого F0 за пусковим струмом БЖ. |

### Radio Construct

| Деталь | Кількість | Сума | Статус |
|---|---|---|---|
| [XL7015 5–80 В → 5–20 В (виставити 12 В)](https://rozetka.com.ua/ua/459336324/p459336324/) | 1 | 72 грн | Потрібно придбати для P2; апаратна перевірка ще не виконана. |

### Світла Хата

| Деталь | Кількість | Сума | Статус |
|---|---|---|---|
| [Пластиковий ABS-бокс 300×400×170 мм з монтажною панеллю](https://svitlahata.in.ua/ua/p2845962477-korpus-schit-plastikovij.html) | 1 | 1 200 грн | Знімна панель для кріплення БЖ, драйвера й плат на стійках. Простішої форми, але не дешевший за старий металевий бокс. Перед покупкою потрібна розкладка деталей із зазорами для дротів і вентиляцією. Не складати плати вільно на дно. Металеву панель і PE блока заземлюють. |

### TNSy

| Деталь | Кількість | Сума | Статус |
|---|---|---|---|
| [DIN-рейка 35 мм, готовий відрізок 10 см](https://tnsy.com.ua/product/din-rejka-10sm-0-8mm-5mod-ocinkovannaya-tnsy/) | 1 | 5,3 грн | Для двох тримачів ETI й двох упорів. Рейку прикрутити до монтажної панелі. |
| [Кабельний ввід PG9, діаметр кабелю 4–8 мм](https://tnsy.com.ua/product/salnik-pg-9-latunnyj-tnsy/) | 4 | 144,32 грн | Попередня кількість для круглих кабелів. Один кабель на ввід; перевірити зовнішній діаметр. USB зі штекером потребує окремого проходу. Великий отвір свердлить монтажник. |
| [Упор на DIN-рейку 35 мм TNSy5500009](https://tnsy.com.ua/product/ogranichitel-na-din-rejku-metallicheskij-tnsy/) | 2 | 11,46 грн | По одному з кожного боку ряду тримачів. Фіксація гвинтом. |

### E-COMPS

| Деталь | Кількість | Сума | Статус |
|---|---|---|---|
| [SIBA 179020.5 — F1, 5 А, 5×20 мм](https://e-comps.com.ua/uk/siba-1790205/) | 5 | 167,1 грн | Мінімальне замовлення 5 шт.: один у гілку DM556, чотири запасні. Ціна з ПДВ. Виробник указує 125 В DC. Номінал кандидат: перевірити пусковий струм драйвера на стенді. |
| [SIBA 179020.1 — F2, 1 А, 5×20 мм](https://e-comps.com.ua/uk/siba-1790201/) | 4 | 68,92 грн | Мінімальне замовлення 4 шт.: один перед XL7015, три запасні. Ціна з ПДВ. Захист гілки живлення, не гарантія захисту напівпровідника від усіх несправностей. |
| [Gembird PC-186A-VDE — готовий мережевий шнур C13, 1,8 м](https://e-comps.com.ua/uk/gembird-pc-186a-vde/) | 1 | 409,92 грн | Ціна з ПДВ. 3×0,75 мм², вилка із заземленням. Увімкнення в панельний C14, не прямо в S-250-36. |

### KaratLTD

| Деталь | Кількість | Сума | Статус |
|---|---|---|---|
| [ETI ESC-SFR.4 (003903057), тримач запобіжника 5×20 на DIN-рейку](https://karatltd.com.ua/vse-dlia-montazhu-instrument/klemnyky-ta-klemni-kolodky/klema-gvintova-pid-zapobizhnik-5x20-esc-sfr-4-4-mm2-sira) | 2 | 192,8 грн | Два тримачі, по одному для F1 і F2. Гвинтові клеми без паяння, до 6,3 А. Запобіжники SIBA купуються окремо. Монтувати поряд, закрити відкритий торець ESC-SFR.4/PT, затиснути ряд упорами. Номінали 1/5 А не змінено; мережевий F0 це інша позиція. |

### Електроконтроль

| Деталь | Кількість | Сума | Статус |
|---|---|---|---|
| [ETI ESC-SFR.4/PT (003903060), торцева кришка](https://ecshop.com.ua/ua/p81021-zamikayushchaya_krishka_eti_3903060_esc-sfr-4-pt_dlya_esc-sfr-4) | 1 | 24,44 грн | Одна кришка для відкритого торця двох суміжних тримачів. У цьому магазині мінімальне замовлення 500 грн: окремо ця позиція поріг не проходить. Попросити додати артикул 003903060 до замовлення тримачів у KaratLTD; їхню ціну й наявність ще не підтверджено. |

### Уточнюється

| Деталь | Кількість | Сума | Статус |
|---|---|---|---|
| Кріплення Canon у портреті, перехідна пластина | 1 | 700 грн | Плановий резерв; не підібраний готовий комплект |
| Кожух руху й упори | 1 | 600 грн | Плановий резерв; не підібраний готовий комплект |
| Мережевий монтаж, F0 та кожух контактів — робота й невизначені деталі | 1 | Ціна уточнюється | Не замовлено; рішення й ціна ще уточнюються. |
| Сталева мішень двох індуктивних датчиків та її кріплення | 1 | Ціна уточнюється | Не замовлено; рішення й ціна ще уточнюються. |

## Перед складанням

- Кошторис містить кандидатів на монтаж, не перевірений готовий комплект.
- PC817/EL817: перевірити ізоляцію й вихід 0–5 В; X2 ULN2003 — прозвонити.
- Номінали захисту, мережевий монтаж, корпус і вентиляція потребують перевірки.
- [Інструменти та вибір «Позичу»](../../dashboard/camera-module/assembly-shopping.html). Деталі з цієї сторінки вже включені сюди, не додавати повторно. Інструменти рахуються окремо.
- [Архів P1](archive/P1-PIN-PURCHASES.md) — не для закупівлі.

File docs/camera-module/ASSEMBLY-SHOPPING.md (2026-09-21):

# Інструменти та монтаж вертикального модуля

Позначте, що купуємо, що позичите та що не потрібно. Нижче автоматично збираються замовлення за магазинами. Вісім указаних інструментів уже виключено.

## Інструменти

| Позиція | Кількість | Ціна | Сума | Рішення | Примітка |
|---|---|---|---|---|---|
| [Паяльний набір ANENG SL106 PRO](https://arduino.ua/prod8622-payalnii-nabir-aneng-sl106-pro) | 1 | 557,00 грн | 557,00 грн | Купити | Паяльник, підставка, 5 жал, пінцет, припій і каніфоль уже в комплекті. Для небагатьох з’єднань плат. |
| [Інструмент для обтиску наконечників (0.25-6 мм) INTERTOOL HT-7051](https://arduino.ua/prod8409-instryment-dlya-obtisky-nakonechnikiv-0-25-6-mm-intertool-ht-7051) | 1 | 999,00 грн | 999,00 грн | Купити | Обтиск втулкових наконечників 0,25–6 мм². Не підходить для дрібних контактів XH/Dupont або плоских Faston. |
| [Знімач ізоляції автоматичний Intertool HT-7020](https://arduino.ua/prod3185-semnik-izolyacii-avtomaticheskii-intertool-ht-7020) | 1 | 469,00 грн | 469,00 грн | Купити | Знімати ізоляцію й різати дроти. |
| [Цифровий мультиметр UNI-T UT-33C+ (термопара)](https://arduino.ua/prod4265-cifrovoi-myltimetr-uni-t-ut-33c-termopara) | 1 | 814,00 грн | 814,00 грн | Купити | Перевіряти 12/36 В та цілісність дротів. Щупи й батарейки перевірити у власному комплекті; окрему покупку батарейок виключено. |
| [Окуляри захисні INTERTOOL SP-0021](https://arduino.ua/prod5702-okylyari-zahisni-intertool-sp-0021) | 1 | 26,00 грн | 26,00 грн | Не потрібно | Виключено з покупки за вашим рішенням. Захист очей під час свердління та обрізання дротів. |
| [Набір свердел HSS по металу 13шт INTERTOOL SD-0013](https://arduino.ua/prod2837-nabor-sverl-hss-po-metally-13sht-intertool-sd-0013) | 1 | 99,00 грн | 99,00 грн | Купити | Отвори під кріплення плат. Не вистачає для великих отворів під кабельні вводи. |
| [Набір викруток 6 од. Ergo-design INTERTOOL VT-2005](https://arduino.ua/prod2824-nabor-otvertok-6-ed-ergo-design-intertool-vt-2005) | 1 | 199,00 грн | 199,00 грн | Не потрібно | Виключено з покупки за вашим рішенням. Основні хрестові та плоскі викрутки. |
| [Набір годинникових викруток 6 шт. INTERTOOL HT-0436](https://arduino.ua/prod3186-nabor-chasovih-otvertok-6-sht-intertool-ht-0436) | 1 | 169,00 грн | 169,00 грн | Не потрібно | Виключено з покупки за вашим рішенням. Малі клеми й регулювання перетворювача. |
| [Набір Г-подібних шестигранних ключів 9 шт. Cr-V INTERTOOL HT-0601](https://arduino.ua/prod2631-nabor-g-obraznih-shestigrannih-kluchei-9-sht) | 1 | 99,00 грн | 99,00 грн | Не потрібно | Виключено з покупки за вашим рішенням. Муфта, кронштейн двигуна та гвинти під шестигранник. |
| [Ключ розвідний 150 мм, Cr-V, чорний, фосфатований, INTERTOOL XT-0056](https://arduino.ua/prod6301-kluch-rozvidnii-150-mm-cr-v-chornii-fosfatovanii-intertool-xt-0056) | 1 | 122,00 грн | 122,00 грн | Не потрібно | Виключено з покупки за вашим рішенням. Утримувати гайки кріплень і датчиків. |
| [Термофен 300Вт 220В](https://arduino.ua/prod3021-termofen-300vt-220v) | 1 | 269,00 грн | 269,00 грн | Не потрібно | Виключено з покупки за вашим рішенням. Усаджувати ізоляційні трубки без відкритого полум’я. |
| [Лужні батарейки Videx AAA / LR03, 4 шт.](https://arduino.ua/prod7543-batareika-lyjna-videx-lr03aaa-4sht) | 1 | 59,00 грн | 59,00 грн | Не потрібно | Виключено з покупки за вашим рішенням. Дві для мультиметра, дві запасні. |
| [Бокорізи для електроніки, комбіновані INTERTOOL HT-7027](https://arduino.ua/prod7675-bokorizi-dlya-elektroniki-kombinovani-intertool-ht-7027) | 1 | 139,00 грн | 139,00 грн | Купити | Підрізати тонкі дроти й стяжки; не різати сталеві болти. |
| [Рулетка з металевим полотном 5мx19мм "Супер Магніт" blister INTERTOOL MT-0305](https://arduino.ua/prod3715-ryletka-s-metallicheskim-polotnom-5m-x-19mm-syper-magnit-blister-intertool-mt-0305) | 1 | 69,00 грн | 69,00 грн | Не потрібно | Виключено з покупки за вашим рішенням. Розмітка розташування елементів. |
| [Шуруповерт акумуляторний 12 В INTERTOOL DT-0310](https://arduino.ua/prod2473-shyrypovert-akkymylyatornii-12-v-intertool-dt-0310) | 1 | 899,00 грн | 899,00 грн | Купити | Свердління монтажної панелі. Перед оплатою звірити, що відвантажують комплект з акумулятором і зарядним пристроєм. |

До покупки: 3 976,00 грн

## Корпус і кріплення

| Позиція | Кількість | Ціна | Сума | Рішення | Примітка |
|---|---|---|---|---|---|
| [Набір нейлонових чорних шестигранних стійок М3 180шт](https://arduino.ua/prod1452-nabor-neilonovih-chernih-shestigrannih-stoek-m3-180-sht) | 1 | 239,00 грн | 239,00 грн | Купити | Нейлонові стійки 10 мм для плат з отворами M3. Гвинти та гайки є в наборі; не свердлити плати для збільшення отворів. |
| [Набір латунних стійок М2 з гвинтами 260шт в органайзері](https://arduino.ua/prod1482-nabor-latynnih-stoek-m2-s-vintami) | 1 | 298,00 грн | 298,00 грн | Купити | Стійки M2 з гвинтами й гайками для малих отворів Nano. Перевірити зазор до доріжок; не заміняти ними ізоляційний бар’єр. |
| [Пластиковий ABS-бокс 300×400×170 мм з монтажною панеллю](https://svitlahata.in.ua/ua/p2845962477-korpus-schit-plastikovij.html) | 1 | 1 200,00 грн | 1 200,00 грн | Пізніше | Знімна панель для кріплення БЖ, драйвера й плат на стійках. Простішої форми, але не дешевший за старий металевий бокс. Перед покупкою потрібна розкладка деталей із зазорами для дротів і вентиляцією. Не складати плати вільно на дно. Металеву панель і PE блока заземлюють. |
| [DIN-рейка 35 мм, готовий відрізок 10 см](https://tnsy.com.ua/product/din-rejka-10sm-0-8mm-5mod-ocinkovannaya-tnsy/) | 1 | 5,30 грн | 5,30 грн | Купити | Для двох тримачів ETI й двох упорів. Рейку прикрутити до монтажної панелі. |
| [Кабельний ввід PG9, діаметр кабелю 4–8 мм](https://tnsy.com.ua/product/salnik-pg-9-latunnyj-tnsy/) | 4 | 36,08 грн | 144,32 грн | Купити | Попередня кількість для круглих кабелів. Один кабель на ввід; перевірити зовнішній діаметр. USB зі штекером потребує окремого проходу. Великий отвір свердлить монтажник. |

До покупки: 686,62 грн

## Живлення та захист

| Позиція | Кількість | Ціна | Сума | Рішення | Примітка |
|---|---|---|---|---|---|
| [SIBA 179020.5 — F1, 5 А, 5×20 мм](https://e-comps.com.ua/uk/siba-1790205/) | 5 | 33,42 грн | 167,10 грн | Купити | Мінімальне замовлення 5 шт.: один у гілку DM556, чотири запасні. Ціна з ПДВ. Виробник указує 125 В DC. Номінал кандидат: перевірити пусковий струм драйвера на стенді. |
| [SIBA 179020.1 — F2, 1 А, 5×20 мм](https://e-comps.com.ua/uk/siba-1790201/) | 4 | 17,23 грн | 68,92 грн | Купити | Мінімальне замовлення 4 шт.: один перед XL7015, три запасні. Ціна з ПДВ. Захист гілки живлення, не гарантія захисту напівпровідника від усіх несправностей. |
| [ETI ESC-SFR.4 (003903057), тримач запобіжника 5×20 на DIN-рейку](https://karatltd.com.ua/vse-dlia-montazhu-instrument/klemnyky-ta-klemni-kolodky/klema-gvintova-pid-zapobizhnik-5x20-esc-sfr-4-4-mm2-sira) | 2 | 96,40 грн | 192,80 грн | Купити | Два тримачі, по одному для F1 і F2. Гвинтові клеми без паяння, до 6,3 А. Запобіжники SIBA купуються окремо. Монтувати поряд, закрити відкритий торець ESC-SFR.4/PT, затиснути ряд упорами. Номінали 1/5 А не змінено; мережевий F0 це інша позиція. |
| [Gembird PC-186A-VDE — готовий мережевий шнур C13, 1,8 м](https://e-comps.com.ua/uk/gembird-pc-186a-vde/) | 1 | 409,92 грн | 409,92 грн | Купити | Ціна з ПДВ. 3×0,75 мм², вилка із заземленням. Увімкнення в панельний C14, не прямо в S-250-36. |
| [Панельний вхід C14 з вимикачем і відсіком 5×20](https://arduino.ua/prod6028-rozm-jivlennya-220v-z-vimikachem-ta-zapobijnikom-10a) | 1 | 53,00 грн | 53,00 грн | Купити | Кандидат для монтажника. Комплектний запобіжник 10 А не затверджений для нашого вузла. Потрібні ізольовані внутрішні з’єднання, кожух контактів та вибір мережевого F0 за пусковим струмом БЖ. |
| [ETI ESC-SFR.4/PT (003903060), торцева кришка](https://ecshop.com.ua/ua/p81021-zamikayushchaya_krishka_eti_3903060_esc-sfr-4-pt_dlya_esc-sfr-4) | 1 | 24,44 грн | 24,44 грн | Купити | Одна кришка для відкритого торця двох суміжних тримачів. У цьому магазині мінімальне замовлення 500 грн: окремо ця позиція поріг не проходить. Попросити додати артикул 003903060 до замовлення тримачів у KaratLTD; їхню ціну й наявність ще не підтверджено. |
| [Упор на DIN-рейку 35 мм TNSy5500009](https://tnsy.com.ua/product/ogranichitel-na-din-rejku-metallicheskij-tnsy/) | 2 | 5,73 грн | 11,46 грн | Купити | По одному з кожного боку ряду тримачів. Фіксація гвинтом. |

До покупки: 927,64 грн

## Опторозв’язка

| Позиція | Кількість | Ціна | Сума | Рішення | Примітка |
|---|---|---|---|---|---|
| [Оптоплата PC817 / EL817, вхід 12 В, одноканальна](https://rozetka.com.ua/ua/mini-kompyuteri-bez-brenda-152518050/p551339865/) | 2 | 72,00 грн | 144,00 грн | Купити | Дві плати з попереднього списку P2, не додаткові дві. Замість дорогої DFR0912. У продавця немає повної принципової схеми: перед підключенням до Nano перевірити ізоляцію входу/виходу, позначення клем і перемикання сигналу 0–5 В. Схема P2 залишається кандидатом, якість конкретної партії не підтверджена. |

До покупки: 144,00 грн

## Рішення та межі готовності

- Вибір у кнопках зберігається лише в цьому браузері й не означає, що товар куплено. Для перенесення списку використайте файл замовлення. Ця сторінка — інструменти та монтажне доповнення до списку електроніки P2; не повний кошторис будки.
- Інструменти до покупки за замовчуванням: 3 976 грн. Вісім виключених позицій: 1 012 грн. Позичене та відкладене не входить у суму покупки.
- Замість DFR0912 лишаються дві оптоплати PC817/EL817 по 72 грн із попереднього P2. Не купувати їх повторно при об’єднанні списків. Підключення перевіряється на фактичній платі; клеми 12 В не з’єднувати з входом Nano напряму.
- Тримачі F1/F2: ETI ESC-SFR.4, 2 × 96,40 грн; кришка 24,44 грн; два упори 11,46 грн; рейка 5,30 грн. Разом монтаж тримачів 234 грн, без самих запобіжників і доставки. Документація ETI: https://www.eti.si/images/product_db/documents/sl-SI/ETICONNECT_ENG.pdf . Виробник указує AC/DC і струм до 6,3 А. Для 36 В використовуємо запобіжники з підтвердженим DC-номіналом.
- Дешеву гільзу Arduino ASC196 за 14 грн не обрано: не вказано допустиму DC-напругу, є скарги на нагрів контактів. Автомобільні тримачі на 32 В не замінюють тримач для нашої лінії 36 В.
- Пластиковий бокс 300×400×170 — кандидат за 1 200 грн, відкладений до перевірки розкладки. БЖ 215×115×50 мм, DM556 та плати монтуються на знімній панелі, плати — на стійках. Потрібні розділення 230 В і логіки, вентиляція, захищені мережеві контакти. Герметично закривати працюючий вузол без теплової перевірки не можна.
- Готовий шнур C13 підключається до входу C14 на корпусі. Внутрішнє підключення S-250-36 до мережі, PE, кожух контактів та F0 ще потребують завершення електриком. F1/F2 захищають гілки 36 В і не замінюють мережевий захист. Вартість незавершених позицій і роботи не включена в підсумок.
- Ціни E-COMPS включають 20% ПДВ. Доставка й мінімальні суми замовлення рахуються окремо; для кришки в Електроконтролі мінімум 500 грн. Не докуповуйте зайві товари лише заради порогу — кришку варто об’єднати з тримачами після відповіді продавця.
- HT-7051 обтискає втулкові наконечники, а не XH/Dupont/Faston. Для кількох з’єднань ULN2003 можливе паяння після перевірки розташування контактів X2.

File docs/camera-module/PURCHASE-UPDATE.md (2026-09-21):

# Поточна конструкція та запит на закупівлю · 20.09.2026

Богдан надіслав запит CNCPROM. Очікуємо відповідь, оплати й підтвердженого замовлення ще немає.

ПК USB → Arduino Nano (живлення USB) → буфер сигналів → DM556 → двигун. Один механічний HOME; протилежна межа програмна. Прошивки немає.

## Конструкція

- TBD45-700 вертикально; Canon R50 у портретній орієнтації на каретці. Кріплення Canon ще потребує підбору.
- Двигун 57BYG250C-8 через LJZ8-DS45-57 та муфту 8×12 D25L30. Посадки, довжини гвинтів і комплектність підтверджує продавець.
- Один механічний кінцевик нерухомо біля нижньої межі. Каретка натискає його до механічного упору. Отвори й натискач після вибору вимикача; 3D показує принцип, не присадку.
- Після запуску координата невідома: обмежений пошук HOME, від’їзд, повільний повторний підхід. Інша межа програмна; пропуск кроків без енкодера автоматично не виявляється. Прошивка не реалізована.
- Кабелеукладач 25×38 мм, 1 м, кінцеві кріплення. Три кабелі: USB камери, низьковольтне живлення камери, sync 3,5 мм. Блок живлення камери нерухомий; 230 В у ланцюг не заводимо. Радіуси й ресурс саме цих кабелів ще перевірити.
- S-250-36 живить DM556. Nano живиться від USB ПК. Підготовку мережевого підключення запитано в продавця.
- Аварійну кнопку та окреме утримання не замовляємо за рішенням користувача. Поведінка каретки без струму невідома — запитано продавця. Програмна зупинка не утримує знеструмлену вісь.
- Кріплення осі до каркаса відкладене. Авторську геометрію кабінки не перебудовано.

## Кошторис

Сім основних позицій CNCPROM за раніше знайденими цінами: **9183 грн**. Це не рахунок продавця.
Кінцевик, комплект кріплення та підготовка БЖ — **ціна очікується**, не 0 грн.
Arduino й електроніка закуповуються окремо. Резерви на монтаж і кріплення Canon не означають підібраного готового набору.

[Поточні позиції та статуси](order.json). [3D і кошторис](../../dashboard/camera-module/index.html).

## Очікуємо від CNCPROM

- Сумісність семи основних деталей
- Комплект і розміри кріплення
- Модель і монтаж механічного кінцевика
- Підготовка блока живлення та доплата
- Чи опускається каретка без живлення
- Остаточний рахунок і наявність

---
## Історія попереднього підбору (не чинний кошик)

# Уточнення покупки · 20.09.2026

## Повторна перевірка вузла кронштейна та живлення

LJZ8-DS45-57 ставиться на торець TBD45 біля приводного вала. Креслення продавця: 4 прохідні Ø6 на 30×30 у кронштейні збігаються з 4 M5 на 30×30 у модулі; двигун має 4 прохідні отвори на 47×47, кронштейн — 4 M5×0.8 на 47×47. Окремі гайки в цих двох з'єднаннях не потрібні: різьба вже в деталях. Це не кріплення рейки до каркаса.

На сторінці кронштейна продавець пропонує DIN7991 M5×10, https://cncprom.ua/p786078400-vint-potajnoj-golovkoj.html (21-045, 5 грн). Це гвинт, не гайка. Наявність у супутніх товарах не доводить посадку: на кресленні кронштейна не задано конічне заглиблення та глибину різьби. Тому не підтверджено, що DIN7991 M5×10 або раніше запропоновані DIN912 підходять для кожного місця без примірки. Набір DIN912 не є затвердженою остаточною специфікацією.

S-250-36 — блок із гвинтовими клемами, а не адаптер із готовим шнуром. Для вводу мережі кандидат: E.NEXT l020012, 3×0.75 мм², Schuko із захисним контактом, 1.2 м, вільні кінці; https://shop220.com.ua/products/shnur-s-vilkoi-3kh0-75-1-2m-chernyi-e-wire-plug-black-0-75 — 111.21 грн, доступний до замовлення. Потрібні також належні наконечники під фактичні клеми, затиск зовнішньої оболонки кабелю, захищений вентильований відсік/кожух та мережевий захист, номінал якого ще не визначено. Одна покупка шнура не завершує мережевий монтаж. Перемикач блока встановлюється на 230 В до підключення. Монтаж мережевої частини має виконати компетентний електрик.

Nano живиться від USB ПК тим самим Mini-B кабелем, який передає команди. Окремий адаптер чи перетворювач 36→5 В у цьому варіанті не потрібний. 36 В підключаються тільки до силового входу DM556. Якщо USB ПК вимкнено, контролер не працює; це врахувати в прошивці/налаштуванні ПК.

## Додаток: гвинти та зменшення паяння

До списку закупівлі додано METIZPRICE, DIN912 12.9 без покриття, по 4 шт. кожної довжини для примірки (не всі встановлюються):
- M5×10, 2.31 грн/шт.: https://metizprice.com.ua/din912-vint-m5h10-cilgl-129-bp-inb.html
- M5×12, 2.19 грн/шт.: https://metizprice.com.ua/din912-vint-m5h12-cilgl-129-bp-inb.html
- M5×16, 0.96 грн/шт.: https://metizprice.com.ua/din912-vint-m5h16-cilgl-129-bp-inb.html
- M5×20, 1.11 грн/шт.: https://metizprice.com.ua/din912-vint-m5h20-cilgl-129-bp-inb.html
Разом за 16 гвинтів 26.28 грн без доставки та шайб. Сторінки товарів зазначають наявність. Це доповнення списку, не оформлене замовлення. Точні встановлювані довжини залишаються залежними від фактичних глибин різьб.

Варіант зі збереженням електроніки на Arduino.ua: замість окремої ULN2003AN за 11 грн взяти зібрану плату ULN2003 за 34 грн https://arduino.ua/prod280-draiver-shagovogo-dvigatelya-uln2003 . Вона лише буфер сигналів до DM556, не заміна DM556. Вихідні дроти треба під'єднати до відповідного роз'єму або припаяти; паяння базової монтажної плати Nano залишається. Заміна збільшує попередній кошик електроніки з 489 до 512 грн, без додаткових кабелів-перемичок.

Альтернатива з меншим паянням, але іншим продавцем: готовий Nano Screw Shield https://ledplus.com.ua/ua/p1373164845-shild-arduino-nano.html — 64.40 грн, готовий до відправки; мінімальне замовлення 200 грн. Замість базової монтажної плати та шести клемників. На Arduino.ua аналог AOC457 наразі очікується. Не купувати обидва варіанти основи. Плата ULN та кінцевики все одно потребують з'єднання дротами. Готові перемички для коротких сигнальних з'єднань: https://arduino.ua/prod220-nabor-peremichek-mama-mama-200mm-40-sht — 43 грн/40 шт.; не для силового кола і не для прокладання в рухомому ланцюгу. Кріплення роз'ємів та ізоляція необхідні при остаточному складанні. Цей варіант не є випробуваним комплектом без паяння.

## Актуальне уточнення: одне замовлення електроніки на Arduino.ua

Користувач дозволив поки виключити кріплення рейки до каркаса. Електроніку купувати на Arduino.ua. Попередній варіант клемної плати із Солдер замінено: AOC457 на Arduino.ua очікується, тому пропонується паяна монтажна плата. Це не готовий зібраний контролер.

Список низьковольтної частини керування (ціни зі сторінок магазину, без доставки):

| Позиція | Кількість | Сума, грн | Посилання |
|---|---:|---:|---|
| Nano APC104 | 1 | 179 | https://arduino.ua/prod166-arduino-nano-v3-0-avr-atmega328p-z-rozpayanimi-konektorami |
| USB A — Mini B 0,8 м | 1 | 54 | https://arduino.ua/prod892-usb-2-0-kabel-am-miniusb-0-8m-atcom-s-ferritom |
| Склотекстолітова монтажна плата 50×70 SKV230 | 1 | 24 | https://arduino.ua/prod1859-maketnaya-plata-dvyhstoronnyaya-50h70mm |
| Клемник KF301-2P SKV140 | 6 | 30 | https://arduino.ua/prod428-klemnik-podviinii-5mm-kf301-2p |
| ULN2003AN DIP | 1 | 11 | https://arduino.ua/prod431-mikroshema_uln2003an |
| Кінцевик KW11-3Z-7 TDC135 | 2 | 24 | https://arduino.ua/prod1637-mehanicheskii-koncevoi-vikluchatel-kw11-3z |
| Сигнальний трижильний провід 22AWG, 1 м | 3 | 165 | https://arduino.ua/prod2651-kabel-trehjilnii-dlya-servoprivodov-1m |
| Резистори 1 кОм 0,25 Вт, 5 шт. SKV245 | 1 пачка | 2 | https://arduino.ua/prod1969-rezistor-1-kom-5-shtyk |

Разом 489 грн. Це не ціна повного ліфта. Nano і ULN паяються на плату, окремі панельки не включені. Шість подвійних клемників — 12 контактів: до шести для PUL/DIR/ENA та чотири для двох кінцевиків, решта резерв. Резистори 1 кОм — зовнішні підтягування входів кінцевиків до 5 В. Механічні кінцевики замінюють попередній індуктивний HOME у цьому варіанті, а не доповнюють його. Їхні кріплення та точки натискання ще потрібно визначити при монтажі. Трижильний кабель тут лише для низьковольтних сигналів, не для мережі чи силового кола двигуна.

ULN2003AN використовується як буфер відкритого колектора для оптовходів DM556 (не драйвер самого двигуна). Живлення логіки 5 В від USB; силове 36 В лише для DM556. Підтверджена відповідність типів інтерфейсів за документацією продавця; зібрана схема, прошивка, завадостійкість і робота під навантаженням не випробувані. Паяльні витратні матеріали, ізоляція, корпус, стійки плати, мережевий ввід та силові дроти не включені в ці 489 грн.

Нижче збережено попереднє дослідження; воно не є актуальним кошиком Arduino.ua.

Поточні вимоги Богдана: залишити TBD45-700; контролер можна купити в іншому магазині; паяння дозволене. У рухомому кабелеукладачі три кабелі: USB камери (припущення щодо третього кабелю), низьковольтний вихід мережевого адаптера Canon і синхрокабель 3,5 мм. Блок живлення камери залишається нерухомим. Кнопку аварійної зупинки та механічне утримання користувач виключив із закупівлі. Це не підтверджує безпеку або утримання каретки без струму. Попередній кошик із резервами на ці позиції більше не є актуальним списком замовлення.

## Контролер

- Arduino Nano V3.0 ATmega328P з розпаяними контактами, APC104 — 1 шт., 179 грн, на сторінці в наявності: https://arduino.ua/prod166-arduino-nano-v3-0-avr-atmega328p-z-rozpayanimi-konektorami
- Розпаяний Nano Screw Shield — 1 шт., на сайті Солдер/ledplus: https://ledplus.com.ua/ua/p1373164845-shild-arduino-nano.html
- USB-A → Mini-B, передача даних, 1 шт.; в комплект Arduino.ua не входить. Довжина за відстанню від ПК до нерухомого контролера.
- Nano — контролер, не драйвер двигуна. DM556 лишається потрібним. Потрібно записати прошивку; вона ще не розроблена й не випробувана для цього набору. Не живити Nano від 36 В. Остаточний інтерфейс HOME залежить від обраного датчика; ця покупка не закриває його узгодження.

## Кабелеукладач

Кандидат: 25×38 мм відкритий, CNCPROM 34-032, 1 м, 584 грн з кінцевими кріпленнями: https://cncprom.ua/ua/p1671300145-gibkij-kabel-kanal.html

Для оцінки місткості прийняті зовнішні діаметри кабелів 5, 4 і 3 мм (не виміряні). Разом 12 мм ширини, місця достатньо. На сторінці вказано внутрішній діаметр вигину 70 мм (радіус 35 мм), зовнішній 150 мм. Це не R60 попередньої 3D-моделі. Придатність конкретного USB до повторних згинів не підтверджена. Феритові потовщення та блок живлення не класти у згин. Геометрію ланцюга в 3D за цим кандидатом ще не змінено.

## Кріплення

За кресленнями продавця: двигун має 4 отвори Ø5 на квадраті 47×47; LJZ8 має 4 різьби M5 та модульну сторону 30×30 із прохідними отворами Ø6; торець TBD45 має 4 M5 на квадраті 30×30. Для цих двох з'єднань потрібно 8 гвинтів M5 загалом. Глибини різьб не вказані, тому точні довжини не підтверджені.

Для примірки можна взяти DIN 912 M5×10, ×12, ×16, ×20 по 4 шт. і 8 плоских шайб M5. Це набір довжин, не твердження, що всі 16 гвинтів входять у складання. Не затягувати гвинт, який уперся в дно отвору.

Готові монтажні лапи/закладні гайки для задніх пазів TBD45 до каркаса 20×20 не знайдені з підтвердженою посадкою. Гайки «серії 45, паз 10» автоматично не підходять. Каркасні гайки для профілю 20×20 і гайки для TBD45 не ототожнювати. Цей пункт лишається відкритим; виробничих креслень кріплення немає.

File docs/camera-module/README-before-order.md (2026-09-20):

# Модуль Canon R50 · 700 мм

Дата: 20.09.2026. Статус: інженерне компонування для прототипу, не виробничий випуск.

Інтерактивна модель: `dashboard/camera-module/index.html`. Огляд для друку: `dashboard/camera-module/review.html`. Таблиця цін: `dashboard/camera-module/bom.json`.

Вхідне ТЗ: вертикальний TBD45-700, 57BYG250C-8, LJZ8-DS45-57, муфта 8×12 D25L30, 36 В, STEP/DIR, HOME NPN, USB MCU, портретний Canon R50, автоматичне наведення по голові. Текст ТЗ збережений поруч у `brief.txt`.

Обрано для першого стенду: 80 мм/с, 300 мм/с², 1/8 кроку, робочі межі 20–680 мм, HOME 10/3 мм/с, пауза перед фото 400 мс. Це початкові параметри для випробувань, не паспорт готової системи. Браузерна симуляція не керує апаратурою та не замінює прошивку MCU.

Напрямна 45×45×820 мм і каретка 104×90×26 мм взяті з продавця. Монтажні пластини, опори, місця болтів, контури кронштейна двигуна та камери умовні. Потрібні заводські креслення й перевірка посадки муфти. Камера показана вертикально. Зона кабелеукладача потребує близько 1000 мм; вікно для об’єктива при ході 700 мм — орієнтовно не менше 790 мм.

Новий вузол показано окремо. Габарити авторської кабінки та файл `БУДКА.blend` не змінені; інтеграцію нового ходу 700 мм із вирізом, освітленням і посадкою людини ще треба узгодити. У кошторисі не потрібно купувати одночасно старий TBD45-500 і новий TBD45-700.

П’ять позицій із перевіреними цінами: 7 925 грн. Плановий кошик з умовними резервами: 25 064 грн, із запасом 10% — 27 571 грн. Камера, об’єктив, ПК, EcoFlow, доставка, робота та випробування не входять. Резерв механічного захисту 6 000 грн не є комерційною пропозицією й може змінитися.

Невирішене перед виготовленням: крива моменту при 36 В, точна ревізія й наявність драйвера, отвори/вали/муфта, незалежне утримання каретки при втраті живлення або ременя, остаточний E-STOP, фізичні випробування HOME і відеопотоку. Утримувальний момент двигуна не дорівнює робочому моменту на швидкості. Гальмо на моторі не страхує обрив ременя.

Перевірки: `node tests/camera-module.mjs`, `node scripts/check-camera-module.mjs`. Генерація огляду: `node scripts/build-camera-module.mjs`.

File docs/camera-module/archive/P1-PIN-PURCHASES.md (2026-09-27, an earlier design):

> АРХІВ P1 — ЗАСТАРІЛО. Не використовувати для закупівлі або монтажу. Актуальні дані: ../PIN-PURCHASES.md та ../PIN-WIRING.md.

# Закупівля для схеми P1: два основні магазини

Перевірка 20.09.2026. Валюта — грн. Ціни сторінок, без доставки й робіт; товар не зарезервовано. Раніше надісланий Богданом запит CNCPROM залишається без відповіді. Нові доповнення нижче **ще не надсилалися**. Не дублювати раніше замовлені позиції: підтверджених покупок у проєкті немає.

## 1. CNCPROM — механіка і силова частина

Усі 7 сторінок зараз зазначають «Готово до відправки». Посадки механіки й склад комплекту мають бути підтверджені рахунком/відповіддю продавця.

| Товар | Кількість | Ціна за од. | Разом |
|---|---|---|---|
| [TBD45-700, хід 700 мм](https://cncprom.ua/ua/p1089226920-linejnyj-modul-tbd45.html) | 1 | 4939 | 4939 |
| [57BYG250C-8](https://cncprom.ua/ua/p1312688446-dvigatel-shagovyj-57byg250c.html) | 1 | 943 | 943 |
| [LJZ8-DS45-57](https://cncprom.ua/ua/p1470346846-kronshtejn-shagovogo-dvigatelya.html) | 1 | 314 | 314 |
| [Сильфонна муфта 8×12 мм, D25 L30](https://cncprom.ua/ua/p914622727-gibkaya-silfonnaya-mufta.html) | 1 | 382 | 382 |
| [DM556](https://cncprom.ua/ua/p865450706-drajver-dm556-vdc.html) | 1 | 674 | 674 |
| [S-250-36, 36 В, 250 Вт](https://cncprom.ua/ua/p556579870-impulsnyj-blok-pitaniya.html) | 1 | 1347 | 1347 |
| [Кабелеукладач 25×38 мм, 1 м, обидва кінцеві кріплення](https://cncprom.ua/ua/p1671300145-gibkij-kabel-kanal.html) | 1 | 584 | 584 |

Разом за сім основних позицій: **9183 грн**.

У тому самому замовленні просимо підготувати наступне. Це специфікація для отримання ціни, а не підтверджені товарні картки:

| Що | Кількість / специфікація | Статус |
|---|---|---|
| Механічний HOME | 1 шт., сухі COM/NC, бажано гвинтові або обтискні клеми; кріплення й натискач | Уже запитано; модель/ціна очікуються |
| Болти, гайки, шайби | Кріплення осі до моторного кронштейна та двигуна; довжини під фактичні різьби | Уже запитано; кріплення всієї осі до каркаса відкладено |
| Підготовка S-250-36 до мережі | Шнур/вилка із PE, фіксація, закриті клеми, мережевий захист | Уже запитано; виконання/доплата не підтверджені |
| W11/W12 | Дві жили 1,0 мм² до 0,5 м, наконечники під фактичні клеми; червоний/чорний | Нове доповнення, ціна невідома |
| F1 + тримач | Кандидат 5 А, не нижче 60 В DC; уточнення номіналу за навантаженням | Конкретний товар не підібраний |
| W13–W16 | Обтиснути заводські 4 виводи мотора; якщо не вистачає 750 мм — подовження 4×0,75 мм² до 1 м | Наявність/ціна роботи невідомі |
| W09/W10 | HOME-джгут 2×0,22 мм², заготовка 1,5 м; гнізда Dupont до D4/GND, клеми до COM/NC | Нове доповнення; погодити тип контактів кінцевика |
| Колодки DM556 | Уточнити, чи штатні P1/P2 знімні та входять у комплект | Не купувати випадкові колодки іншого кроку |

## 2. Arduino.ua — Nano та сигнальні роз’єми

Усі наведені нижче товарні сторінки зазначають наявність. XH купувати як кандидат **після звірки посадки з фактичною ULN-платою**, бажано разом із виготовленим джгутом.

| Товар | Кількість | Ціна за од. | Разом |
|---|---|---|---|
| [Arduino Nano V3 з розпаяними роз’ємами](https://arduino.ua/prod166-arduino-nano-v3-0-avr-atmega328p-z-rozpayanimi-konektorami) | 1 | 179 | 179 |
| [USB-A → Mini-USB для Nano, 0,8 м](https://arduino.ua/prod892-usb-2-0-kabel-am-miniusb-0-8m-atcom-s-ferritom) | 1 | 55 | 55 |
| [Плата ULN2003 для сигналів STEP/DIR](https://arduino.ua/prod280-draiver-shagovogo-dvigatelya-uln2003) | 1 | 34 | 34 |
| [Dupont F–F 200 мм, 40 шт., AOC108](https://arduino.ua/prod220-nabor-peremichek-mama-mama-200mm-40-sht) | 1 | 43 | 43 |
| [XH 5Y з 5 контактами, FCC253 (1 робочий + 1 запасний)](https://arduino.ua/prod1319-razem-xh-2-54-5y) | 2 | 5 | 10 |

Разом за ці позиції: **321 грн**. Основні товари обох магазинів: **9504 грн**. Це не повна ціна працюючого модуля.

Додатково потрібні: виготовлення X2 з мідного проводу 0,22 мм² (орієнтовно 2 м різних кольорів із запасом), обтиск 3 задіяних контактів XH, ізольоване Y-розгалуження +5 В, наконечники до DM556; ізольований корпус Nano/ULN, утримувачі плат, стяжки, затискачі й маркери. Артикули/ціни цих матеріалів та послуга обтиску в магазині **не підтверджені**. Якщо магазин не збирає джгути — роботу виконує монтажник з цими деталями, а не купується ще один випадковий драйвер.

Для самостійного виготовлення потрібні мультиметр, стрипер, кримпер саме під відкриті XH/Dupont-контакти й окремий/відповідний кримпер під втулкові наконечники. Інструменти не включені в суму: для одного модуля доцільно отримати готові джгути. Паяльник у рекомендованій комплектації не потрібний.

## Що не купувати для цього варіанта

- [Плата Nano V3 ASC227](https://arduino.ua/prod2422-plata-rasshireniya-v3-dlya-arduino-nano) — 69 грн, очікується; у нашій схемі не потрібна.
- [Клемний адаптер Nano AOC457](https://arduino.ua/prod1708-plata-adaptera-dlya-arduino-nano-v3-0) — 59 грн, очікується; роз’єми не припаяні. Не видавати його за готовий безпаєчний шилд.
- [Великий набір XH AOC679](https://arduino.ua/prod3546-komplekt-razyomov-jst-xh2-54-2p-3p-4p-5p-v-organaizere) — 99 грн, очікується; окремого FCC253 достатньо після звірки.
- 28BYJ-48, A4988, DRV8825, додатковий 36→5 В перетворювач — не потрібні в цій архітектурі.
- Dupont/JST-XH не використовувати для 3-амперних фаз двигуна або живлення 36 В.

## Межі кошика

Камера Canon R50, сумісний DC-coupler/адаптер, USB-C кабель із підтвердженим ресурсом згинів, AD-E1/контактний sync-адаптер і кабель до Godox не підтверджені як набір із CNCPROM та Arduino.ua. Їхню розпайку не замінюємо довільними пінами. У реєстрі живлення Canon та остаточний sync-комплект залишаються відкритими; окремий третій магазин без потреби не нав’язуємо.

Резерви на кріплення Canon (700 грн), рухомі кабелі (900 грн) і кожух/упори (600 грн) залишаються оцінками. Старий нерозкладений резерв монтажу 500 грн вилучено із суми та замінено конкретними відомими позиціями і невідомими цінами джгутів/корпусу — подвійного рахунку немає. Повний підсумок **невідомий** до отримання цін робіт і решти деталей.

[Схема, контакти та обтиск](PIN-WIRING.md). Джерела цін — прямі товарні сторінки в таблицях [B]; достатність комплекту й довжини кабелів — проєктні [C].

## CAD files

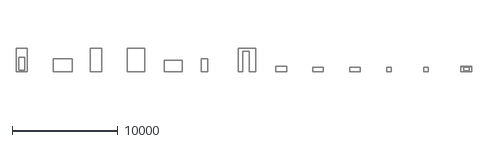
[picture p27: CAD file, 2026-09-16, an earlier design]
drawings/revision-08/panels.dxf
43040.0 x 2200.0

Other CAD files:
drawings/revision-06/panel-contours.dxf
drawings/revision-08/БУДКА-доповнена-08.blend
drawings/revision-09/БУДКА-доповнена-09.blend
drawings/revision-10/БУДКА-доповнена-10.blend
source/БУДКА.blend

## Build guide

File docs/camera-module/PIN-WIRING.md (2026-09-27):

# Вертикальний модуль камери: усі підключення · P2

> 27.09.2026: креслення-кандидат. ULN2003 виключений із покупок за попереднім рішенням, але ще присутній у схемі STEP/DIR нижче. Цю суперечність не приховуємо: перед монтажем потрібно узгодити драйверний інтерфейс. Куплений перетворювач також потребує ідентифікації.

21.09.2026. Кандидат для стенда, hardwareTested=false. За рішенням Богдана використовуємо **два індуктивні датчики**, нижній HOME та верхню межу. Ця ревізія замінює один механічний NC HOME у P1. Прошивка ще не реалізована; фактичне розведення плат опторозв’язки та ULN2003 необхідно перевірити.

[ВЕЛИКА ВІЗУАЛЬНА СХЕМА — усі деталі та дроти](../../dashboard/camera-module/visual-wiring.html)

[Попередня схема P1 — архів](PIN-WIRING-P1-archive.md). Актуальний кошторис: `docs/budget/current.json`. CNCPROM оплачено й отримано; товари 9 587 грн, разом із доставкою та комісіями 10 116,68 грн. P1 не бере участі в покупках.

## Що є на схемі

| Деталь | Кількість | Призначення |
|---|---|---|
| Комп’ютер | 1 | USB-команди до Arduino та керування камерою |
| Arduino Nano ATmega328P 5 В | 1 | Формує кроки двигуна, читає два датчики; живиться USB від ПК |
| ULN2003 | 1 | Буфер STEP/DIR; не замінює опторозв’язку датчиків |
| DM556 | 1 | Драйвер двигуна |
| 57BYG250C-8 | 1 | Двофазний кроковий двигун, чотири жили |
| S-250-36 | 1 | 36 В для DM556 та входу XL7015 |
| XL7015, вихід 12 В | 1 | Знижує 36 В для обох датчиків |
| HURON LJ12A3-4-Z/BX, NPN NO | 2 | Нижня та верхня межі |
| Опторозв’язка PC817/EL817, вхід 12 В | 2 канали | Відокремлює сигнали датчиків від Nano; конкретна плата потребує перевірки |
| Клемні розгалужувачі, запобіжники F1/F2 з тримачами | За монтажем | Розведення живлення, захист гілок; номінали ще не затверджені |
| TBD45-700 + LJZ8-DS45-57 + муфта 8×12 D25 L30 | По 1 | Модуль, кронштейн двигуна та муфта |
| Кутове кріплення M12 для датчика | 2 | Кріплення датчиків до профілю |
| Сталевий прапорець на каретці | 1, конструкцію уточнити | Мішень датчиків; перевірити досяжність обох сенсорів |
| Кріплення камери у портретному положенні | 1, конструкцію уточнити | З’єднує камеру з кареткою |
| Кабелеукладач 25×38 мм з кінцевими кріпленнями | 1 м, 1 комплект | Три рухомі кабелі камери |
| Canon EOS R50 + Tectra LP-E17 / ACK-E18 | По 1 | Камера та живлення через муляж акумулятора |
| AD-E1 + Pixel TF-325 + PC–3,5 мм | По 1 | Куплений кандидат синхронізації; сумісність TF-325 ще не підтверджена |
| Godox MS200V | 1 | Окремо живиться 230 В; синхронізація від камери |

## Кожен провід: живлення

| ID | Звідки | Куди | Уточнення |
|---|---|---|---|
| P01 | Мережевий шнур L | S-250-36 L | Підготовку шнура, фіксацію та закриття клем замовити продавцю |
| P02 | Мережевий шнур N | S-250-36 N | Не плутати з DC 0 В |
| P03 | Мережевий шнур PE | S-250-36 PE / земля | Захисне заземлення, не GND Nano |
| P04 | S-250-36 V+ | F1 → DM556 +VDC | 36 В; F1 підібрати за навантаженням і проводом, ≥60 В DC |
| P05 | S-250-36 V− | DM556 GND силовий | Повернення силового струму |
| P06 | S-250-36 V+ | F2 → XL7015 IN+ | Вхід 36 В; F2 окремий для тоншої гілки |
| P07 | S-250-36 V− | XL7015 IN− | XL7015 не має гальванічної ізоляції |
| P08 | XL7015 OUT+ | Шина +12 В | Виміряти напругу до підключення навантаження |
| P09 | XL7015 OUT− | Шина 0 В датчиків | Не з’єднувати з Nano GND у цій схемі |
| P10 | ПК USB | Nano Mini-USB | Живлення 5 В та команди, VIN не використовуємо |

## Кожен провід: керування та двигун

| ID | Звідки | Куди | Уточнення |
|---|---|---|---|
| M01 | Nano D2 | ULN2003 IN1 | STEP, початковий LOW |
| M02 | Nano D3 | ULN2003 IN2 | DIR, початковий LOW |
| M03 | Nano 5V | ULN плата V+ / COM | Шина 5 В; перевірити плату |
| M04 | Nano GND | ULN GND | Логічна земля |
| M05 | ULN OUT1 / 1C | DM556 PUL− | Вихід першого каналу |
| M06 | ULN OUT2 / 2C | DM556 DIR− | Вихід другого каналу |
| M07 | Nano 5V | DM556 PUL+ | Розгалуження 5 В |
| M08 | Nano 5V | DM556 DIR+ | Розгалуження 5 В |
| M09 | DM556 A+ | Обмотка A, кінець 1 | Кольори визначити за паспортом/виміром |
| M10 | DM556 A− | Обмотка A, кінець 2 | Не з’єднувати з B |
| M11 | DM556 B+ | Обмотка B, кінець 1 | Кольори визначити за паспортом/виміром |
| M12 | DM556 B− | Обмотка B, кінець 2 | Не від’єднувати двигун під живленням |

ENA+/ENA− поки не підключені; перевірити штатний стан увімкнення конкретного DM556. Струм і мікрокрок встановити за його паспортом та двигуном. ULN інвертує логіку сигналу; прошивка має це врахувати. Порядок вихідного роз’єму X2 не встановлений: перевірити прозвонюванням. Для самої мікросхеми ULN2003: IN1 pin1, IN2 pin2, OUT1 pin16, OUT2 pin15, GND pin8, COM pin9 — це НЕ порядок контактів роз’єму плати.

## Кожен провід: датчики

| ID | Звідки | Куди | Уточнення |
|---|---|---|---|
| S01 | +12 В | Коричневий нижнього датчика | Живлення |
| S02 | 0 В датчиків | Синій нижнього датчика | Живлення |
| S03 | Чорний нижнього датчика | Опто №1 ВХІД − | NPN замикає вихід на 0 В |
| S04 | +12 В | Опто №1 ВХІД + | Плата з резистором, розрахована на 12 В; не гола мікросхема |
| S05 | Колектор виходу опто №1 | Nano D4 | INPUT_PULLUP, очікуваний активний LOW для відкритого колектора |
| S06 | Емітер виходу опто №1 | Nano GND | Вихідна, ізольована сторона |
| S07 | +12 В | Коричневий верхнього датчика | Живлення |
| S08 | 0 В датчиків | Синій верхнього датчика | Живлення |
| S09 | Чорний верхнього датчика | Опто №2 ВХІД − | NPN замикає вихід на 0 В |
| S10 | +12 В | Опто №2 ВХІД + | Вхід плати на 12 В |
| S11 | Колектор виходу опто №2 | Nano D5 | INPUT_PULLUP, очікуваний активний LOW |
| S12 | Емітер виходу опто №2 | Nano GND | Вихідна сторона |

S05/S06/S11/S12 — вимога до вихідного каскаду, а не перевірена розводка товарної плати. Якщо плата має VCC на виході, подавати 5 В лише за її схемою; перевірити, що вона дійсно гальванічно ізольована і має сумісний з Nano вихід. До цього не вважати схему готовою до підключення «за місцем клем».

Номінальні 4 мм датчика стосуються стандартної металевої мішені; використати сталевий прапорець і перевірити зазор. Датчики не дають неперервної координати. Висота визначається підрахунком кроків після HOME. NO не дає гарантованого виявлення обриву. Прошивці потрібні тайм-аут пошуку, повільний повторний підхід, обмеження ходу та блокування руху за спрацьовану межу.

## Кожен кабель камери

| ID | Звідки | Куди | Прокладання |
|---|---|---|---|
| C01 | ПК USB | Canon R50 USB-C | Кабелеукладач, дані |
| C02 | Розетка 230 В | Tectra ACK-E18 | Нерухомий комплектний мережевий шнур |
| C03 | Вихід Tectra | LP-E17 у камері | Низьковольтна ділянка в кабелеукладачі; перевірити комплект з R50 |
| C04 | Башмак R50 | AD-E1 → TF-325 | Непідтверджений ланцюжок, не підключати навмання |
| C05 | PC sync адаптера | Godox SYNC 3,5 мм | Кабелеукладач; лише після перевірки C04 |
| C06 | Розетка 230 В | Godox MS200V | Нерухомий штатний шнур |
| C07 | Розетка 230 В | Живлення ПК | Нерухомий штатний блок/шнур |

У кабелеукладачі лише C01, C03, C05. Перевірити довжину, натяг та вигин у крайніх положеннях. Проводи нерухомого двигуна й датчиків у цей ланцюг не потрібні.

## Що ще не підтверджено

- Фізична розводка ULN X2 та обох оптоплат. Потрібні фото фактичних плат/схеми та перевірка мультиметром.
- Номінали запобіжників, перерізи, довжини дротів та кінцеві роз’єми під реальний монтаж.
- Кріплення камери до каретки, прапорець датчиків та достатній запас до механічних упорів.
- Утримання ремінної каретки після вимкнення живлення. Датчики не запобігають падінню.
- Сумісність Pixel TF-325 у ланцюжку R50/AD-E1 і практична синхронізація спалаху.
- Прошивка, рух з вантажем і випробування. Без них не заявляємо автономну працездатність.

## Джерела деталей і контактів

- [HURON LJ12A3-4-Z/BX](https://cncprom.ua/ua/p6349268-induktivnyj-datchik-huron.html).
- [Кутове кріплення датчика](https://cncprom.ua/ua/p950274952-kronshtejn-dlya-krepleniya.html).
- [Кандидат PC817/EL817, 12 В](https://rozetka.com.ua/ua/mini-kompyuteri-bez-brenda-152518050/p551339865/): сторінка не підтверджує порядок клем і схему виходу.
- [Кандидат XL7015 на 12 В](https://rozetka.com.ua/459436819/p459436819/): під час перевірки немає в наявності; схема задає функцію перетворювача, а не підтверджує його замовлення.
- [Офіційний pinout Arduino Nano](https://docs.arduino.cc/resources/pinouts/A000005-full-pinout.pdf).
- [TI ULN2003A](https://www.ti.com/lit/ds/symlink/uln2003a.pdf).

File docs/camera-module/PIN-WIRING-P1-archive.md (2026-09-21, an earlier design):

# Вертикальний модуль: підключення пінами · P1

Дата: 20.09.2026. Статус: **CANDIDATE [C], схема для складання стенда**, hardwareTested=false. Поточний механічний комплект: TBD45-700, 57BYG250C-8, DM556, S-250-36, Canon R50. Один механічний HOME, інша межа програмна. Нових E-stop/утримувача до закупівлі не додано. Прошивка не реалізована.

[Відкрити кольорову схему](../../dashboard/camera-module/pin-wiring.html) · [SVG](../../dashboard/camera-module/pin-wiring.svg) · [Що купити](PIN-PURCHASES.md) · [Бібліотека Arduino](../knowledge/arduino/README.md)

## Принцип монтажу

Nano з припаяними гребінками та готова ULN2003 стоять нерухомо в ізольованому корпусі. Знімні гнізда Dupont на Nano, готовий/обтиснутий 5-контактний штекер на ULN, штатні клемні колодки DM556. У клемах — зачищена жила з відповідним обтиснутим наконечником; без залужування під гвинт. Паяння в рекомендованому варіанті: **0 точок**, якщо отримано готові плати та виготовлені джгути. Обтиск не є паянням; голий XH-корпус із контактами ще не є готовим кабелем.

Позначення X1–X8 і W01–W18 — наші монтажні ID. Порядок прямокутників на рисунку не повторює фізичне розташування ніжок. Підключатися за написами на платах, а не за кольором чи місцем на малюнку.

## Піни Nano

| Пін | Призначення [C] | Куди |
|---|---|---|
| Mini-USB | Команди + живлення від ПК | X1: USB-A → Mini-B, 0,8 м |
| D2 | STEP, початковий LOW | ULN2003 IN1 |
| D3 | DIR, початковий LOW | ULN2003 IN2 |
| D4 | HOME, INPUT_PULLUP | NC механічного кінцевика |
| 5V | Живлення сигнального кола | ULN2003 «+» / VCC, тільки 5 В |
| GND біля RST/D2 | Логічний загальний | ULN2003 «−» / GND |
| Другий GND біля RST/VIN | Повернення HOME | COM кінцевика |
| D0/RX, D1/TX | Залишені під USB Serial | Зовнішніх дротів немає |
| VIN, 3V3, AREF, решта GPIO | Не використовуються | Нічого не підключати |

[A] Назви пінів звірені з [офіційним pinout Nano](https://docs.arduino.cc/resources/pinouts/A000005-full-pinout.pdf). Купується класична Nano ATmega328P, а не Nano ESP32/Every/LGT8F.

## Повна таблиця проводів

Перерізи та довжини нижче — монтажна пропозиція [C], уточнюються за розташуванням відсіку. Сигнали до драйвера тримати короткими, до 0,3 м; Nano та ULN — поряд.

| ID | Звідки → куди | Монтаж / провід | Паяння |
|---|---|---|---|
| W01 | ПК USB-A → Nano Mini-B | Готовий кабель X1, 0,8 м | Ні |
| W02 | Nano D2 → ULN IN1 | Dupont F–F 2,54 мм, 20 см; сигнальний | Ні |
| W03 | Nano D3 → ULN IN2 | Dupont F–F 2,54 мм, 20 см | Ні |
| W04 | Nano 5V → ULN «+» | Dupont F–F, 20 см; червоний | Ні |
| W05 | Nano GND → ULN «−» | Dupont F–F, 20 см; чорний | Ні |
| W06 | ULN OUT1 / 1C → DM556 PUL− | X2, контакт OUT1 → обтиснутий кінець у штатну клему; 0,22 мм² | Ні |
| W07 | ULN OUT2 / 2C → DM556 DIR− | X2, контакт OUT2 → обтиснутий кінець; 0,22 мм² | Ні |
| W08 | ULN V+ вихідного роз’єму → розгалуження +5V → PUL+ і DIR+ | X2; заводський/обтиснутий Y-джгут на 2 жили, 0,22 мм². Скрутити +5/PUL− і +5/DIR− окремими парами | Ні |
| W09 | Nano D4 → HOME NC | Гніздо Dupont F → 2-жильний кабель → клема/FASTON під фактичний кінцевик | Ні |
| W10 | Другий Nano GND → HOME COM | Разом з W09 у витій парі 2×0,22 мм², заготовка 1,5 м | Ні |
| W11 | S-250-36 V+ → F1 → DM556 +VDC | X4: червоний 1,0 мм², до 0,5 м; клеми + наконечники | Ні |
| W12 | S-250-36 V− → DM556 силовий GND | X4: чорний 1,0 мм², до 0,5 м | Ні |
| W13 | DM556 A+ → двигун, кінець A1 | X5: штатна моторна колодка; заводський вивід мотора | Ні |
| W14 | DM556 A− → двигун, кінець A2 | Та сама обмотка A | Ні |
| W15 | DM556 B+ → двигун, кінець B1 | Друга обмотка B | Ні |
| W16 | DM556 B− → двигун, кінець B2 | Та сама обмотка B | Ні |
| W17 | ПК → USB-C камери R50 | X6: готовий кабель передачі даних; у рухомому ланцюзі | Ні |
| W18 | Сумісний адаптер камери → штатний DC-coupler R50 | X7: готовий низьковольтний комплект; модель ще не визначена | Ні |

X8: R50 → AD-E1 → сумісний контактний адаптер → sync-кабель → Godox MS200V. Кінцевий адаптер і розпайка конкретного sync-комплекту **не підтверджені [D]**. Залишаємо штатні роз’єми; до Nano та 36 В цей тракт не підключається. Схема охоплює його як окремий інтерфейс, але не підміняє невибраний кабель вигаданою розпайкою.

## X2: як точно визначити виходи ULN2003

[A] За [TI ULN2003A](https://www.ti.com/lit/ds/symlink/uln2003a.pdf): IN1 = ніжка U1 №1, OUT1 = №16; IN2 = №2, OUT2 = №15; GND = №8; COM захисних діодів = №9. **COM мікросхеми ULN не є GND** і не є COM механічного кінцевика.

[B] У [прикладеній до товару схемі LC Studio](https://arduino.ua/docs/SCH_StepperDriverULT2003.pdf) вихідний P3 має: 1 = VCC#, 2 = 1C, 3 = 2C, 4 = 3C, 5 = 4C. Перемичка P4.3–P4.4 з’єднує VCC з VCC#. Водночас фотографії товару показують іншу компоновку плати. Тому **номери P3 не переносити на білий роз’єм навмання**.

Перед обтиском майстер/продавець має знеструмити плату та позначити на реальному X2:

| Наш контакт | Перевірка мультиметром | Кінцеве підключення |
|---|---|---|
| V+ | Пряме з’єднання з входом «+» при встановленій штатній перемичці | Розгалуження на PUL+ / DIR+ |
| OUT1 | Пряме з’єднання з U1.16, канал IN1 | PUL− |
| OUT2 | Пряме з’єднання з U1.15, канал IN2 | DIR− |
| OUT3 | U1.14 | Не вставляти дріт або ізолювати кінець |
| OUT4 | U1.13 | Не вставляти дріт або ізолювати кінець |

Кандидат штекера — XH 5Y, Arduino.ua FCC253. Підтвердження кроку, ключа й посадки **на фактичній ARC109** ще потрібне: «XH 2.54» у каталозі не гарантує сумісність кожної ревізії. Замовляти плату разом із підібраним до неї джгутом. Не використовувати JST-SM/GH/SH як взаємозамінні. Відсутність підтвердженої орієнтації — причина спершу прозвонити джгут, а не виконувати пробне підключення живлення.

IN3/IN4 залишити без сигнальних кабелів; виходи не використовуються. Додаткові виходи/входи на варіанті 7-канальної плати теж вільні. Перемичка живлення має бути в стані, який дає на X2.V+ ті самі 5 В, що на вході «+»; вона не перетворює 5 В на 12 В.

## DM556, двигун і живлення

[B] [Інструкція з картки CNCPROM](https://storage.ua.prom.st/2369996_drajver_dm556._posibnik_koristuvacha.pdf), с. 4–6, 9: P1 — оптоізольовані PUL/DIR/ENA; P2 — живлення та фази. Застосовуємо відкритий колектор зі спільним плюсом 5 В. ENA+ і ENA− залишаються **обидва непідключені**, як у типовому варіанті інструкції. STOP означатиме припинення імпульсів, а не зняття утримувального струму.

[C] Не додаємо окрему землю між Nano й силовим GND DM556. Струм оптовходу повертається через ULN у USB GND. Штатні P1/P2 використовуємо як роз’ємні клемні блоки, якщо на отриманій ревізії вони знімні; не підбираємо випадкову зелену колодку лише за зовнішнім виглядом. Якщо блок незнімний, залишається від’єднання під гвинт — це також монтаж без паяння.

[B] Двигун [57BYG250C-8](https://cncprom.ua/ua/p1312688446-dvigatel-shagovyj-57byg250c.html) має **4 виводи**, 2 обмотки, номінал 3 А, 1,8° і заводські дроти приблизно 750 мм. Суфікс «-8» не означає 8 дротів. Кольори фаз не підтверджені: дві пари спочатку знайти омметром на від’єднаному моторі, підписати A1/A2/B1/B2; між різними обмотками з’єднання бути не повинно. Для подовження — 4×0,75 мм² [C], до 1 м, обидві жили кожної фази разом. Перший пуск без камери встановлює знак DIR.

[C] Параметри струму й DIP не переписувати з іншої моделі DM556. Узгодити 3 А двигуна з позначенням peak/RMS на отриманому драйвері, вибрати не вищий допустимого струм; мікрокрок зафіксувати для майбутньої прошивки. Для прикладу, 1600 імп/об при 72 мм/об дають 22,222 імп/мм; це проєктний розрахунок, не підтверджене налаштування.

[C] F1 — окремий запобіжник у плюсовій лінії 36 В біля БЖ. Початковий кандидат для підбору: 5 А, **DC-рейтинг не нижче 60 В**, із відповідним тримачем. Номінал остаточно визначається після вимірювання споживання/пуску та перевірки проводу; конкретний артикул ще не підібрано, його ціну не враховано. Не вважати звичайний автомобільний 32 V fuse придатним для 36 В.

Мережева частина [C]: готовий шнур із захисним контактом → L/N/PE S-250-36; PE → захисна клема/металевий корпус БЖ. Шнур, затиск оболонки, захист, закриття клем і підготовка 230 В залишаються послугою CNCPROM, як у вже надісланому запиті. Сигнальні конектори до цієї частини не застосовуються. 36 В не подавати на VIN/5V/GPIO Nano або на камеру.

## HOME і вимоги до майбутньої прошивки

- [C] COM → GND; NC → D4. NO вільний. Ненатиснутий справний контакт: LOW. Натиснутий або обірваний кабель: HIGH. Коротке замикання D4–GND такою схемою не діагностується.
- [C] Перед OUTPUT записати LOW у D2/D3. Перевірити відсутність STEP під час reset, відкриття COM-порту та відключення USB. На стенді виміряти оптовхід: запас рівнів після падіння на ULN/USB-кабелі не підтверджений лише кресленням.
- [B/C] Інструкція DM556 задає мінімум 2,5 мкс для високої/низької частини STEP та 5 мкс випередження DIR. Проєктний початок для стенда: STEP high/low ≥10 мкс, DIR setup/hold ≥10 мкс, потім перевірка осцилографом. Аналоговий PWM не заміняє керовану кількість кроків.
- [C] HOME: обмежений пошук, відпускання, повільний повторний підхід; кожна фаза має тайм-аут і максимум кроків. Якщо при старті HIGH — обмежений від’їзд з вимогою переходу LOW; якщо переходу немає — помилка, а не «нуль знайдено». Обробити брязкіт і запас до механічного упору.
- [C] STOP/втрата зв’язку припиняють STEP; після reset положення невідоме й потрібен HOME. Один кінцевик не контролює протилежний кінець. Пропущені кроки та падіння знеструмленої каретки схема не усуває.

## Паяння, обтиск і кабелеукладання

| Вузол | Робота |
|---|---|
| Nano APC104 | Купити саме з уже припаяними конекторами; знімні гнізда на пінах |
| ULN2003 ARC109 | Купити зібрану; вихід через підібраний 5P штекер |
| X2 | 3 задіяні обтиснуті контакти з 5; OUT3/4 без дротів; Y-розгалуження плюса з обтиснутою ізольованою гільзою |
| HOME | Дві жили з обтиснутими гніздами Nano та клемами під обраний вимикач; не вдягати Dupont на широку лопатку FASTON |
| DM556 / БЖ | Наконечники під фактичний тип/переріз клем; окреме розвантаження натягу |
| Якщо ULN прийшла без потрібних гребінок | Це інша комплектація: повернути/замовити підготовку; не заявляти її готовою без паяння |

[C] Dupont — короткі внутрішні сигнали, закріплені джгутом і затискачами, не силове чи рухоме з’єднання. Плати закріпити незалежно від кабелів. Двигун, драйвер, Nano та HOME нерухомі; у кабелеукладачі рухаються лише X6 USB, X7 DC камери й X8 sync. Радіус ланцюга не доводить допустимий радіус або ресурс кабелю.

## Приймання перед камерою на каретці

1. Без живлення: перевірити полярність, відсутність КЗ, X2 до U1.16/U1.15, обидві фази й замикання COM–NC. Перевірити тягою кожен обтиск.
2. Лише USB: перевірити 5 В на ULN і спільному плюсі оптовходів, стан HOME в обох положеннях; без 36 В перевірити STEP/DIR і reset.
3. Силова частина: прийняти підготовку БЖ/F1, фактичні клеми, струм і мікрокрок; під’єднання/від’єднання моторних дротів лише без живлення.
4. Стенд без камери, з підтриманою кареткою: знак DIR, HOME, обрив HOME, USB-disconnect, reset, перевірка нагріву та завад. Встановлення камери лише після механічної перевірки утримання, яка залишається відкритою в проєкті.

Це план перевірки, не запис успішних випробувань. Повністю готову до ввімкнення збірку ще не підтверджено.

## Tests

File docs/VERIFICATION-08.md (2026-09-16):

# Перевірка 08

- SHA256 оригіналу звірено; вихідний файл не перезаписувався.
- 62 авторські меші: усі вершини і Dimensions звірено з Blender, допуск порівняння 0,001 мм.
- Переглядач перевірено в Edge на ширині 1500 і 390 px: режими, ізоляція деталей, чотири розділи, помилки JavaScript і горизонтальне переповнення.
- PDF: 16 аркушів A3, включно з 13 авторськими панелями; вибрані аркуші відрендерено та оглянуто.
- Перевірка не є розрахунком міцності, повною перевіркою колізій, фотометрією або підтвердженням обслуговування обладнання.

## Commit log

2026-09-15 Publish the Revision 06 dashboard online.
    Package only the browser-ready dashboard, drawings, and reference assets so project sources remain local.
    [panel-contours.dxf]
2026-09-16 Publish the Revision 07 dashboard online: full cabinet from БУДКА.blend, printable PDF
2026-09-16 Fix revision 07 geometry: entry cutout, service vent grille, print output slots, camera view angles
2026-09-16 Fix entry wall (mirror side, not short front wall), add printer prices, move drawings under 3D view, rewrite project overview with live render
2026-09-16 Preserve author Blender geometry and publish revision 08 dashboard and drawings
    [panels.dxf, БУДКА-доповнена-08.blend, БУДКА.blend]
2026-09-17 Update author model, consolidated drawings, category budget and assembly presentation
    [БУДКА-доповнена-09.blend, БУДКА.blend]
2026-09-17 Update author model with 600 mm entrance and add profitability calculator
    [БУДКА-доповнена-10.blend, БУДКА.blend]
2026-09-17 Dimension cutouts on sheet 04 and add entrance curtain with mounting
    [БУДКА-доповнена-10.blend]
2026-09-20 Add reviewed 700 mm Canon lift with interactive 3D simulator and cost plan
2026-09-21 Publish current dashboard, camera wiring and assembly shopping
2026-09-27 Update purchase ledger and editable budget statuses
2026-09-27 Unify prototype budget and prepare portable Claude handoff
2026-09-27 Refresh browser assets for prototype release
